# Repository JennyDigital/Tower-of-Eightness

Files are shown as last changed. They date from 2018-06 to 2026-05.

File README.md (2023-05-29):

# Tower-of-Eightness

Welcome to my play project of a homebrew computer based on the 6502 CPU used in many many home computers of the 80's.  This isn't meant to be a guide to how you should build a 6502 based computer but it is meant to be fun and it does work.  I had never done one before so there's lots to improve upon I'm sure and I would love to hear of any exploits or builds similar to or the same as mine.

P.S.  I am planning to bring BBC BASIC to this system as it's sooooo good.

P.P.S.  I will be continuing to develop this machine for some time especially over weekends.

Have Fun!

*JenniferDigital.*

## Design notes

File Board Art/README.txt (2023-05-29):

This board art is only for the bottom side.  I'm eager to get my projects out fast and make my boards single sided (usually), adding links to the topside where neccesary for which the EAGLE files will let you see where they go.  Some of my newer boards can't easily be made single sided and as such may have to be fabricated with great care or many bodgewires.  Those boards don't have pre-made board mask art here, but the EAGLE files are included.

Have Fun,

Jennifer Gunn. x

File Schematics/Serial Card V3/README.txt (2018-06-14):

Serial Card V3
==============

Please note, this card is very much a work-in-progress!

I have not implemented any driver code for it whatsoever and may not have pushed all the updates to it's schematic.

IT MAY NOT WORK AT ALL!!

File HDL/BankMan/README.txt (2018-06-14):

Memory Board V2 Bank management logic.

Burn this to a GAL22V10 for the Memory board V2.

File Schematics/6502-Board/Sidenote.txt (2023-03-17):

For many people, this board will be essential.  If you go for the Motherboard V3.1 with it's integral CPU, you won't also want this card.  It makes no sense to have two processors fighting for the same bus.  There is no bus arbitration.

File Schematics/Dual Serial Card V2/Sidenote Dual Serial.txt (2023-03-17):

This is now the standard serial card as Tower OS has some builtin features for it and slots are at a premium.  TowerOS will still operate with a single ACIA and so will this card if you so desire, but two is definitely better than one in this case.

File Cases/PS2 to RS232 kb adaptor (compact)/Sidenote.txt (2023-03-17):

If your keyboard sips power at 300mA or less, or you use a switching 7805 replacement regulator, use this case, otherwise bet on the bigger one.  The bigger one was drawn with a newer version of FreeCAD too which might help if you plan on modifying it.

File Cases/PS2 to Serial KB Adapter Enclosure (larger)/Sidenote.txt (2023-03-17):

This is the bigger version.  Done this way to facilitate a larger heatsink for if your keyboard is somehow a power hog and you plump for the traditional linear regulator.  This one is also drawn with FreeCAD 20.2 which at the time of writing is quite new.

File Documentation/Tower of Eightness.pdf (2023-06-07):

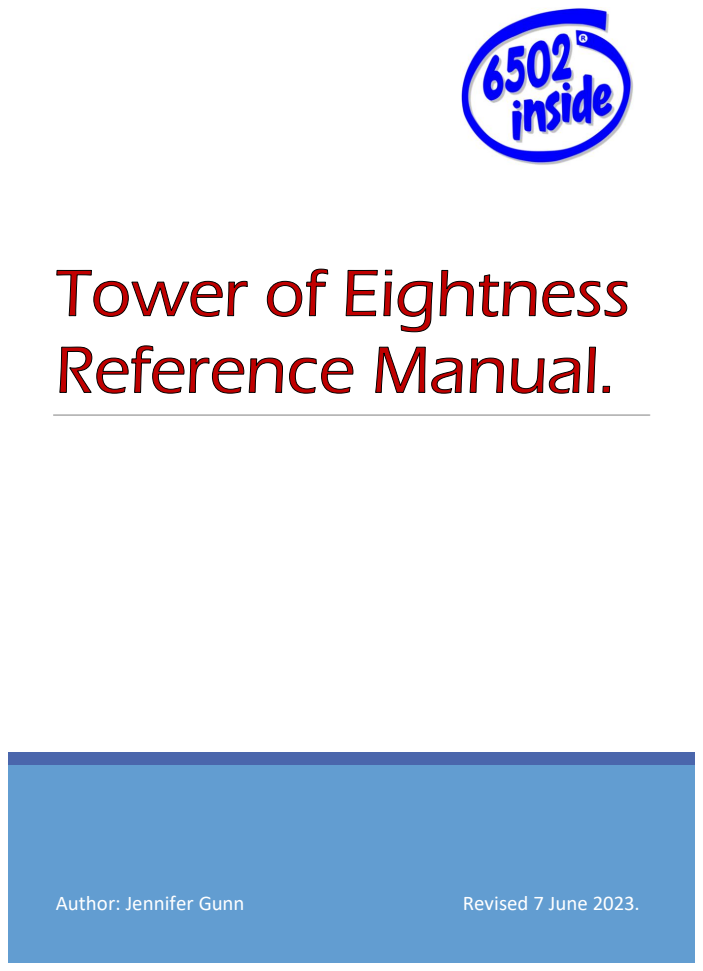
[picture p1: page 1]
Author: Jennifer Gunn; Revised 7 June 2023.

TOWER OF EIGHTNESS REFERENCE MANUAL.

### Table of Contents

TowerBASIC Commands for I2C communications | 82
List of I²C-Bus Subsystem Variables | 83
I2C_Status ($5D0) Bitfield | 83
I2C-Subsystem Calls | 83
Chapter 16. The SPI Sub-system | 84
SPI Subsystem Description | 85
TowerBASIC SPI Support | 86
Using the SPI engine | 87
SPI_Struct ($400-$408) | 87
List of SPI Function Calls | 87
Table of SPI Modes | 87
Appendices | 88
Appendix A. PC-DOS Character Set | 89
Appendix B. Display Layout | 90
80 Column Mode (Text) | 90
40 Column Mode (Text) | 90
Graphics (Bloxel Graphics) | 90
Appendix C. Video Control Codes | 91
Appendix D. Character Control Bits | 92
Character Control Attribute $18 (24) and bitfield of following byte | 92
Appendix E. ANSI Card Register Table | 93
Appendix F. Tower of Eightness Memory Overview | 94
Bank Structure and IOMAP oveview | 94
Bank Select Register Bitfield ($C0FF) | 94
Appendix G. AY Hardware Details | 95
AY-3-8912A Register Map | 95
Table of Bus States | 95
Envelope Shape/Cycle Operation | 96
Appendix H. Pinouts | 97
TowerBUS Pinout | 97
Centronics Port Pinout | 97
GPIO Card Port Pinouts | 97
ACIA Port Pinout | 98
Joystick Port Pinout | 98
AY Soundcard Output Jack Pinout | 98
Appendix I. W65C02 Instruction List | 99
Appendix J. Alphabetic List of TowerBASIC Commands | 101
BITCLR <addr>,<b> | 101
BITSET <addr>,<b> | 101
CALL <addr> | 101
CAT | 101
CLEAR | 101
CLS [<b>] | 101
CONT | 101
DATA [{r|$}[,{r|$}]…] | 102

DEC <var>,[<var>] | 102
DEF FN <name>(<var>)=<statement> | 102
DIM <var[$](i1[,i2[,in]…]) | 102
DO | 102
DOKE <addr,w> | 102
ELSE | 102
END | 103
ENVELOPE <period>,<mode> | 103
FN <name>(<expression>) | 103
FOR <var>=<expression> TO <expression> [STEP <expression>] | 103
GET <var[$]> | 103
GOSUB <n> | 103
GOTO <n> | 103
I2C_INIT | 105
I2C_START | 105
I2C_STOP | 105
IF <expression> {GOTO <n> [THEN <n|statement}>} [ELSE<{n|statement}>] | 105
INC <var>[,var] | 105
INPUT [“$”;]<var>[,<var>] | 105
LET <var>=<expression> | 106
LIST [n1][-n2] | 106
LOAD <expression$> [<expression>] | 106
LOCATE <expr1>,<expr2> | 106
LOOP [{UNTIL|WHILE} <expression>] | 106
NEW | 106
NEXT [var[,var]…] | 107
NOT <expression> | 107
NULL <n> | 107
ON <expression> {GOTO|GOSUB} <n>[,n] | 107
PLOT <expr1>,<expr2>,<expr3> | 107
POKE <addr,b> | 107
PRINT [<expression>][;|,}[expression]…[{;|,}] | 108
READ <var>[,<var>] | 108
REM | 108
RESTORE [n] | 108
RETURN | 108
RUN [n] | 108
SAVE <expression$> [<addr>,<size>] | 109
SOUND <channel>, <period>, <volume> | 109
SPC(<expression>) | 109
SPI_INIT <mode>,<MOSI_P>,<MISO_P>,<SCK_P>,<SS_P>,<SS_act> | 109
STEP | 109
SWAP <var[$]>,<var[$]> | 109
TAB(<expression>) | 110
THEN | 110
TO | 110
UNTIL | 110
VERIFY <filename$> [<addr>] | 110
WAIT <addr>,b1>[,b2] | 110
WHILE | 110
WIDTH {b1|,b2|b1,b2} | 111
Appendix K. List of Functions | 112
ABS(<expression>) | 112
ASC(<expression$>) | 112
ATN(<expression>) | 112
BIN$(<expression>[,b]) | 112

BITTST(<addr>,<b>) | 112
CHR$(b) | 112
COS(<expression>) | 112
DEEK(<addr>) | 112
EXP(<expression>) | 113
FRE(<expression>) | 113
HEX$(<expression>[,b]) | 113
I2C_IN(<b>) | 113
I2C_OUT(<b>) | 113
INT(<expression>) | 113
LCASE$(<expression$>) | 113
LEFT$(<expression$,b>) | 113
LEN(<expression$>) | 113
LOG(<expression>) | 114
MAX((<expression>[,<expression]…) | 114
MID$(<expression$,b1>[,b2]) | 114
MIN(<expression>[,<expression>]…) | 114
PEEK(<addr>) | 114
PI | 114
POS(<expression>) | 114
RIGHT$(<expression$,b>) | 114
RND(<expression>) | 115
SADD(<{var$|var$()}>) | 115
SGN(<expression>) | 115
SIN(<expression>) | 115
SPI_XFER(<b>) | 115
SQR(<expression>) | 115
STR$(<expression>) | 115
TAN(<expression>) | 115
TWOPI | 116
UCASE$(<expression$>) | 116
USR(<expression>) | 116
VAL(<expression$>) | 116
VARPTR(<var[$]>) | 116
Appendix L. List of Error Messages | 117
Array bounds Error | 117
Break | 117
Can’t continue Error | 117
Divide by zero Error | 117
Double dimension Error | 117
Extra ignored (INPUT warning) | 117
Filename too Long | 117
Function call Error | 118
Header Error. Retrying | 118
Illegal direct Error | 118
LOOP without DO Error | 118
NEXT without FOR Error | 118
Out of DATA Error | 118
Out of memory Error | 118
Overflow Error | 119
Redo from start | 119
RETURN without GOSUB Error | 119
String too complex Error | 119
String too long Error | 119
Syntax Error | 119
Tape loading Error | 119

# Chapter 0. Introduction to

the Tower of Eightness.

### Welcome

You are now the proud owner of one of the most trailing edge pieces of technology. This sophisticated, versatile, and very capable engineering tool/toy is built for those with a need to play around, make and learn unimpeded by modern technologies closed-off and locked down architectures.

The Tower of Eightness has despite its trailing edge tech, enough capability to run an office, teach the basics of robotics, play games etc. The power is within you to make it do great things. Everything is documented where possible in order to make it the tinkerers heaven. There is just one thing I ask of you. When you make something beautiful, share it!

### A Guided tour

First, let’s learn the pieces. The main unit consists of a 3D printed modular case which houses the backplane, of which there are versions with and without the W65C02S6-TPG14 Central Processing Unit and system clock generator. The W65C02S6-TPG14 is the beating heart of the system, and it can be considered to be its brain.

Then there is the memory card. On this card is 96 Kibibytes of RAM in three banks of 16 Kibibytes by 2 pages wide. At the top of memory space are two pages of ROM each also of 16 Kibibytes. This is where TowerOS, TowerBASIC and TowerTAPE FS live. This card is an essential without which the computer will not operate. It is recommended that this sits in the top slot if one intends to make frequent changes to the ROM.

Next up is the GPIO card. You need at least one of these to use TowerTAPE FS, SPI or I

2C facilities. The first one should always be at $C020 base address.

Either an ACIA card or a dual ACIA card (recommended) is needed to provide one or more serial ports. All keyboard input is initially routed through the first serial port and on systems’ that don’t have some form of VDU output, this is how one sees the computers output.

In most cases you’ll want a video output with some form of graphics, for this there is the ANSI video output card. With this, you’ll be able to enjoy 80 columns output, a full PCDOS character set and some limited graphics capability. This card outputs either PAL or NTSC timed monochrome composite synch video.

Do you want to make some noise!!? Good, there’s a soundcard based on the AY-3-8912A sound chip for that. It has a single stereo 3.5mm jack with line level output on it.

How about printing? For that there is the Centronics and Tower Peripheral Bus card. The printer port is especially useful. The Tower Peripheral Bus hardware is all there, but the firmware is a work in progress.

There is an up-and-coming much faster solid state storage card, this will operate with far greater reliability and speed than tape.

### Getting Up and Running

Firstly, we need power. On the back is a 2.1mm power jack that accepts anything from 8 to 12VDC positive tip with at least 1A. Whilst the computer itself doesn’t use all that, peripherals and future upgrades might. Plug that in but don’t switch the computer on just yet.

Now, connect the ACIA port 1 to either a terminal/terminal emulator or the PS2 keyboard interface with the appropriate lead. For connecting to the keyboard interface, use the supplied SC1-K1 serial cable. It only fits one way round. For use with the terminal/terminal emulator you will need to make up a custom cable using the data in one of the ACIA adapter chapters. If using the PS2 to Keyboard adapter, you will need to supply power to that also. See the PS2 to Keyboard Adapter User Guide for further guidance there. We now have a way to type commands into the computer and if using it with a terminal, also see the output.

It is strongly recommended that you use the ANSI card with a composite capable display device. This wat you can enjoy its extra benefits. The output on that card is a single yellow RCA jack. This outputs either 50 or 60Hz monochrome video compatible with many modern television sets that support PAL or NTSC.

Should you wish to use TowerTAPE FS then you should now use a short and I do mean short 20-way ribbon cable to connect port B of the first GPIO card to the tape and joystick interface. This also supplies power to the tape and joystick interface, so you won’t need yet another power supply.

These are considered the base options for the Tower of Eightness. Some might say sound is a base option, but that very much depends on your point of view. Now we can flip the power switch!

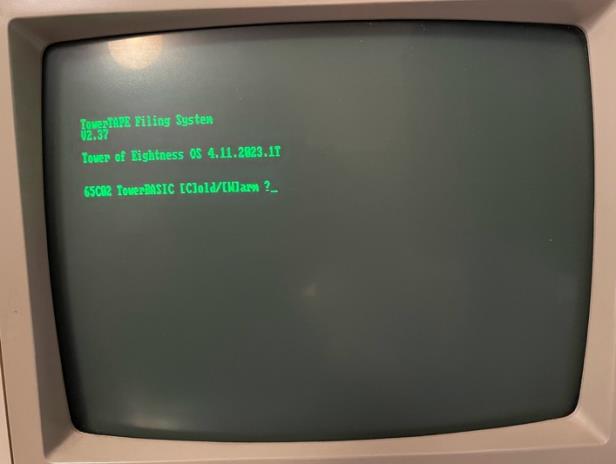
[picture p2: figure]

When starting from power-up you must always choose [C]old by pressing C. You will then be prompted to enter an amount of memory. For now just press [ENTER] and let the computer decide. This will drop you into TowerBASIC.

Let the adventure begin!

Figure 1 ToE Boot-screen

Let’s get stuck in shall we? Good, TowerBASIC is a close fork of EhBASIC, it is therefore derived from EhBASIC, and due respect should be paid to its original and late author Lee Davidson. It is free to use but not copyright free. He would hate to see people abusing the spirit and intention of his work, so please don’t. Now with that out of the way, BASICs of this type have a few things in common.

First, there are keywords such as PRINT, IF and LET which will appear throughout this manual as they do here. Take the following example for instance: -

### 10 PRINT “Hello world!”¶ 20 GOTO 10¶

Typing this and then RUN¶ tells the computer to print Hello world! repeatedly down the screen. To stop it doing so press escape or [Control]C, from now on shown ^C.

The numbers at the start of each line tell the computer where to put them in relation to each other, and each line is followed in numerical order. If you type a new line in with the same number, it replaces any existing one of the same line number with the new line. Try changing the message in the quotes on line 10 and see what happens!

Where you see PRINT that command prints whatever is between the quotes.

Line 20 does something different. It is an instruction to start running commands from the number following the GOTO command. In this simple form it must be followed by a line number that must exist or the computer will stop running your program with an Undefined statement Error.

Congratulations, you’ve just run your first program!

It would be a shame to have to type in an entire program consisting of many many lines of carefully crafted code, so connect your Tower of Eightness up to a tape recorder and whenever you have created something you’d rather not loose, just find a good spot on a tape, press record and type SAVE “<filename>”¶

When the computer has done saving you’ll be greeted by the Ready prompt and be able to continue on with your day. Getting your program back is as simple as finding the right spot and typing LOAD ”<optional filename>”¶, and playing the tape back. It may take a while to find the sweet spot on your tape recorders volume dial to get reliable loading of saved programs. Please refer to the chapter on the Tape and Joystick Interface for a fuller understanding.

### Variables and Math

So, computers are often insulted as being overgrown calculators, and whilst this is not true, they definitely owe their roots to the efforts of mathematicians and engineers.

The Tower of Eightness is quite capable of performing calculations with great speed and ease. Just to give you a taste, let’s explore this a little.

Let us consider the following program: -

### 10 LET a=4 20 LET b=3 30 PRINT a*b

Upon being RUN this program produces the result 12. Nothing remarkable you might say, but the devil is in the detail for computers don’t work in human numbers (decimal), they work in binary (noughts and ones, also known as base 2).

Line 10 assigns the variable ‘a’ with the value 4, whenever the computer then needs to use that number, you can use ‘a’ instead. In fact, you can change the contents of a whenever you like and even assign it the results of a previous calculation. The computer is taking an equation, in this case a times b and PRINTing the result.

Line 20 is doing the same for the variable b, but not b=3.

Line 30 both performs the calculation and prints the result for the user to see.

For the Tower of Eightness, this was a trivial calculation that took such a short time I bet you didn’t even perceive it. The computer has a good selection of operators.

It can add (+), subtract (-), multiply (*), divide (/), raise to a power (^) and much, much more. The TowerBASIC Reference Manual gives a full list of operators and functions to assist the programmer in making use of the computers calculating capability.

There are also string variables, and arrays of variables can exist as well.

Any variable name that ends in s ‘$’ symbol is a string variable. Strings are any number of characters one after another and can have some limited operations after them. We shall just briefly touch upon them here. To know more, refer to the TowerBASIC Reference Manual.

N$=”<Yourname>”
PRINT “Hello “;N$;”. It’s jolly nice to meet you!”

### Using the PRINT Command

You’ve seen PRINT in use already, but did you know, it can do more? In fact, when properly used, it can do most of what you might want to do with the Tower of Eightness display. Its purpose is more fully realised when you know the PC-DOS character set and special control codes that give it the ability to draw pixels, double height, double width, bold or otherwise characters sets and even change the number of columns on the screen.

PRINT can exist on its own to move down the screen by one line:-

### 10 PRINT “MENU” 20 PRINT 30 PRINT “Spam and eggs” 40 PRINT “Spam and chips” 50 PRINT “Spam, spam, spam, wonderful Spam!!”

PRINT can print multiple things together!

### 10 LET a=9 20 PRINT “The square root of”;a;” is”;SQR(a)

which yields the result of ‘The square root of 9 is 3‘ when run. We’ve also just encountered a function SQR() which returns the square root of whatever is in the parentheses. There are many such functions.

One such function especially useful with PRINT is CHR$(). It takes a number from 0 to 255 and passes the result as a single character. If you look at the PC-DOS character set, listed at the back of this manual, you will see that each and every character has a unique number associated with it, and better yet, there’s also a whole bunch of fancy symbols to play with as well! A word of caution though, it is quite possible to get the screen in a terrible mess whilst exploring this, so don’t forget that if you press the reset button and choose [W]arm start, you’ll have a nice readable display to call home again.

PRINT can also produce columnated figures. Try the following: -

PRINT 1,2,3,4

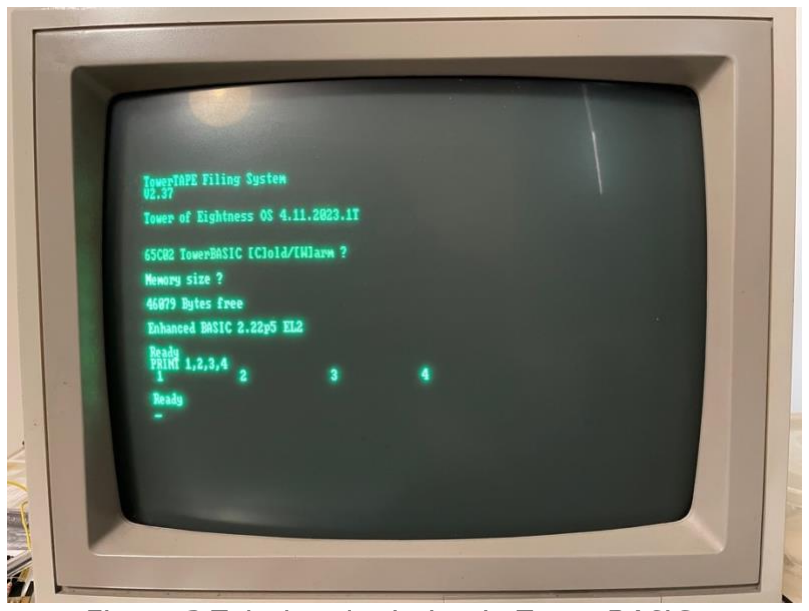
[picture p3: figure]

Figure 2 Tabulated printing in TowerBASIC.

As you can see from the above image, there are fixed tabs where the numbers appear. This is useful for making your information sit more readably and presentably.

There are a couple of useful functions for moving whatever you print along too. Following the print statement or after a ‘,’ or ‘;’ within the PRINT statement, you can include either a SPC(x) or TAB(x) function where x is a positive numeric value.

SPC(x) works by moving the print position x characters along, but TAB(x) attempts to get to column x so long as that column hasn’t already been passed.

Finally, if you end your print statement with a semicolon, a carriage return is not issued. That is to say that the next thing starts immediately after the last print.

Chapter 1. The Zero Page.

### Tower of Eightness Zero Page Usage

LAB_WARM | $00 | BASIC warm start entry point
Wrmjpl | $01 | BASIC warm start vector jump low byte
Wrmjph | $02 | BASIC warm start vector jump high byte
Usrjmp | $0A | USR function JMP address
Usrjpl | $0B | USR function JMP vector low byte
Usrjph | $0C | USR function JMP vector high byte
Nullct | $0D | nulls output after each line
TPos | $0E | BASIC terminal position byte
TWidth | $0F | BASIC terminal width byte
Iclim | $10 | Input column limit
Itempl | $11 | Temporary integer low byte
Itemph | $12 | Temporary integer high byte
nums_1 | $11 | Number to bin/hex string convert MSB
nums_2 | $12 | Number to bin/hex string convert
nums_3 | $13 | Number to bin/hex string convert LSB
Srchc | $5B | Search character
Temp3 | $5B | Temp byte used in number routines
Scnquo | $5C | Scan-between-quotes flag
Asrch | $5C | Alt search character
XOAw_l | $5B | eXclusive OR, OR and word low byte
XOAw_h | $5C | eXclusive OR, OR and AND word high byte
Ibptr | $5D | Input buffer pointer
Dimcnt | $5D | # of dimensions
Tindx | $5D | Token index
Defdim | $5E | Default DIM flag
Dtypef | $5F | Data type flag, $FF=string, $00=numeric
Oquote | $60 | Open quote flag (b7) (Flag: DATA scan; LIST quote;
| | memory)
Gclctd | $60 | Garbage collected flag
Sufnxf | $61 | Subscript/FNX flag, 1xxx xxx = FN(0xxx xxx)
Imode | $62 | Input mode flag, $00=INPUT, $80=READ
Cflag | $63 | Comparison evaluation flag
TabSiz | $64 | TAB step size (was input flag)
next_s | $65 | Next descriptor stack address

These two bytes form a word pointer to the item currently on top of the descriptor stack.

last_s | $66 | Last descriptor stack address low byte
last_sh | $67 | Last descriptor stack address high byte (always $00)
des_sk | $68 | Descriptor stack start address (temp strings)

| $70 | End of descriptor stack
ut1_pl | $71 | Utility pointer 1 low byte
ut1_ph | $72 | Utility pointer 1 high byte
ut2_pl | $73 | Utility pointer 2 low byte
ut2_ph | $74 | Utility pointer 2 high byte
Temp_2 | $71 | Temp byte for block move
FACt_1 | $75 | FAC temp mantissa1
FACt_2 | $76 | FAC temp mantissa2
FACt_3 | $77 | FAC temp mantissa3
dims_l | $76 | Array dimension size low byte
dims_h | $77 | Array dimension size high byte
TempB | $78 | Temp page 0 byte
Smeml | $79 | Start of mem low byte (Start-of-Basic)
Smemh | $80 | Start of mem high byte (Start-of-Basic)
Svarl | $7B | Start of vars low byte (Start-of-Variables)
Svarh | $7C | Start of vars high byte (Start-of-Variables)
Sarryl | $7D | Var mem end low byte (Start-of-Arrays)
Sarryh | $7E | Var mem end high byte (Start-of-Arrays)
Earryl | $7F | Array mem end low byte (End-of-Arrays)
Earryh | $80 | Array mem end high byte (End-of-Arrays)
Sstorl | $81 | String storage low byte (String storage (moving down))
Sstorh | $82 | String storage high byte (String storage (moving down))
Sutill | $83 | String utility ptr low byte
Sutilh | $84 | String utility ptr high byte
Ememl | $85 | End of mem low byte (Limit-of-memory)
Ememh | $86 | End of mem high byte (Limit-of-memory)
Clinel | $87 | Current line low byte (Basic line number)
Clineh | $88 | Current line high byte (Basic line number)
Blinel | $89 | Break line low byte (Previous Basic line number)
Blineh | $8A | Break line high byte (Previous Basic line number)
Cpntrl | $8B | Continue pointer low byte
Cpntrh | $8C | Continue pointer high byte
Dlinel | $8D | Current DATA line low byte
Dlineh | $8E | Current DATA line high byte
Dptrl | $8F | DATA pointer low byte
Dptrh | $90 | DATA pointer high byte
Rdptrl | $91 | Read pointer low byte
Rdptrh | $92 | Read pointer high byte
Varnm1 | $93 | Current var name 1st byte

Varnm2 | $94 | Current var name 2nd byte
Cvaral | $95 | Current var address low byte
Cvarah | $96 | Current var address high byte
Frnxtl | $97 | Var pointer for FOR/NEXT low byte
Frnxth | $98 | Var pointer for FOR/NEXT high byte
Tidx1 | $97 | Temp line index
Lvarpl | $97 | Let var pointer low byte
Lvarph | $98 | Let var pointer high byte
Prstk | $99 | Precedence stacked flag
comp_f | $9B | compare function flag, bits 0,1 and 2 used
| | Bit 2 set if >
| | Bit 1 set if =
| | Bit 0 set if <
func_l | $9C | Function pointer low byte
func_h | $9D | Function pointer high byte
garb_l | $9C | Garbage collection working pointer low byte
garb_h | $9D | Garbage collection working pointer high byte
des_2l | $9E | String descriptor_2 pointer low byte
des_2h | $9F | String descriptor_2 pointer high byte
g_step | $A0 | Garbage collect step size
Fnxjmp | $A1 | Jump vector for functions
Fnxjpl | $A2 | Functions jump vector low byte
Fnxjph | $A3 | Functions jump vector high byte
g_indx | $A2 | Garbage collect temp index
FAC2_r | $A3 | FAC2 rounding byte
Adatal | $A4 | Array data pointer low byte
Adatah | $A5 | Array data pointer high byte
Nbendl | $A4 | New block end pointer low byte
Nbendh | $A5 | New block end pointer high byte
Obendl | $A6 | Old block end pointer low byte
Obendh | $A7 | Old block end pointer high byte
Numexp | $A8 | String to float number exponent count
Expcnt | $A9 | String to float exponent count

Numbit | $A8 | Bit count for array element calculations
Numdpf | $AA | String to float decimal point flag
Expneg | $AB | String to float eval exponent -ve flag
Astrtl | $AA | Array start pointer low byte
Astrth | $AB | Array start pointer high byte
Histrl | $AA | Highest string low byte
Histrh | $AB | Highest string high byte
Baslnl | $AA | BASIC search line pointer low byte
Baslnh | $AB | BASIC search line pointer high byte
Fvar_l | $AA | Find/found variable pointer low byte
Fvar_h | $AB | Find/found variable pointer high byte
Ostrtl | $AA | Old block start pointer low byte
Ostrth | $AB | Old block start pointer high byte
Vrschl | $AA | Variable search pointer low byte
Vrschh | $AB | Variable search pointer high byte
FAC1_e | $AC | FAC1 exponent
FAC1_1 | $AD | FAC1 mantissa1
FAC1_2 | $AE | FAC1 mantissa2
FAC1_3 | $AF | FAC1 mantissa3
FAC1_s | $B0 | FAC1 sign (b7)
str_ln | $AC | String length
str_pl | $AD | String pointer low byte
str_ph | $AE | String pointer high byte
des_pl | $AE | String descriptor pointer low byte
des_ph | $AF | String descriptor pointer high byte
mids_l | $AF | MID$ string temp length byte
negnum | $B1 | String to float eval -ve flag
numcon | $B1 | Series evaluation constant count
FAC1_o | $B2 | FAC1 overflow byte
FAC2_e | $B3 | FAC2 exponent
FAC2_1 | $B4 | FAC2 mantissa1
FAC2_2 | $B5 | FAC2 mantissa2
FAC2_3 | $B6 | FAC2 mantissa3
FAC2_s | $B7 | FAC2 sign (b7)
FAC_sc | $B8 | FAC sign comparison, Acc#1 vs #2
FAC1_r | $B9 | FAC1 rounding byte

ssptr_l | $B8 | String start pointer low byte
ssptr_h | $B9 | String start pointer high byte
sdescr | $B8 | String descriptor pointer
csidx | $BA | Line crunch save index
Asptl | $BA | Array size/pointer low byte
Aspth | $BB | Array size/pointer high byte
Btmpl | $BA | BASIC pointer temp low byte
Btmph | $BB | BASIC pointer temp low byte
Cptrl | $BA | BASIC pointer temp low byte
Cptrh | $BB | BASIC pointer temp low byte
Sendl | $BA | BASIC pointer temp low byte
Sendh | $BB | BASIC pointer temp low byte
LAB_IGBY | $BC | Get next BASIC byte subroutine
LAB_GBYT | $C2 | Get current BASIC byte subroutine
Bpntrl | $C3 | BASIC execute (get byte) pointer low byte
Bpntrh | $C4 | BASIC execute (get byte) pointer high byte
| $D7 | end of get BASIC char subroutine
Rbyte4 | $D8 | Extra PRNG byte
Rbyte1 | $D9 | Most significant PRNG byte
Rbyte2 | $DA | Middle PRNG byte
Rbyte3 | $DB | Least significant PRNG byte
| $DC | unused
| $DD | unused
| $DE | unused
| $DF | unused
| $E0 | unused
| $E1 | unused
| $E2 | TPB card temporary location
| $E3 | TPB card temporary location
| $E4 | TAPE temporary location
| $E5 | TAPE_BlockLo
| $E6 | TAPE_BlockHi
| $E7 | TOE_MemptrLo low byte general purpose pointer
| $E8 | TOE_MemptrHi high byte general purpose pointer
| $E9 | unused
| $EA | unused
| $EB | unused
| $EC | unused
| $ED | unused
| $EE | unused

Decss | $EF | Number to decimal string start
Decssp1 | $F0 | Number to decimal string start
| $FF | Decimal string end

Chapter 2. OS Memory Map.

### TowerBASIC Non-Zero Page Memory

Operating systems memory is necessary, or the OS would not work. Some benefit to the user is afforded by the clear documentation of this memory below.

$200 | ccflag | Control-C flag. 0=Enabled, 1=Disabled.
$201 | ccbyte | Control-C character. One may define whatever
| | one chooses, but with great power comes great
| | RESETs!
$202 | ccnull | Timeout time for the Control-C character.
$203-$204 | VEC_CC | Control-C check vector.
$205-$206 | VEC_IN | TowerBASIC Input vector.
$207-$208 | VEC_OUT | TowerBASIC output vector.
$209-$20A | VEC_LD | TowerBASIC LOAD vector.
$20B-$20C | VEC_SV | TowerBASIC SAVE vector.
$20D-£20E | VEC_VERIFY | TowerBASIC VERIFY vector.

THE Next two vectors (Greyed out) are no longer in use.

$F9F3-$F9F4 | IRQ_vec | Interrupt ReQuest vector. (Currently patched out,
| | see Chapter 12, The IRQ Sub-System.)
$20F-$210 | NMI_vec | Non Maskable Interrupt vector.

### ToE Monitor Top Level Component Memory

$5E0 | os_outsel | Output stream selection bitfield. See table at end of
| | chapter.
$5E1 | os_infilt | Input stream filter selection bitfield. See table at end
| | of chapter.
$5E2 | os_insel | This variable contains an input stream selection bit.
| | The bitfield allows you to select which source you
| | want to use, with invalid selections causing a
| | return to ACIA1.

### ToE ACIA Configuration Variables

$5E3 | ACIA1_cfg_cmd | The load values for configuring ACIA1’s command
| | register upon initialisation.
$5E4 | ACIA1_cfg_ctrl | The load values for configuring the ACIA1’s control
| | register upon initialisation.
$5E5 | ACIA2_cfg_cmd | The load values for configuring ACIA2’s command
| | register upon initialisation.
$5E6 | ACIA2_cfg_ctrl | The load values for configuring ACIA2’s command
| | register upon initialisation.

### ToE I2C Engine Variables

$5D0 | I2C Status | Stores the status of the I2C engine including the
ACK/NAK bit.
$5D1 | I2C_Byte | This is the data register for the I2C engine.

### Tower Peripheral Bus Memory Locations

$5F2 | TPB_curr_dev | TPB Currently selected device ID.
$5F3 | TPB_dev_type | TPB device type.
$5F4 | TPB_last_read | Last read byte from the TPB bus.
$5F5 | TPB_BUS_status | Status word for the TPB bus. Subject to change.
$5F6 | TPB_BUS_tries | Bus device counter, this ensures fewer hangs.
$5F7 | TPB_BUS_lim | Bus countdown timer limit. (Reload value).
$5F8 | TPB_BUS_lenlo | Low byte of the length of the block in or out.
$5F9 | TPB_BUS_lenhi | High byte of the length of the block in or out.
$5FA | TPB_BUS_stlo | Low byte of the start of the block in or out.
$5FB | TPB_BUS_sthi | High byte of the start of the block in or out.
$5FC | TPB_BUS_blk_type | Type of block transfer. See Table below.
$600 | TPB_Dev_table | Device descriptor table.
$610-$6FF | TPB_BUS_IO_buff | Buffer for IO operations on the TPB bus.
$700-$7FF | TPB_BUFFER | Buffer for TPB block operations.

TowerTAPE Filing System Memory.

$900-$901 | V_TAPE_BlockSize | Size of block to transfer to or from tape.
$902 | TAPE_Temp2 | Temporary memory location for TFS
internals.
$903 | TAPE_Temp3 | Temporary memory location for TFS
internals.
$904 | TAPE_Temp4 | Temporary memory location for TFS
internals.
$905 | TAPE_LineUptime | Number of passes the tape system
superloop has made since the tape line rose.
$906 | TAPE_Demod_Status | Demodulated bit status.
$907 | TAPE_Demod_Last | Previous demodulated bit status.
$908 | TAPE_StartDet | Start bit detection status.
$909 | TAPE_RX_Status | Receive engine status bitfield.
$90A | TAPE_BitsToDecode | Down counter of remaining bits to
decode.
$90B | TAPE_ByteReceived | Last byte received by the TFS.
$90C | TAPE_Sample_Position | Countdown timer for bit engine sample
synchronization.

$90D | TAPE_BlockIn_Status | Status register for the F_TAPE_BlockIn
function.
$90E-929 | TAPE_Header_Buffer | This is where the tape header information
is stored for use when SAVEing and LOADing.
$92A | TAPE_CS_AccLo | Tape checksum accumulator low byte.
$92B | TAPE_CS_AccHi | Tape checksum accumulator high byte.
$92C | V_TAPE_Phasetime | Tape phase time variable.

The following variables are allocated for future upgrades to the tape system and ignored for now.

$92D | V_TAPE_Sample_Offset | Sample offset variable. This determines
how far into a bit the sample is taken.
$92E | V_TAPE_Bitlength | How many bits in a word stored on
tape.
$92F | V_TAPE_bitcycles | Number of cycles of the super-loop to a
bit.
$930 | V_TAPE_Verify_Status | Stores the verify status bits used by the
TAPE_VERIFY_vec ($FF7E)
$931-$942 | V_TAPE_Fname_Buffer | Working file name buffer. Stores the
null terminated file name specified in LOAD, SAVE and VERIFY commands.
$943 | V_TAPE_LOADSAVE_Type | Temporary store of what file type is
being worked on by the TAPE file system.
$944-$945 | V_TAPE_Address_Buff | Temporary store of the starting address
being worked on by the TAPE file system.
$946-$947 | V_TAPE_Size_Buff | Temporary store of how big the file
being worked on is.
$948 | V_TAPE_Config | TowerTAPE Filing system configuration
word.
$949-$94B | TAPE_KBD_vec | This stores a JMP, and the address of the
routine needed to check for break to BASIC. This is set whenever a block read operation occurs. The user must change this whenever the input stream is changed and a call is made to F_TAPE_GetByte. This is done by calling F_TAPE_SetKbd_vec ($FFBA)

### AY Soundcard V2 Memory Locations

$A00 | AY_Reg | Register to write to
$A01-$A02 | AY_Data | Contents to be transferred between the
system and the AY-3-8912A when
calling | AY_Userwrite_vec | ($FFD5),

AY_Userwrite_16_vec | ($FFCF),
AY_Userread_vec | ($FFD8) | or
AY_Userread_16_vec ($FFD2).
$A03 | AY_Mask | Contains the shadow copy of the
enable bits for the AY-3-8912A sound channels.
$A04 | AY_Channel | Contains a shadow copy of the channel
specified in the BASIC command SOUND.
$A05-$A06 | AY_Period | Contains a shadow copy of the period
specified in the BASIC command SOUND.
$A07 | AY_Volume | Contains a shadow copy of the volume
specified in the BASIC command SOUND.
$A08-$A09 | AY_Envelope_Period | Contains a shadow copy of the
envelope period specified in the BASIC command ENVELOPE.
$A0C | AY_Envelope_Mode | Contains a shadow copy of the
envelope | mode | specified | in | the
TowerBASIC command ENVELOPE.

### IRQ Handler Subsystem Locations

$A20-$A2F | IRQH_CallList | Table of 8 addresses for the IRQ
Handlers
$A30-$A31 | IRQH_CallReg | Address being worked on by set or clear
calls.
$A32 | IRQH_ClaimsList | bitfield showing which IRQ’s claimed an
interrupt. LSb is IRQ0, MSb is IRQ7
$A33 | IRQH_MaskByte | Selection switch for interrupts. 1 means
on and the order is LSb for IRQ0 through MSb for IRQ7.
$A34 | IRQH_WorkingMask | Used internally when enumerating
IRQs.
$A35 | IRQH_CurrentEntry | Convenience variable informing IRQs
etc which IRQ is currently being handled.
$A36-$A46 | IRQH_Command_Table | 16-byte table consisting of a parameter
followed by the command code. Ordered by ascending IRQ number.

### Countdown Timer IRQ Locations

$A4A-$A4B | CTR_V | Counter. This is the countdown timer’s
present value, decremented each GPIO card Timer 1 IRQ.
$A4C-$A4D | CTR_RELOAD_VAL_V | Counter reload value. Reloads only if
CTR_Reload_En bit (b0) of CTR_Options ($A52) is set.

$A4E-$A4F | CTR_PERIOD_V | Counter period. This is determined to
| | be counted down by one every PHI2
| | clock and after reaching 0 triggers an
| | interrupt that decrements the CTR_V
| | ($A4A-$A4B). Caution, Do not set this
| | extremely low or your computer may
| | become unresponsive.
$A50-$A51 | CTR_External_vec | Contains the address of any call you
| | wish to service upon CTR_V reaching 0.
| | Load this before enabling it which is
| | done by setting CTR_vec_En bit (b1) of
| | CTR_Options ($A52)
$A52 | CTR_Options | Bitfield containing flag bits controlling
| | behaviour of the Countdown timer.

### System Vector Locations

$FF60 | TOE_PrintStr_vec | Prints a null terminated string to the
| | currently selected outputs.
$FF63 | TAPE_Leader_vec | Generates a tape leader signal.
$FF66 | TAPE_BlockOut_vec | Transmits a block of bytes.
$FF69 | TAPE_ByteOut_vec | Transmits a byte.
$FF6C | TAPE_BlockIn_vec | Reads a block of bytes from tape.
$FF6F | TAPE_ByteIn_vec | Reads a byte from tape.
$FF72 | TAPE_init_vec | Initialises the tape system.
$FF75 | TAPE_CAT_vec | Continually scans the tape, outputting
| | the filename and type of any found files.
$FF78 | TAPE_SAVE_BASIC_vec | SAVEs a program to tape.
$FF7B | TAPE_LOAD_BASIC_vec | LOADs a program from tape.
$FF7E | TAPE_F_TAPE_VERIFY_BASIC | VERIFYs a program in memory against
| | what is stored on tape. Can be accessed
| | from TowerBASIC using the VERIFY
| | command.
$FF90 | ANSI_init_vec | Initialises the ANSI card.
$FF93 | ANSI_write_vec | Writes whatever is in the accumulator to
| | the ANSI card.
$FF96 | TPB_init_vec | Initialises the Tower Peripheral Bus card.
$FF99 | TPB_LPT_write_vec | Writes the contents of A to the
| | Centronics port.
$FF9C | TPB_tx_byte_vec | Writes a byte to the tower peripheral
| | bus.
$FF9F | TPB_block_vec | Writes a block of bytes to the tower
| | peripheral bus.
$FFA2 | TPB_ATN_handler_vec | Processes ATN signals generated by TPB
| | peripherals.
$FFA5 | TPB_rx_byte_vec | Reads a byte from the TPB bus.
$FFA8 | TPB_rx_block_vec | Reads a block from the TPB bus.

$FFAB | TPB_Dev_Presence_vec | Checks for the presence of a given
device on the bus.
$FFAE | TPB_Req_Dev_Type_vec | Requests the device report its device
type.
$FFB1 | TPB_dev_select_vec | Selects a device on the TPB. A device
must not respond unless selected.
$FFB4 | TPB_Ctrl_Block_Wr_vec | Writes to a devices control block.
$FFB7 | TPB_Ctrl_Block_Rd_vec | Reads a devices control block.
$FFCF | AY_Userwrite_16_vec | Writes to the specified AY register and
its consecutive register.
$FFD2 | AY_Userread_16_vec | Reads from the specified AY register and
its consecutive register.
$FFD5 | AY_Userwrite_vec | Writes to the specified AY register.
$FFD8 | AY_Userread_vec | Reads from the specified AY register.
$FFDB | IRQH_Handler_Init_vec | Initialises the IRQ Handler sub-system.
$FFDE | IRQH_SetIRQ_vec | Atomically sets an IRQ address in the
handler table.
$FFE1 | IRQH_ClrIRQ_vec | Atomically clears an IRQ to the null IRQ
handler in the specified handler table.
$FFE4 | IRQH_SystemReport_vec | Returns the IRQ Handler subsystem
version and base address of the handler data structure.
$FFE7 | INIT_COUNTDOWN_IRQ | Initialises the countdown timer IRQ.

### CPU Vectors (CPU hard-wired)

$FFFA | NMI_vec | Non-Maskable-Interrupt vector.
$FFFC | RES_vec | Reset vector. This is the reset vector. The
CPU takes the address here as it’s start point.
$FFFE | IRQ_vec | Interrupt request vector. | IRQ’s jump
| | from here.

### System Soft-Switches

System soft switches are bits stored within system variables that control characteristics of the system such as output streams and input filtering. This section is likely to grow with revision changes.

### os_outsel ($5E0)

Bit | 7 | 6 | 5 | 4 | 3 | 2 | 1 | 0
Function | Reserved for future uses. | | | | ACIA2 | TPB LPT | ANSI | ACIA1

### os_infilt ($5E1)

Bit | 7 | 6 | 5 | 4 | 3 | 2 | 1 | 0
Function | Reserved for future uses. | | | | | | ACIA2 LF Filter | ACIA1 LF Filter.

### os_insel ($5E2)

Bit | 7 | 6 | 5 | 4 | 3 | 2 | 1 | 0
Function | Reserved for future uses. | | | | ACIA2 | Reserved | | ACIA1

Chapter 3. The ANSI Card.

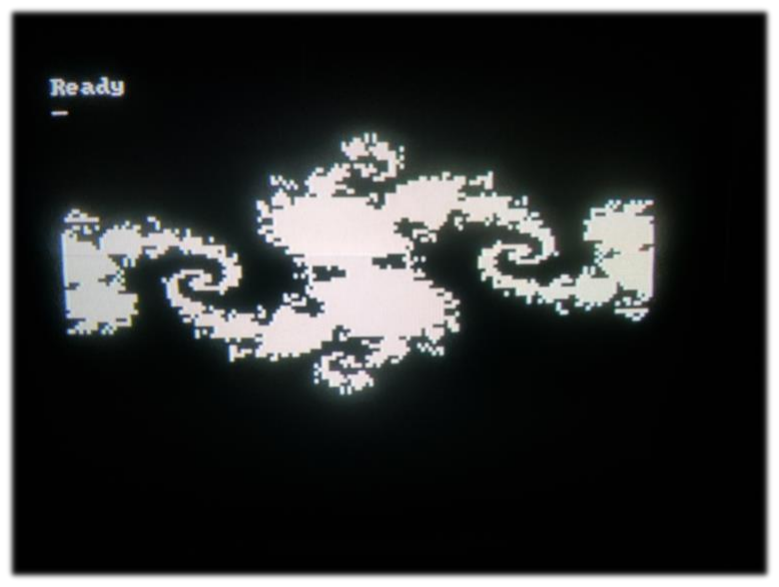
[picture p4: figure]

### ANSI Card Description

ANSI stands for American National Standards Institute, and in this case, we’re dealing with ANSI terminal output.

Each character is put into the card’s internal memory by means of addressing the W65C22S-TPG14 versatile interface adapter on the ANSI card. This card must be set to base address C000-C00F by setting the selector wheel to 0 if one wants to access it via the TowerOS, a second ANSI card could be installed but you must drive it yourself as no OS support is given. To read or set the cards address, just use the number on the wheel as the most significant digit of a two-digit hexadecimal number and add the nIOSEL base address to it.

Refer to the Western Design Center datasheet for operation of the VIA, something which cannot be understated in its importance on the ToE as it is extensively utilised on several add-on cards.

The Avail line is connected to PA6 and indicates the cards availability for use. PA7 is the acknowledge line and flips upon receipt of any byte placed upon port B.

Therefore, the relevant addresses are as per the below table.

Address | ANSI Function
0 | Output byte (Output Register B)
1 | PA7 = Ack, PA6 = Avail, PA5-0 not used. (Output Register A)
2 | Data Direction Register B. Should be set to $FF
3 | Data Direction Register A. Should be set to $40

To write directly to the ANSI processor, one checks the Ack bit and current Avail bit are matching, only changing the content of the data byte when they do. Then, one flips the Avail line. When the ANSI processor has accepted it, both the Ack and Avail lines will match. One can go about one’s merry way but may not change the contents without first checking for agreement.

The nIRQ line of the VIA is not connected to the system bus. If one wishes to use the VIA internal hardware to generate an interrupt, one must use a Schottky diode to wire-or to the appropriate interrupt line. There is nothing stopping one from using the internal timers however, you would just need to poll the registers in software.

Access to the ANSI card through the TowerOS is the recommended method and the following functions below are how this is achieved.

ANSI_init_vec | Call Address: $FF90

Calling this address initialises the ANSI card registers. Normally you won’t need this as TowerOS does this on start-up.

ANSI_write_vec Call Address: $FF93

The contents of the Accumulator is written to the ANSI card. Note that if the ANSI card is still busy, this will function will block until it has completed. There is no timeout, error condition, or filters.

### System Soft switch Control

The system soft switch for this card is in os_outsel ($5E0) and is bit 1. Setting this bit causes the system to send output to the ANSI card and is on by default unless you use the ACIA build of the ToE ROM.

### Controlling the Display

To control the display, one sends control codes which cause the video processor to update the display contents. There is a full set of ASCII characters including extended PC DOS characters and some limited graphics.

Other effects include doubling the width, height of the characters, and whether it is bold.

To control the character width, height and whether it is bold, one sends a character control attribute $18 (24) followed by a byte containing the following bitfield:

### Character Control Attribute $18 (24) and bitfield of following byte

Bit 7 | Bit 6 | Bit 5 | Bit 4 | Bit 3 | Bit 2 | Bit 1 | Bit 0
Graphics | Spare | Spare | Spare | Spare | Double Height | Bold | 80 Columns

### Positioning the Cursor

Issuing control code $0E (14) (set column) or $0F (15) (set row) followed by the desired position achieves this goal. TowerBASIC Also has the LOCATE command which sets both x and y position.

### Redefining the Cursor

Control code $02 (2) followed by the ASCII character desired defines the cursor. If the cursor is set to 0 then it is turned off. Leaving the cursor over a graphical area causes the undesirable effect of making graphical area to flash.

### Accessing the PC DOS Characters ( 0 (0) -- $1F (31) )

To use these extra characters, send $1A (26) first, this causes the next character to be displayed as the specified PC DOS character.

### Simple Graphics

The pixel resolution is 160 across by 100, the origin of which is top left at 0,0 up to 159,99 in the bottom right.

One may issue a SetPixel command $5 (5) or ClearPixel $6 (6) command followed by x then y. TowerBASIC also has the PLOT command to set or clear a pixel.

Please note that there is currently no way to read back what you have on the screen so you will need to keep track of the salient details.

### Writing a Pixel Pattern Directly

Internally, each character cell can be loaded with a 2 by 4 pattern by first sending $80 (128), then the bit pattern is defined by the bit position of the character cell.

### TowerBASIC commands for graphics

There are three commands currently implemented that assist in the use of the ANSI card.

CLS

This clears the screen to a useable state.

LOCATE x,y

Sets the print cursor to position x, y.

PLOT m,x,y

If m is 1 then this sets a pixel at x,y pixel position, but if m is 0 then it clears that pixel.

### Video Control Codes

$01 (01) | Cursor home | (Standard ASCII)
$02 (02) | Define cursor character (2nd byte is the cursor character,
| or 0 to turn off)
$03 (03) | Cursor blinking
$04 (04) | Cursor solid
$05 (05) | Set graphics pixel (next two bytes = x,y)
$06 (06) | Reset graphics pixel (next two bytes = x,y)
$08 (08) | Backspace | (Standard ASCII)
$09 (09) | Tab | (Standard ASCII)
$0A (10) | Linefeed | (Standard ASCII)
$0C (12) | Clear screen | (Standard ASCII)
$0D (13) | Carriage return | (Standard ASCII)
$0E (14) | Set column 0 to 79 (2nd byte is the column number)
| or 0 to 39 for a 40 char line
$0F (15) | Set row 0 to 24 (2nd byte is the row number)
$10 (16) | Delete start of line
$11 (17) | Delete to end of line
$12 (18) | Delete to start of screen
$13 (19) | Delete to end of screen
$14 (20) | Scroll up
$15 (21) | Scroll down
$16 (22) | Scroll left
$17 (23) | Scroll right
$18 (24) | Set font attribute for the current line
$1A (26) | Treat next byte as a character (to allow PC DOS char
codes 1 to 31 to be displayed on screen)
$1B (27) | ESC - reserved for ANSI sequences
$1C (28) | Cursor right
$1D (29) | Cursor Left
$1E (30) | Cursor up
$1F (31) | Cursor down
$20 (32) to…
$7E (126) | Standard ASCII codes
$7F (127) | Delete
$80 (128) to…
$FF (255) | PC (DOS) extended characters

# Chapter 4. The Single ACIA

Card.

### Single ACIA Card Description

Serial communications are provided to permit headless usage, for serial terminals, modems, and many other devices to be connected to the Tower of Eightness. Most notably is keyboard input, the PS2 to Serial interface being the easiest way to control the ToE. Without some way to communicate with the ToE it would be useless and so this is one of the essential interfaces. The default port setting is 9600 baud, 1 start bit, 1 stop bit, no parity and RTS/CTS hardware handshaking.

The 65C51-4P or equivalent Asynchronous Communications Interface Adapter which ACIA stands for, bridges the gap between the system bus and RS232 serial. This card provides a 9 pin RS232 port at the correct signalling levels.

Mark is -Ve and Space is +Ve. Serial data always starts with a start bit, 5 to 8 data bits depending on the setting and at least one stop bits at a regular rate known as the bitrate. The bit rate is not the baud rate as can be realised by considering that the start bit and stop bits take up time also, therefore the baud rate is less than the bitrate by necessity.

Provided below is the pinout of the serial IO DB9 connector which is wired as Data Terminal Equipment. The only handshaking lines provided however are Request-To-Send and Clear-To-Send.

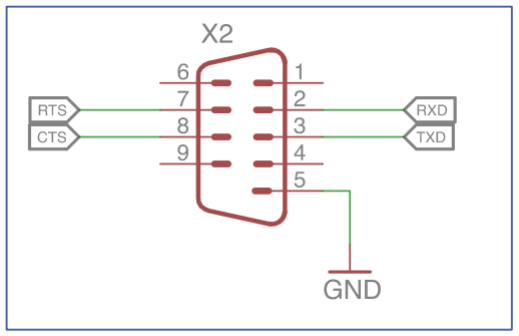
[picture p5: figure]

### Setting the IO Address

To set the IO address one moves jumpers on JP3 to either closed or open positions. Open is a 1 and closed is a 0. There are six of them and they form the top six bits of the IO address offset from nIOSEL which is at $C000. This card occupies four locations in IO address space. The default base address and the one the Tower OS will use is at $C010 meaning that all the jumpers should be set to CCOCCC from back edge to front.

The least significant bit is nearest the bus connector and the most significant furthest away. Whatever binary value is jumpered, just multiply it by four and add the nIOSEL base address.

It is possible to add several ACIA cards, and even mix with dual ACIA cards. but they must not share IO addresses with anything else and at least one must be at $C010 as it receives the keyboard input.

Figure 1

### System Soft switch Control

The system soft switch for output to this card is in os_outsel ($5E0) and is bit 0. Setting this bit causes the system to send output to the ACIA card and is off by default unless you use the ACIA build of the ToE ROM.

There is also a system soft switch for input filtering, which is os_infilt ($5E1). Bit 0 when set to 1 (default is set) strips out linefeed characters ($A).

### ToE ACIA Configuration Variables

$5E3 | ACIA1_cfg_cmd | The load values for configuring ACIA1’s command
| | register upon initialisation.
$5E4 | ACIA1_cfg_ctrl | The load values for configuring the ACIA1’s control
| | register upon initialisation.

The following variables are only applicable if a second ACIA is present at $C014.

$5E5 | ACIA2_cfg_cmd | The load values for configuring ACIA2’s command
| | register upon initialisation.
$5E6 | ACIA2_cfg_ctrl | The load values for configuring ACIA2’s command
| | register upon initialisation.

### ACIA Vectors

TowerOS provides the following vectors for direct access to the ACIAs but the ACIA2 vectors are only relevant if you have a second ACIA at $C014.

ACIA_INI_SYS_vec ($FF42) | Initialises the ACIA system to default values.
| | 8N9600 for both ports.
ACIA1_init_vec ($FF45) | Initialises ACIA1 to the values in ACIA1_cfg_ctrl
| | ($5E4) and ACIA1_cfg_cmd ($5E3) system
variables. | Changing these variables and re-
| | initialising the ACIA can changes the settings.
ACIA2_init_vec ($FF48) | Initialises ACIA2 to the values in ACIA2_cfg_ctrl
| | ($5E6) and ACIA2_cfg_cmd ($5E5) system
variables. | Changing these variables and re-
| | initialising the ACIA can changes the settings.
ACIA1out_vec ($FF4B) | Waits until ACIA1’s transmit buffer is empty then
| | puts the contents of the accumulator into the
| | transmit buffer.
ACIA2out_vec ($FF4E) | Waits until ACIA2’s transmit buffer is empty then
| | puts the contents of the accumulator into the
| | transmit buffer.

# Chapter 5. The Dual ACIA

Card.

### Dual ACIA Card Description

Serial communications are provided to permit headless usage, for serial terminals, modems, and many other devices to be connected to the Tower of Eightness. Most notably is keyboard input, the PS2 to Serial interface being the easiest way to control the ToE. Without some way to communicate with the ToE it would be useless and so this is one of the essential interfaces. The default port setting is 9600 baud, 1 start bit, 1 stop bit, no parity and RTS/CTS hardware handshaking.

The 65C51-4P or equivalent Asynchronous Communications Interface Adapter which ACIA stands for, bridges the gap between the system bus and RS232 serial. This card provides a 9 pin RS232 port at the correct signalling levels.

Mark is -Ve and Space is +Ve. Serial data always starts with a start bit, 5 to 8 data bits depending on the setting and at least one stop bits at a regular rate known as the bitrate. The bit rate is not the baud rate as can be realised by considering that the start bit and stop bits take up time also, therefore the baud rate is less than the bitrate by necessity.

Provided below is the pinout of the serial IO DB9 connectors which are wired as Data Terminal Equipment. The only handshaking lines provided however are Request-To-Send and Clear-To-Send.

### Setting the IO Address

To set the IO address one sets the DIP switches to the appropriate binary address. There are six of them and they form the top six bits of the IO address offset from nIOSEL which is at $C000. This card occupies two sets of four locations in IO address space. The default base address and the one the Tower OS will use for primary input is at $C010 meaning that the appropriate DIP switch setting is 00100. The second ACIA port should be set to $C014 with the DIP switches set to 00101.

The least significant bit is nearest the bus connector and the most significant furthest away. Whatever binary value is jumpered, just multiply it by four and add the nIOSEL base address.

Figure 1

It is possible to add several ACIA cards, but they must not share IO addresses with anything else and at least one must be at $C010 as it receives keystrokes upon start up.

### System Soft switch Control

The system soft switches for output to this card are in os_outsel ($5E0). Bit 0 controls the primary ACIA and bit 3 controls the secondary ACIA. Setting these bits causes the system to send output to the selected ACIA and ACIA 1 is on off default unless you use the ACIA build of the ToE ROM.

There are also system soft switches for input filtering, which are in os_infilt ($5E1). Bit 0 when set to 1 (default is set) strips out linefeed characters ($A) on ACIA 1 and bit 1 (on by default) filters ACIA 2 in the same manner.

### ToE ACIA Configuration Variables

$5E3 | ACIA1_cfg_cmd | The load values for configuring ACIA1’s command
| | register upon initialisation.
$5E4 | ACIA1_cfg_ctrl | The load values for configuring the ACIA1’s control
| | register upon initialisation.
$5E5 | ACIA2_cfg_cmd | The load values for configuring ACIA2’s command
| | register upon initialisation.
$5E6 | ACIA2_cfg_ctrl | The load values for configuring ACIA2’s command
| | register upon initialisation.

### ACIA Vectors

TowerOS provides the following vectors for direct access to the ACIAs.

ACIA_INI_SYS_vec ($FF42) | Initialises the ACIA system to default values.
| | 8N9600 for both ports.
ACIA1_init_vec ($FF45) | Initialises ACIA1 to the values in ACIA1_cfg_ctrl
| | ($5E4) and ACIA1_cfg_cmd ($5E3) system
variables. | Changing these variables and re-
| | initialising the ACIA can changes the settings.
ACIA2_init_vec ($FF48) | Initialises ACIA2 to the values in ACIA2_cfg_ctrl
| | ($5E6) and ACIA2_cfg_cmd ($5E5) system
variables. | Changing these variables and re-
| | initialising the ACIA can changes the settings.
ACIA1out_vec ($FF4B) | Waits until ACIA1’s transmit buffer is empty then
| | puts the contents of the accumulator into the
| | transmit buffer.
ACIA2out_vec ($FF4E) | Waits until ACIA2’s transmit buffer is empty then
| | puts the contents of the accumulator into the
| | transmit buffer.
ACIA1in_vec ($FF51) | Checks ACIA1’s input buffer for received data
| | and if present loads it into the accumulator. If

no data is present, then the accumulator is set to
0. The carry flag is set if successful, otherwise it is cleared.
ACIA2in_vec ($FF54) | Checks ACIA2’s input buffer for received data
| and if present loads it into the accumulator. If
| no data is present, then the accumulator is set to
0. The carry flag is set if successful, otherwise it
| is cleared.

Chapter 6. The GPIO Card.

### GPIO Card Description

This card is basically both ports, complete with CA1, CA2, BA1 and BA2 broken out into two identical sockets. The IRQ line is also connected to assist the programmer with its use.

For those wishing to attach an external peripheral, be it home-made or otherwise, the GPIO card implements not one, but two BBC Micro equivalent user ports. Port B is notably however, used for the cassette and joystick interface and if used for other things may clash with other things. This is true only of this card if it is mapped into a base address of $C040.

### General Configuration

To set its address, one set the jumpers in accordance with the upper nybble of the lower byte of its address and then adds on the nIOSEL offset which is $C000.

Placing the card on a flat surface with the bus connector to the left, moving a jumper to the left represents a binary 0 and to the right is binary 1. CID1 is the least significant bit and CID4 is the most significant bit so the default from CID1 to 4 is left, left, right, left.

### Usage

There are only calls to use port B with the cassette interface and port A with I²C and SPI. To use these, please read the chapter entitled Cassette and Joystick Interface for the cassette, or the chapters on I²C and SPI. The pins for I²C and SPI are not configured until their respective engines are initialised. To take full advantage of this card one needs to write directly to the registers of its VIA chip and so one is directed to the WDC65C22S6-TPG14 datasheet. This is especially important with regards to the VIAs electrical specification as exceeding those may lead to damage to the card and even in some cases the ToE itself.

The some of the pins of the VIA have special features specific to that pin and internal to the VIAs are timers, counters, handshake lines, pulse generators etc.

### Pinout

Be aware that neither of these ports is hot pluggable or protected by any kind of static, or out of specification protection except for the VIAs internal diodes. Also, there is no fuse or other kind of current limiting on the 5V lines. It is up to the user to ensure that the bus is not abused.

19 0V | 17 0V | 15 0V | 13 0V | 11 0V | 9 0V | 7 0V | 5 0V | 3 +5V | 1 +5V
20 PA7 | 18 PA6 | 16 PA5 | 14 PA4 | 12 PA3 | 10 PA2 | 8 PA1 | 6 PA0 | 4 CA2 | 2 CA1
19 0V | 17 0V | 15 0V | 13 0V | 11 0V | 9 0V | 7 0V | 5 0V | 3 +5V | 1 +5V
20 PB7 | 18 PB6 | 16 PB5 | 14 PB4 | 12 PB3 | 10 PB2 | 8 PB1 | 6 PB0 | 4 CB2 | 2 CB1

Port A. Base address offset 1, Data Direction Register Offset 3.

Port B. Base address offset 0, Data Direction Register Offset 2.

# Chapter 7. The AY-3-8912A

Sound Card V2.

“Music speaks what cannot be expressed, sooths the mind and gives it rest,
heals the heart and makes it whole,

# and flows from heaven to the soul.”

### AY Soundcard Description

From the above prose, you might gather that this is a sound card and so it is that you may, with minimal skill produce at least some beeps and squarks. With great skill the chip this sound card is based on has produced some very joyous tunes rejoiced by many a kid of the 80’s.

The Tower of Eightness has a maximum clock speed primarily limited by its peripheral set. As the processor has a design limit of 14MHz and the backplane is good for perhaps 10MHz, only cards that can handle the system clock frequency and do not unduly load the bus may operate correctly as part of the system. One such device to limit the system speed is the AY-3-8912A sound chip which here is clocked locally at 1.842MHz. To that end, this card isolates the sound chip from the main system bus to permit maximum system operating speed. This isolation is achieved by the use of an on card W65C22S VIA chip.

This VIA is mapped into $C0E0 to $C0EF by convention, thereby allowing programs to directly drive it for maximum performance. This is necessary as sound is popular for games amongst other things.

The nIRQ line is connected so that one may use interrupts.

Port B (Offset 0) is connected to the data lines of the AY-3-8912A, and Port A (Offset
1) is used for control lines. PA0 is connected to BC1 whilst PA1 is connected to BDIR. BC2 is tied high therefore creating a simplified bus for the AY chip.

PA0 and PA1 should be set as outputs and their logic should be driven as listed below.

It is important to note that there is currently no logic protection to prevent bus contention between the AY and the VIA chip and the onus is on the programmer to maintain harmony and protect the logic from stressful conditions. More advanced logic will be brought forward at a later date but for now this is all that is required. This has been done with the Oric-1 and Oric Atmos computers and many of those have survived more than 30 years so this is a proven adequate solution.

When BDIR is low, the AY bus is readied for output of its internal registers, and when high it is ready to receive from the bus.

BC1 should remain low until Port A is configured as an input with BDIR low or an output with appropriate data on it and BDIR high. BC1 should be strobed to make the transfer.

The following table should clarify this: -

### Table of Bus States

BC1 | BDIR | State
0 | 0 | Inactive.
1 | 0 | Read from AY. The AY selected register is on the data lines.
0 | 1 | Write to AY. The data lines are transferred to the AY
1 | 1 | Latch Address. Write register address to AY from data lines.

For the full AY-3-8912A hardware specification, refer to the Microchip datasheet.

### Configuration

The only configuration that can be done to this card is to set its base address offset by means of the provided jumpers. The four jumpers are arranged such that the least significant bit is nearest the VIA and the most significant nearest the edge of the card. These jumpers form a binary address that is the most significant four bits of the offset from nIOSEL. Leave the base address at $C0E0 unless this is an additional sound card since software is being targeted at the above agreed address and firmware is being written to use it too.

### Usage from TowerBASIC

There are two commands to make sounds and music on the AY, SOUND and ENVELOPE.

SOUND takes the form below.

SOUND channel, period, volume

where channel is 0 to 6. 0 through 2 are the sound channels A, B and C whilst 3 through 5 is using the same output channels but for noise.

For tones, period is any value from 0 to 4095 with the period being calculated as being 1.842MHz/16/period.

Volume is fixed between 0-15 or if 16 used, it is defined by the ENVELOPE period and mode.

ENVELOPE defines the period and modulation mode of any waveform set to volume
16. The envelope period is in the range of 0-65535 and is calculated as 1.842MHz/256/period. It is unfortunate that the AY contains only one envelope generator and that this affects all sound channels so set equally. If you need to control a sound channels envelope with a differing mode or something more exotic, wouldn’t go far wrong with an interrupt in assembly language, though this negates the use of TowerBASIC whilst the interrupt is in use and consumes further resources.

ENVELOPE period, mode

Here is an example which plays a bell sound at about C5 (523.25Hz).

### 10 SOUND 1, 220,16

### 20 ENVELOPE 24000,0

The Mode Parameter.

The mode parameter is a bitfield containing four bits that control the envelope generator of the AY.

### Mode parameter

Bit 7 | Bit 6 | Bit 5 | Bit 4 | Bit 3 | Bit 2 | Bit 1 | Bit 0
| | | | Continue | Attack | Alternate | Hold

Hold (bit 0) when set, limits the envelope generator to one cycle when set, the value at the end of the cycle being held at the end of the cycle.

Alternate (bit 1) when set, causes the envelope generator to reverse the direction of its cycle when it reaches its end. It thus produces an up-down effect.

Attack (bit 2) when set, causes the envelope generator to count up, and when clear causes it to count down, producing a decay.

Continue (bit 3) when set, causes the cycle pattern to be defined by the hold bit, but when clear causes the counter to reset to 0 after one cycle.

Envelope Table.

The envelope period is limited to 16 different logarithmic values and as such the envelope has significant jumps at the higher volume levels. Luckily, human hearing is also logarithmic.

### Envelope Shape/Cycle Operation

Mode bits (AY reg 13)

B3 | B2 | B1 | B0 Continue | Attack | Alternate | hold

Graphic Representation of Envelope Generator Output.

0 | 0 | X | X
0 | 1 | X | X
1 | 0 | 0 | 0
1 | 0 | 0 | 1
1 | 0 | 1 | 0
1 | 0 | 1 | 1
1 | 1 | 0 | 0
1 | 1 | 0 | 1
1 | 1 | 1 | 0
1 | 1 | 1 | 1

EP

EP is the envelope period (duration of one cycle).

### Register Writes to the AY

To write directly to an AY register one simply pokes the appropriate register address to AY_Reg ($A00) and data to AY_Data ($A01-$A02) and calls the appropriate function call. It is of course possible to drive the AY by directly controlling the W65C22 on the AY card this in fact necessary if you change its address or add a second card. It should be noted that it is far quicker to make these calls than it is to POKE the registers directly, and quicker (and easier) still for many use cases to use the provided TowerBASIC commands. Below is a list of currently implemented function call vectors.

### List of AY function call vectors

AY_Userwrite_16_vec ($FFCF) | Takes a 16-bit word and puts it in the registers
| specified by AY_Reg ($A00) and the consecutive
| register.
AY_Userread_16_vec ($FFD2) | Fetches a 16-bit word from the registers
| specified by AY_Reg ($A00) and the consecutive
| register and places it in AY_Data ($A01-$A02).
AY_Userwrite_vec ($FFD5) | Takes a byte at AY_Data ($A01) and puts it in the
| register specified by AY_Reg ($A00).
AY_Userread_vec ($FFD8) | Fetches a byte from the register specified by
| AY_Reg ($A00) and places it in AY_Data ($A01,
| low byte). The high byte is not overwritten.
AY_Init_vec ($FFCC) | Calling this initialises the AY-3-8912A and its
| associated VIA.

### AY System Memory Locations

AY_Reg ($A00) | Pointer to the AY register to be either written to
| or read from.
AY_Data ($A01-$A02) | Used for transferring data to the above pointed
| register(s). $A01 contains the low byte and
| $A02 the high one. Used by the AY user read
| and write functions provided to make the users’
| usage easier.
AY_Mask ($A03) | Holds a shadow copy of which channels are
| selected.
AY_Channel ($A04) | The retrieved copy of the channel specified by
| the TowerBASIC command SOUND.
AY_Period ($A05-$A06) | The retrieved copy of the period parameter of
| either of TowerBASICs SOUND or ENVELOPE
| commands.
AY_Volume ($A07) | The retrieved copy of the volume specified by
| the TowerBASIC command SOUND.
AY_Envelope_Period ($A08-$A09) | The retrieved copy of the period specified by the
| TowerBASIC command ENVELOPE.

AY_Envelope_Mode ($A0A) | The retrieved copy of the envelope mode
specified | by | the | TowerBASIC | command
ENVELOPE.

# Chapter 8. The Tape &

Joystick Interface.

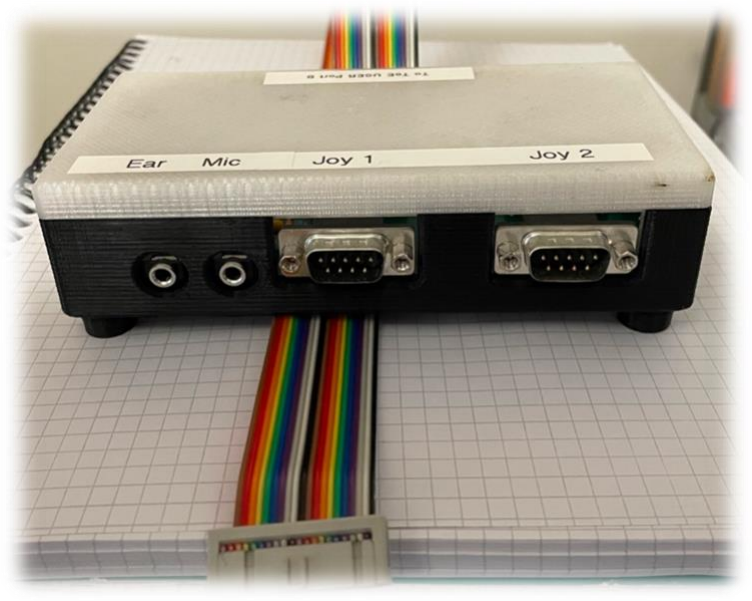
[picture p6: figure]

Figure 3. Tape and Joystick Interface Version 2.

### Tape and Joystick Interface Description

Tape loading, saving and dual Atari style joystick interface are supplied using this interface. It is designed to be connected to a GPIO port and the TowerOS provides support for it through Port B of the GPIO card mapped to the base address of $C040.

One should keep bits 0 and 7 of DDRB $C042 set when using it as these are used to drive the tape output and select which joystick will be read.

The interface is driven by modulating bit 7 to generate a tape signal for SAVE operations. Conversely, bit 6 is used to monitor the state of the audio coming in for LOAD operations.

The tape signal coming in is cleaned up by a biased Schmitt trigger buffer amplifier and fed back to the VIA on pin 6.

The TowerOS provides several system vectors that can be called and has extensive memory locations associated with this interface which will need to be used to make the most of it and are documented later.

To use the joystick interface, one either clears bit 0, selecting joystick port 1 (left) or set it, selecting joystick port 2 (right). The state of the joystick can then be read on Port B bits 1 through 5.

An example fire button read would go something like this: -

### 10 F = NOT(BITTST($C040,5))

The observant amongst you will already have noticed the NOT in that little snippet of TowerBASIC. That is because the joystick ports supply negative logic. A 0 means that switch is pressed.

One should never make the joystick bits outputs as that would prevent access to both joysticks on the affected bits. It won’t however, break anything.

Below is a table of bits associated with the joystick port: -

### Tape and Joystick Bit Usage

Bit 7 | Bit 6 | Bit 5 | Bit 4 | Bit 3 | Bit 2 | Bit 1 | Bit 0
Tape Out | Tape In | Fire | Right | Left | Down | Up | JS Select

### Tape Support in TowerOS

TowerOS supports loading and saving of TowerBASIC from simple LOAD and SAVE commands, but for the advanced user there are system calls and memory locations associated. It should be noted that when you see XXXX XXXX that means that the file is at address XXXX hexadecimal and is XXXX hexadecimal long in that order. Leading zeros are left in to keep the output of ‘CAT‘ neat and regular.

To load an TowerBASIC program simply type ‘LOAD “<optional filename>”¶‘ and play the cassette. Specifying the file name ensures that only that file will be loaded, and the quotes may not be omitted. If the first character of the filename is ‘!’ then it will automatically run upon successful load. This feature can be disabled by clearing the TAPE_AutoRUN_En bit (b1) of V_TAPE_Config ($948). Breaking out of a LOAD can be achieved by pressing ^C.

Under normal circumstances, the display will tell you ‘Searching…’ whilst it is looking for a header, ‘Found BASIC: XXXX XXXX “<Filename>”’ when it finds the specified file and ‘Loading…’ whilst it is loading and ‘Ready’ when it has completed loading. Not giving a file name causes it to load the first file it finds. Should the load encounter an error, you will get the message ‘Tape Loading Error.’.

To save an TowerBASIC program one types ’SAVE “<filename>”¶‘ whilst the cassette is recording. You must include a filename of between 1 and 16 characters in length when saving a file. No checks are made for what those characters are except that a null is used to terminate the string in TowerTAPE FS, so avoid this and other unfortunate characters where possible. Remember, the name you use when saving is the name that will be used to load your program. If it is too awkward, you may be making a rod for your own back, though clever tricks are also possible this way.

The system will tell you it is ‘Saving XXXX XXXX “<Filename>”’ and when done will drop you to the Ready prompt. Adding a ‘!’ to the start of your chosen filename prompts the system to run it when loaded back. This applies to both TowerBASIC programs and binaries. To make a binary execute, ensure your code can run at the location you are loading it to and that it will execute from the first byte. This means that if you load to address xx, it will execute from address xx.

Given the nature of cassette storage, errors are a concern and to ensure the integrity of the saved file, the ‘VERIFY “<optional filename>”¶’ command is included. This will operate very much like the LOAD “” command, but instead reports on the consistency of the SAVEd content with that in RAM, breaking with the VERIFY Error the moment it encounters a byte that either can’t be read or does not match with the one in memory. This step whilst optional, should not be ignored. Many people have been reduced to tears over lost files.

When one gives a specific file name to LOAD or VERIFY, the system ignores any files that do not match the name given or of another file type.

If you should receive an error message, then remedial action will be required. The following error messages and their meanings are listed below.

- Header error. Retrying.
- This means loading error has occurred with the header. TowerTAPE filing system lets you know so you can rewind to the start and try again or escape back to TowerBASIC if you give up.
- Tape loading error.
- This means loading error has occurred with the file block. TowerTAPE filing system drops you back into the TowerBASIC Ready prompt letting you know of the failure.
- Verify Error.
- Receiving this indicates that there is something wrong with the program stored on the cassette and that it will need to be re-done. Consider the quality of the equipment and media in use if this becomes too much of a nuisance.
- Filename Too Long
- Filenames must be no longer than 16 characters and must be present when saving a file.

Listing the Contents of Cassette.

‘CAT¶‘

Starts the catalogue system, printing each file and its type as it is found. This command needs to be escaped by pressing ^C to return control to the system but does not cause a warm start or print upon return. This is so that it may be used from within a program without interrupting flow and it is therefore advised that you provide for this otherwise you may need to perform a restart of the system.

CAT displays ‘Searching…’ followed by the line ‘Found BASIC: XXXX XXXX “<Filename>”’ for each filename found.

Binary File Handling.

To save binary data one does as per the following example: -

‘SAVE “<filename>” $A000, $100¶‘

This would save $100 bytes of data starting at address $A000. If your filename begins with an ! then execution will commence at the load address unless the TAPE_AutoEXEC_En bit (b2) of V_TAPE_Config ($948) is cleared or ^C is used to break and return to immediate mode. To load in binary data, one must specify a load address as in the below example: -

Loading is accomplished as follows: -

‘LOAD “<optional filename>” $A000¶‘

And to verify the integrity of the data saved: -

‘VERIFY “<optional filename>” $A000¶‘

Note that there is no comma separating the address from the filename, it is not needed. One does have to specify the load address at present, as there is currently no other way to indicate that the binary file should be loaded at other than its original address. This feature may be subject to change.

Pressing ^C whilst verifying will break into immediate mode.

### List of TowerTAPE Filing System Calls

$FF63 | TAPE_Leader_vec
$FF66 | TAPE_BlockOut_vec
$FF69 | TAPE_ByteOut_vec
$FF6C | TAPE_BlockIn_vec
$FF6F | TAPE_ByteIn_vec
$FF72 | TAPE_init_vec
$FF75 | TAPE_CAT_vec
$FF78 | TAPE_SAVE_BASIC_vec (to be used from TowerBASIC)
$FF7B | TAPE_LOAD_BASIC_vec (to be used from TowerBASIC)
$FFBA | F_TAPE_Setkbd_vec

$FF63 TAPE_Leader_vec

Calling this vector causes the generation of a leader tone.

$FF66 TAPE_BlockOut_vec

This is the vector call address for F_TAPE_BlockOut. V_TAPE_BlockSize ($900) contains the number of bytes to write and TAPE_BlockLo ($E5) and TAPE_BlockHi($E6) contain the block pointer.

This function returns having modified TAPE_BlockLo ($E5) and TAPE_BlockHi ($E6).

$FF69 TAPE_ByteOut_vec

Whatever byte is in the accumulator when this function is called is output.

$FF6C TAPE_BlockIn_vec

Calls to this function require parameters to be loaded into specific memory locations. point to the start of the block to be read. V_TAPE_BlockSize ($900-$901) specifies how many bytes will be read and TAPE_BlockLo ($E5) and TAPE_BlockHi ($E6) contain the write pointer used by this function. No additional information is read.

This function drops through before completion if any character is received from the ACIA card or an overrun error occurs and the state of the engine upon exit is reported in TAPE_BlockIn_Status ($90D)

This function returns having modified TAPE_BlockLo ($E5) and TAPE_BlockHi ($E6) which it uses these incrementally point to the byte it is writing to memory at any given moment.

$FF6F | TAPE_ByteIn_vec

Attempts to read a byte from the tape and return it in TAPE_ByteReceived ($90B). If a byte is received from the ACIA whilst it is in progress or if an overrun error occurs this function will exit reporting its status in TAPE_RX_Status ($909).

$FF72 | TAPE_init_vec

Initialises the TowerTAPE filing system. This is called by TowerOS on bootup and only needs to be called if the TowerTAPE filing system needs to be re-initialised.

$FF75 | TAPE_CAT_vec

Starts the tape system cataloguing routine. Can be called from Assembly language or by using the TowerBASIC keyword CAT.

$FF78 | TAPE_SAVE_BASIC_vec

Causes the TowerBASIC program or specified memory range (as a binary file) to be saved. This should not be called from anywhere except TowerBASIC as it is carefully designed to work as part of TowerBASIC.

$FF7B | TAPE_LOAD_BASIC_vec

Causes the attempted loading of an TowerBASIC program or binary file from tape. This should not be called from anywhere except TowerBASIC as it is carefully designed to work as part of TowerBASIC.

$FF7E | TAPE_VERIFY_BASIC_vec

Causes the attempted verification of an TowerBASIC program or binary stored on tape. This should not be called from anywhere except TowerBASIC as it is carefully designed to work as part of TowerBASIC.

$FFBA F_TAPE_Setkbd_vec

Sets up the vector for checking the keyboard input during any block read operation. This means it is called upon LOAD, VERIFY and CAT operations.

### TowerTAPE Filing System, System Variables

Below is a list of system variables with their associated address and size. These were grabbed direct from a spreadsheet which is also available.

System Variable | Address | Number of Bytes
TAPE_BlockLo | $E5 | 1
TAPE_BlockHi | $E6 | 1
V_TAPE_BlockSize | $900 | 2
TAPE_temp2 | $902 | 1
TAPE_temp3 | $903 | 1
TAPE_temp4 | $904 | 1
TAPE_LineUptime | $905 | 1
TAPE_Demod_Status | $906 | 1
TAPE_Demod_Last | $907 | 1
TAPE_StartDet | $908 | 1
TAPE_RX_Status | $909 | 1
TAPE_BitsToDecode | $90A | 1
TAPE_ByteReceived | $90B | 1
TAPE_Sample_Position | $90C | 1
TAPE_BlockIn_Status | $90D | 1

### TAPE_Header_Buffer $90E 28

TAPE_HeaderID | $90E | 4
TAPE_FileType | $912 | 1
TAPE_FileSizeLo | $913 | 1
TAPE_FileSizeHi | $914 | 1
TAPE_LoadAddrLo | $915 | 1
TAPE_LoadAddrHi | $916 | 1
TAPE_FileName | $917-927 | 17
TAPE_ChecksumLo | $928 | 1
TAPE_ChecksumHi | $929 | 1

### Remainder of TowerTAPE System Variables

TAPE_CS_AccLo | $92A | 1
TAPE_CS_AccHi | $92B | 1
V_TAPE_Phasetime | $92C | 1
V_TAPE_Sample_Offset | $92D | 1
V_TAPE_Bitlength | $92E | 1
V_TAPE_bitcycles | $92F | 1
V_TAPE_Verify_Status | $930 | 1
V_TAPE_Fname_Buffer | $931-$942 | 17
V_TAPE_LOADSAVE_Type | $943 | 1
V_TAPE_Address_Buff | $944-$945 | 2
V_TAPE_Size_Buff | $946-$947 | 2
V_TAPE_Config | $948 | 1
TAPE_KBD_vec | $949-$94B | 3

V_TAPE_Config has at present two bits for controlling the file system, with only
TAPE_AutoRUN_En | for | controlling | execution | of | BASIC | programs | and
TAPE_AutoEXEC_En for binaries. ParityOn is planned for implementation at time of modulation scheme amendment.

### V_TAPE_Config Bit Usage ($948)

| Bit 7 | Bit 6 | Bit 5 | Bit 4 | Bit 3 | Bit 2 | Bit 1 | Bit 0
Function | | | | | | TAPE_AutoEXEC_En | TAPE_AutoRUN_En | ParityOn
Default | 0 | 0 | 0 | 0 | 0 | 0 | 1 | 0

### TowerTAPE File Modulation Scheme

Each byte is encoded a series of bursts of carrier. A presence of carrier signifies a 1 and an absence a 0. Each burst of carrier is 16 cycles at 4KHz.

Each byte is structured as follows: -

Figure 4 Bit Order for Tape Byte

# Chapter 9. The V2 Memory

Board.

### Memory Bank Structure on the ToE

The ToE organises its memory into four groups of two banks of memory of 16 kibibytes each. Each bank group has a selection bit associated with it in a write only register located at address $C0FF. Writes to this register should be handled with great care as to not inadvertently page out something you are using at that time. Since many things you might need are located in the bottom and top banks, these are most likely to be of use to the machine code programmer and unlikely to be of use to anyone programming in TowerBASIC. The banks with the best outcome to the user of TowerBASIC are the middle ones as they can be excluded from use by TowerBASIC at boot time or by careful reconfiguration later.

This register is initialised to 0 at reset placing the lower half of each memory IC into view. For now, the upper four bits should be set to 0 whenever writing to this register as this is reserved for later expansion.

Banks 0 through 2 are RAM and bank 3 is the ToEs ROM containing TowerOS and TowerBASIC.

Although bank 3 consists of 32 kibibytes of space, the address range $C000 to $C0FF is put aside for memory mapped hardware and is inaccessible. This constitutes a loss of just half a kibibyte. In a system with 96 kibibytes of RAM and 32 kibibytes of ROM. A small price to pay for such a generous and fully decoded IO space!

### Jumper Selection

There are two jumpers on this card, the one nearest the bus connector (JP4), is to allow the use of 27 series 16K EPROMs and should be set 1-2 (back) for 27 series, or 2-3 (front) for 28C256 EEPROMs.

The other jumper (JP5) is a write protect. One cannot state enough that this should be left write protected under normal circumstances to avoid crashes and corruption of the ROM. Position 1-2 (back) is write-protected and 2-3 (front) allows writes to occur.

### Firmware Update Guidance

To write to the EEPROM, one must use a bootloader as write times are somewhat in excess of normal access times and the data lines contain write status information whilst a write is being attempted. The CPU would attempt to execute this status information as instructions if code was being executed from the ROM at this time!!

Inadvertent writes will not cause a crash when write protect is on.

# Chapter 10. The CPU Card

(V2).

### CPU Card V2 Description

Central to the Tower of Eightness is its processor. The WDC65C02-TPG14 processor is a CMOS microprocessor with an eight-bit wide data bus and a sixteen-bit wide address bus. It executes single byte opcodes at typically two to three processor cycles per instruction and does this at up to 14MHz. The Tower bus being a backplane for various unknown addons has required the CPU to be limited to 4MHz and so the on-board oscillator produces 4, 2 or 1MHz as selected by a set of jumpers.

As can be seen from Figure 3, the board has four positions on a header labelled 1 through 4 alongside some text informing one of the available speeds. Connecting across jumper position 1 will give 1MHz operation, 2 will give 2MHz, and 3 will give 4MHz from the divider circuit. Position four is for connecting an external clock to the system bus and must not be shorted or the clock line will be tied to ground!

The recommended position is as fast as your hardware will allow. Most of the time this is 4MHz. There is also a header which provides LED output for the status of the IRQ and NMI lines to assist the programmer with interrupts. For the assembly language programmer or the hardware developer, the WDC65C02 datasheet is a must read and is included. For the TowerBASIC user, it is usually enough to know how fast this processor is running.

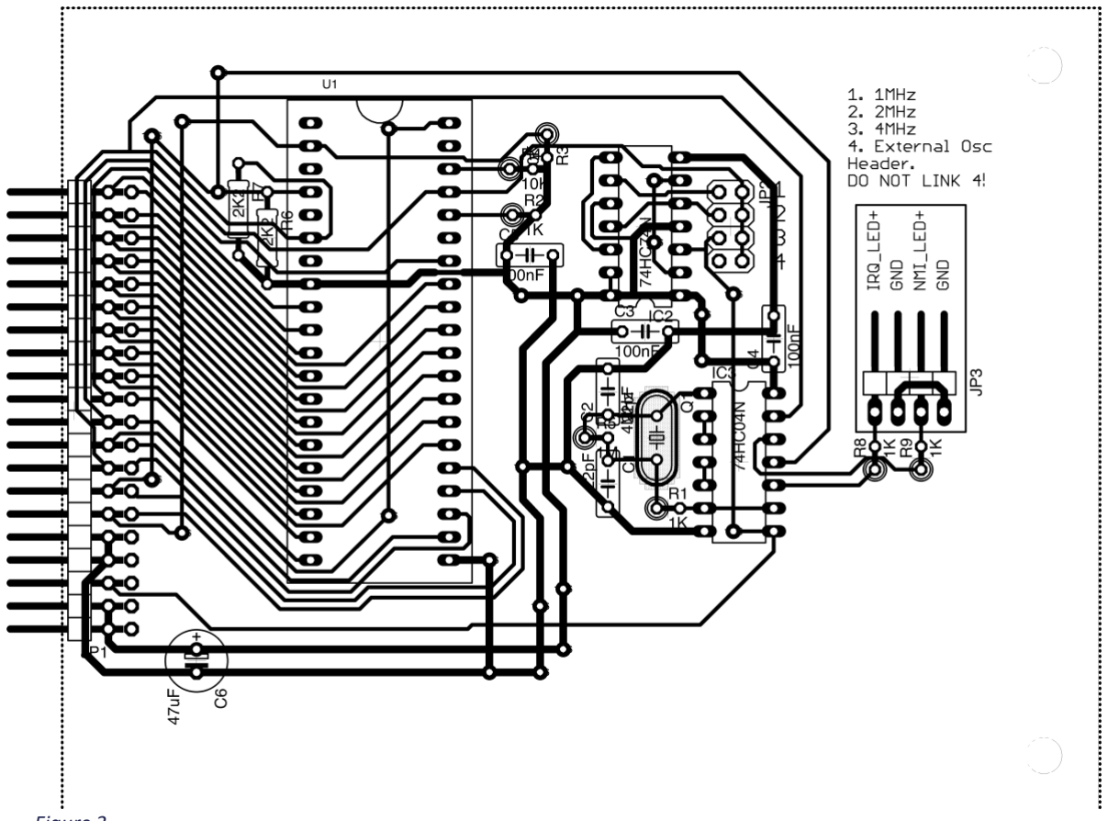
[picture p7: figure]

Figure 3

# Chapter 11. Tower 8 Card &

CPU Backplane.

### CPU Backplane Description

As the system grew, the original backplanes became a little constraining and so was born the 8-slot integrated CPU backplane. On the backplane there are 8 TowerBUS slots, one W65C02S6-TPG14 CPU, one clock generator (which can be disabled), IRQ and NMI lights header, reset header, power input terminals and the logic to decode bank selection and IO page selection. This does not handle sideways bank selection, that is done by the memory card.

It should be noted that the 8 slot and CPU backplane needs either the extension piece with two extra joining bars or the larger modular case sections. Both the new motherboard and the older 7 slot one can use the same endcaps, joining bars and power supply module.

### TowerBUS Pinout and Specification

There are 40 pins in two rows of 20. Each pin is assigned a signal except for the 5V and ground pins which are assigned in pairs.

Each signal pin is compatible with 74HC series logic and there is no buffering so be mindful of fanout, taking note of the W65C22S6-TPG14 datasheet for the CPU bus pins and the Lattice GAL22V10D-7LP datasheet for the bank selection pins. The power supply is rated at 1.4A but the supplied fuse is an F1A M205. Do not exceed 1.4A even with a bigger fuse fitted.

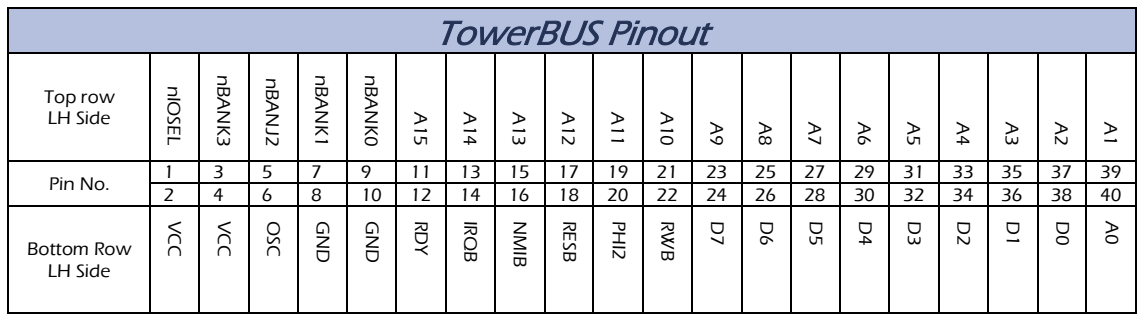
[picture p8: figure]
TowerBUS Pinout; Top row LH Side; nIOSEL; nBANK3; nBANJ2; nBANK1; nBANK0; Pin No.; Bottom Row LH Side; VCC; OSC; GND; RDY; IRQB; NMIB; RESB; PHI2; RWB

### Table of Pins/Signals

1 | nIOSEL | Signals to hardware that the IO address range is being
| | selected.
2 | VCC | +5V power output. Tied to pin 4.
3 | nBANK3 | Signals to the hardware that memory bank 3 is being
| | selected.
4 | VCC | +5V power output. Tied to pin 3.
5 | nBANK2 | Signals to the hardware that memory bank 2 is being
| | selected.
6 | OSC | This is the 4MHz oscillator output for the system.
7 | nBANK1 | Signals to the hardware that memory bank 1 is being
| | selected.
8 | GND | Return path to ground. Tied to pin 10.
9 | nBANK0 | Signals to the hardware that memory bank 0 is being
| | selected.
10 | GND | Return path to ground. Tied to pin 8.
11 | A15 | Address line 15 from the CPU.
12 | RDY | Ready pin for use arbitrating the bus usage of the CPU.
13 | A14 | Address line 14 from the CPU.
14 | IRQB | Interrupt request signal used by hardware to interrupt the
| | CPU.
15 | A13 | Address line 13 from the CPU.
16 | NMIB | Non-Maskable interrupt request signal used by the
| | hardware to interrupt the CPU.
17 | A12 | Address line 12 from the CPU.
18 | RESB | Reset line. Briefly pulled low by the reset circuit on the PSU
| | board and optionally by external hardware.
19 | A11 | Address line 11 from the CPU.
20 | PHI2 | Processor clock generator, used extensively around the
| | system to provide synchronisation of various hardware
| | connected to the TowerBUS. This is the rate at which the
| | CPU operates and is set by jumpers.
21 | A10 | Address line 10 from the CPU.
22 | RWB | Signals that the CPU is reading the bus when high, writing
| | when low. Must be used in conjunction with a means of
| | ensuring processor timing requirements are met.
23 | A9 | Address line 9 from the CPU.
24 | D7 | Data bit 7 of the TowerBUS.
25 | A8 | Address line 8 from the CPU.
26 | D6 | Data bit 7 of the TowerBUS.
27 | A7 | Address line 7 from the CPU.
28 | D5 | Data bit 5 of the TowerBUS.
29 | A6 | Address line 6 from the CPU.
30 | D4 | Data bit 4 of the TowerBUS.
31 | A5 | Address line 5 from the CPU.
32 | D3 | Data bit 3 of the TowerBUS.
33 | A4 | Address line 4 from the CPU.
34 | D2 | Data bit 2 of the TowerBUS.

35 | A3 | Address line 3 from the CPU.
36 | D1 | Data bit 1 of the TowerBUS.
37 | A2 | Address line 2 from the CPU.
38 | D0 | Data bit 0 of the TowerBUS.
39 | A1 | Address line 1 from the CPU.
40 | A0 | Address line 0 from the CPU.

# Chapter 12. Tower Peripheral Bus & Centronics

Interface.

### Tower Peripheral Bus and Centronics Card Description

This card provides both multi-drop serial communications (Tower Peripheral Bus) and Centronics printer support. The TPB bus in particular, has very complex behaviour and many function calls. This bus is a work-in-progress at present, but the hardware is functional. This card has a base address of $C020 and uses up-to $C02F.

### The Centronics Port

This is modelled after the BBC micro implementation and may serve to output any characters as the user wishes via the OUTP_V, or more directly via either the vectored system call TPB_LPT_write_vec ($FF99) or by direct hardware access, though this is discouraged. To use TPB_LPT_write_vec, place the character to be written into the accumulator and call TPB_LPT_write_vec. This presently a blocking call and if the printer hangs the Centronics bus in a way you can’t clear printer-side, you will have to perform a warm start.

To direct your output stream to also go to the LPT port, one usually sets os_outsel ($5E0) bit 2 to 1, everything then also going to the Centronics port. Clearing bit 2 stops this.

NC | NC | NC | ACK Centronics Port Pinout Top | PD7 | PD6 | PD5 | PD4
25 | 23 | 21 | 19 | 17 | 15 | 13 | 11 | 9 | 7 | 5 | 3 | 1

PD3

PD2

PD1

PD0

STROBE

Bottom

26 | 24 | 22 | 20 | 18 | 16 | 14 | 12 | 10 | 8 | 6 | 4 | 2 NC | GND | GND | GND | GND | GND | GND | GND | GND | GND | GND | GND

GND

# Chapter 13. The IRQ

Handler Sub-system.

### IRQ Handler Sub-System Description

Interrupts make it easier to handle outside events such as incoming serial data, timing, and software exceptions. The ToE’s processor furnishes only rudimentary interrupt handling, and this sub-system is provided to flexibly manage multiple interrupts. The way this is achieved is by use of a table of eight vectors processed one by one, using a bitfield to select which one’s are active. Initially, the table is populated with a null handler such that if one of its entries is inadvertently enabled, it is handled gracefully, rather than crashing the system.

The means by which one sets or clears an interrupt vector are by the provision of atomic calls which retain the interrupt handling state as much as possible so that other interrupts are delayed as little as possible.

### IRQ System Call Vectors

$FFDB | IRQH_Handler_Init_vec
$FFDE | IRQH_SetIRQ_vec
$FFE1 | IRQH_ClrIRQ_vec
$FFE4 | IRQH_SystemReport_vec
$FFDB | IRQH_Handler_Init_vec

Calling this vector clears the interrupt vector table and resets the IRQ Handler subsystem. It may be that individual interrupt vectors get a reset vector table too, but this is not a given yet.

$FFDE | IRQH_SetIRQ_vec

Atomically transfers an interrupt’s vector from IRQ_CallReg to the table location specified in A. Locations available are 0 through 7 with 0 being handled first, subsequent locations being handled in sequential order. Note that this does not affect whether the interrupt vector is selected or not. It is the users’ responsibility to manage this themselves.

$FFE1 | IRQH_ClrIRQ_vec

Atomically transfers the null vector to the table location specified in the accumulator. Locations available are 0 through 7 with 0 being handled first, subsequent locations being handled in sequential order. Note that this does not affect whether the interrupt vector is selected or not. It is the users’ responsibility to manage this themselves.

$FFE4 | IRQH_SystemReport_vec

Calling this returns the base address of the IRQ handler table, including all variables. This is done so that the table location does not need to be known in advance. Given that this data structure is very likely to change, this will prevent breakage of code written for the ToE.

Upon return, X will contain IRQH_Table_Base low byte, Y will contain its high byte, and A will contain the IRQ handler version.

### IRQH_Table_Base Structure

Offset | Name | Purpose
$0-$15 | IRQH_CallList | Eight consecutive little-endian call addresses
for the users’ IRQ device handlers.
$16-$17 | IRQH_CallReg | Intermediate | register | for | atomically
transferring addresses to the call list above.
$18 | IRQH_ClaimsList | Bitfield showing which interrupts claimed
and thus serviced an interrupt.
$19 | IRQH_MaskByte | Bitfield for selecting which interrupts are to
be serviced in the event of the IRQ vector
| | being invoked.
$20 | IRQH_WorkingMask | Internal variable, this walks from the LSb to
the MSb and is used for various parts of the process. Do not write to this variable.
$21-$31 | IRQH_CMD_Table | Table of IRQ Commands and parameter
| | values.

### Command Codes

Each IRQ has an associated parameter and command code byte entry in the IRQH_CMD_Table. These are sorted as follows. First is the parameter, followed by the command code.

Each IRQ must check on entry and before claiming IRQ for the following commands:

0. IRQH_Service_CMD | Instructs the IRQ that service is required.
1. IRQH_Shutdown_CMD | The IRQ must perform an orderly shutdown.
2. IRQH_Reset_CMD | The IRQ must reset to an initial state.

Further commands may be implemented by the user but values below 8 are presently reserved for future upgrades.

### Starting an IRQ Service

Starting and IRQ consists of writing it’s address to the IRQH_CallReg ($A30-$A31), Loading the accumulator with our chosen IRQH_CallList location (0-7), calling IRQH_SetIRQ_vec to load it atomically and then calling our IRQ’s initialisation routine.

The IRQ initialisation routine should handle starting of the IRQ as necessary. To return the IRQ vector to the system, there is a separate call IRQH_ClrIRQ_vec ($FFE1).

### Servicing an IRQ

IRQ’s running through the IRQ Handler must check upon entry, their associated command entry, pointed to by IRQH_CMD_Table + the X index register. The IRQ must process at least the minimum system command codes listed above. Parameters for the minimum set are not required.

Each time the IRQ is called, it must check that the hardware associated with it has generated an interrupt, set the appropriate claim bit in IRQH_ClaimsList ($A32) by ORing IRQH_WorkingMask ($A34) into it and clear the hardware IRQ signal so as not to cause nuisance IRQ calls and system hangs. IRQ’s not generated by the associated hardware must not cause undue resource wastage or set the claim bit.

Exit from the IRQ routine is by RTS not RTI. This is so that other IRQ routine’s may check their associated hardware and commands before the handler hands control back to the system.

### Stopping an IRQ

Sending the IRQH_Shutdown_CMD (1) to the IRQ will cause the IRQ to stop. This does not remove it from the IRQH_CallList but does allow the IRQ the chance to stop in an appropriate manner. Alternatively, an atomic call may be created to do the same.

A stopped IRQ may be re-started at any time by either calling its initialisation routine or if appropriate, setting its associated bit in IRQH_MaskByte ($A33).

### Removing an IRQ Service from the IRQH_CallList ($A20-$A30)

One must have first stopped the IRQ, then the accumulator must be loaded with the correct table entry. This is followed by calling IRQH_ClrIRQ_vec, which handles this atomically. After clearing, the table contains a safe dummy entry that points to a function that does nothing but ensure the IRQH_ClaimsList is correct before returning control to the IRQ handler.
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

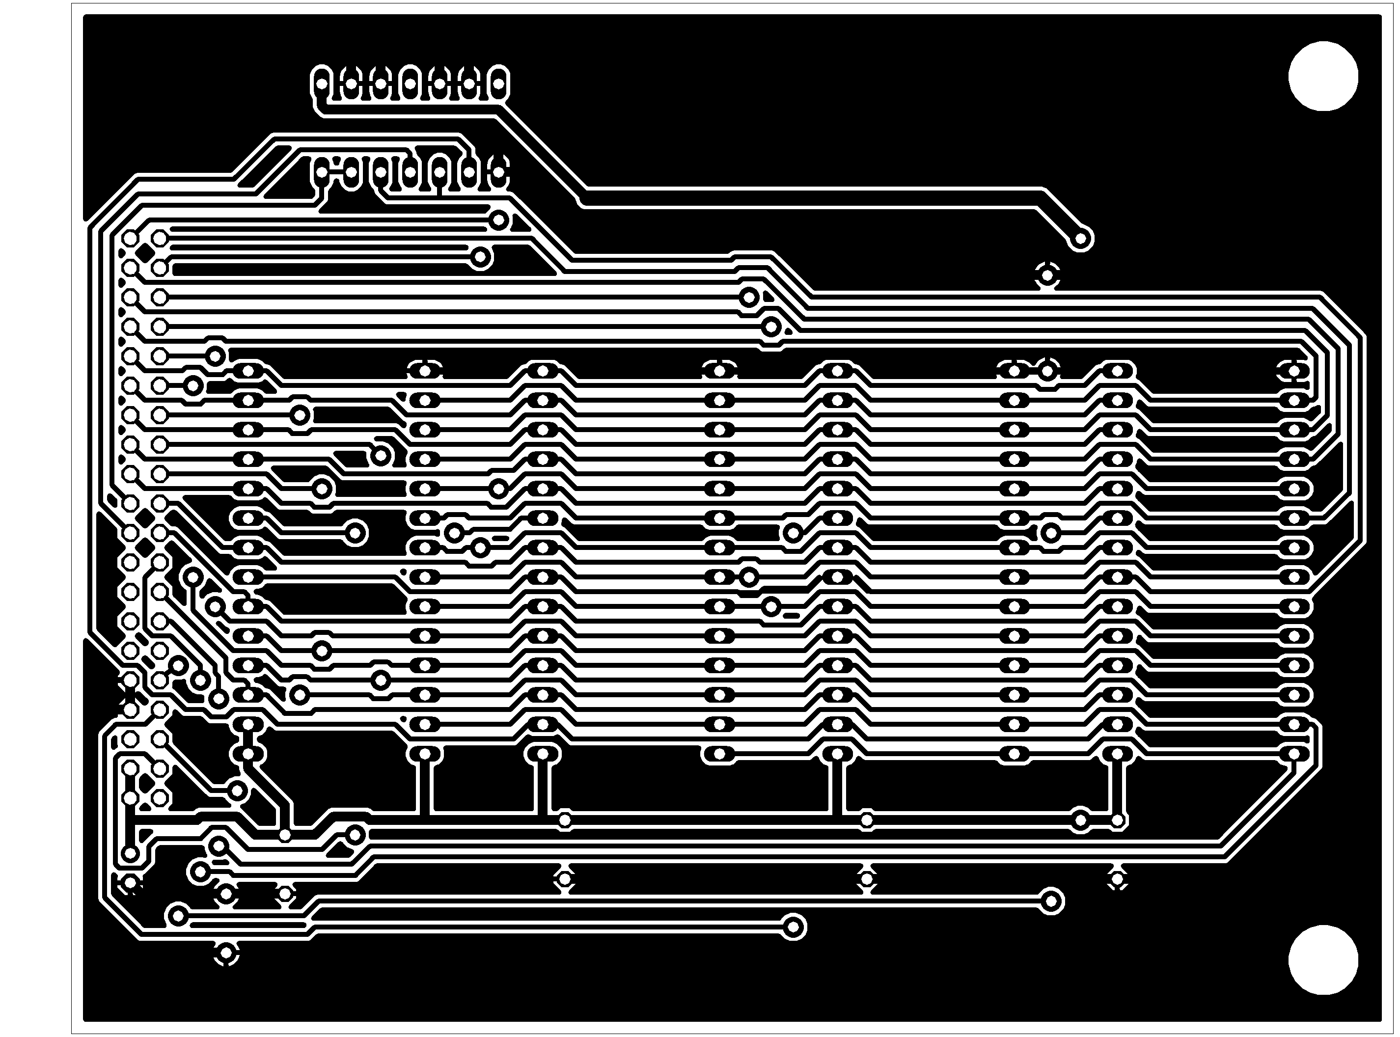
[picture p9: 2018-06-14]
Board Art/Memory Board.png

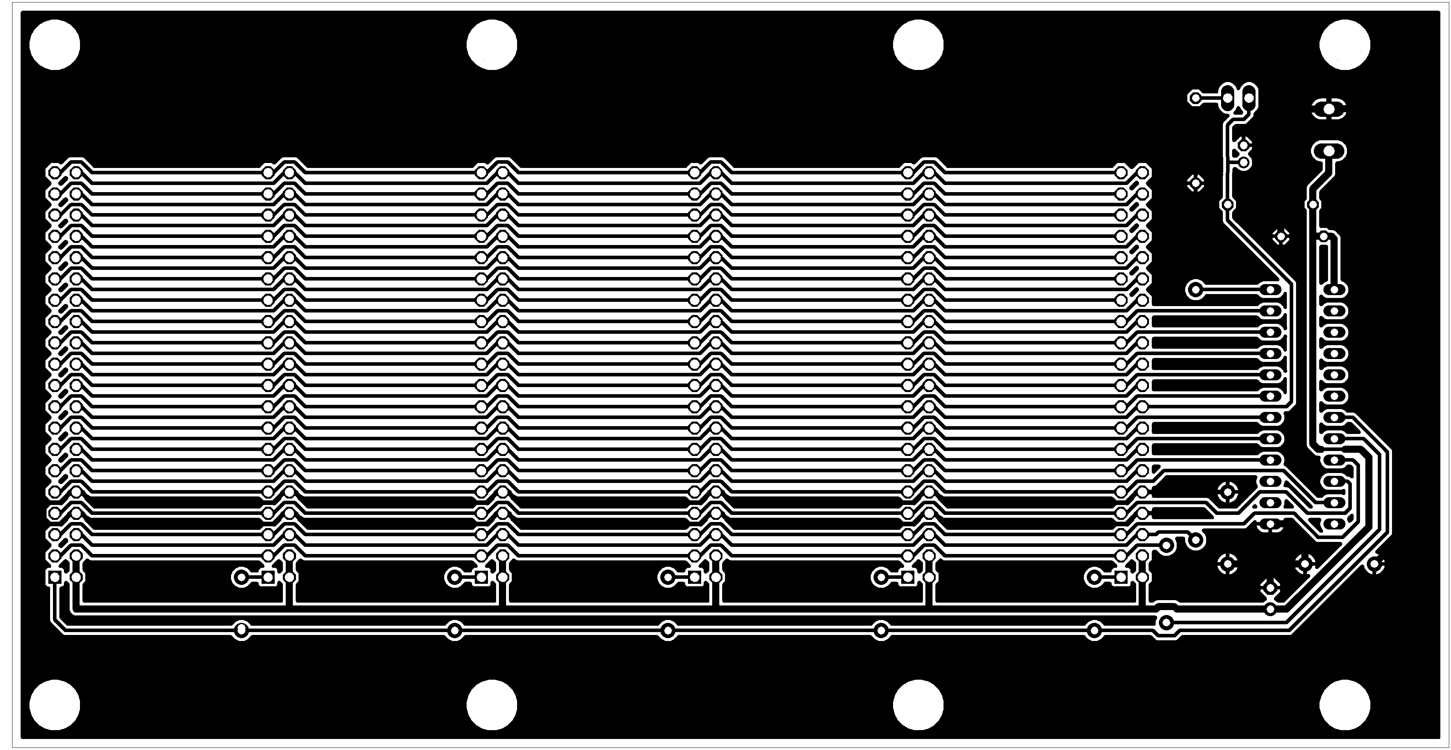
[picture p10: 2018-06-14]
Board Art/motherboard.png

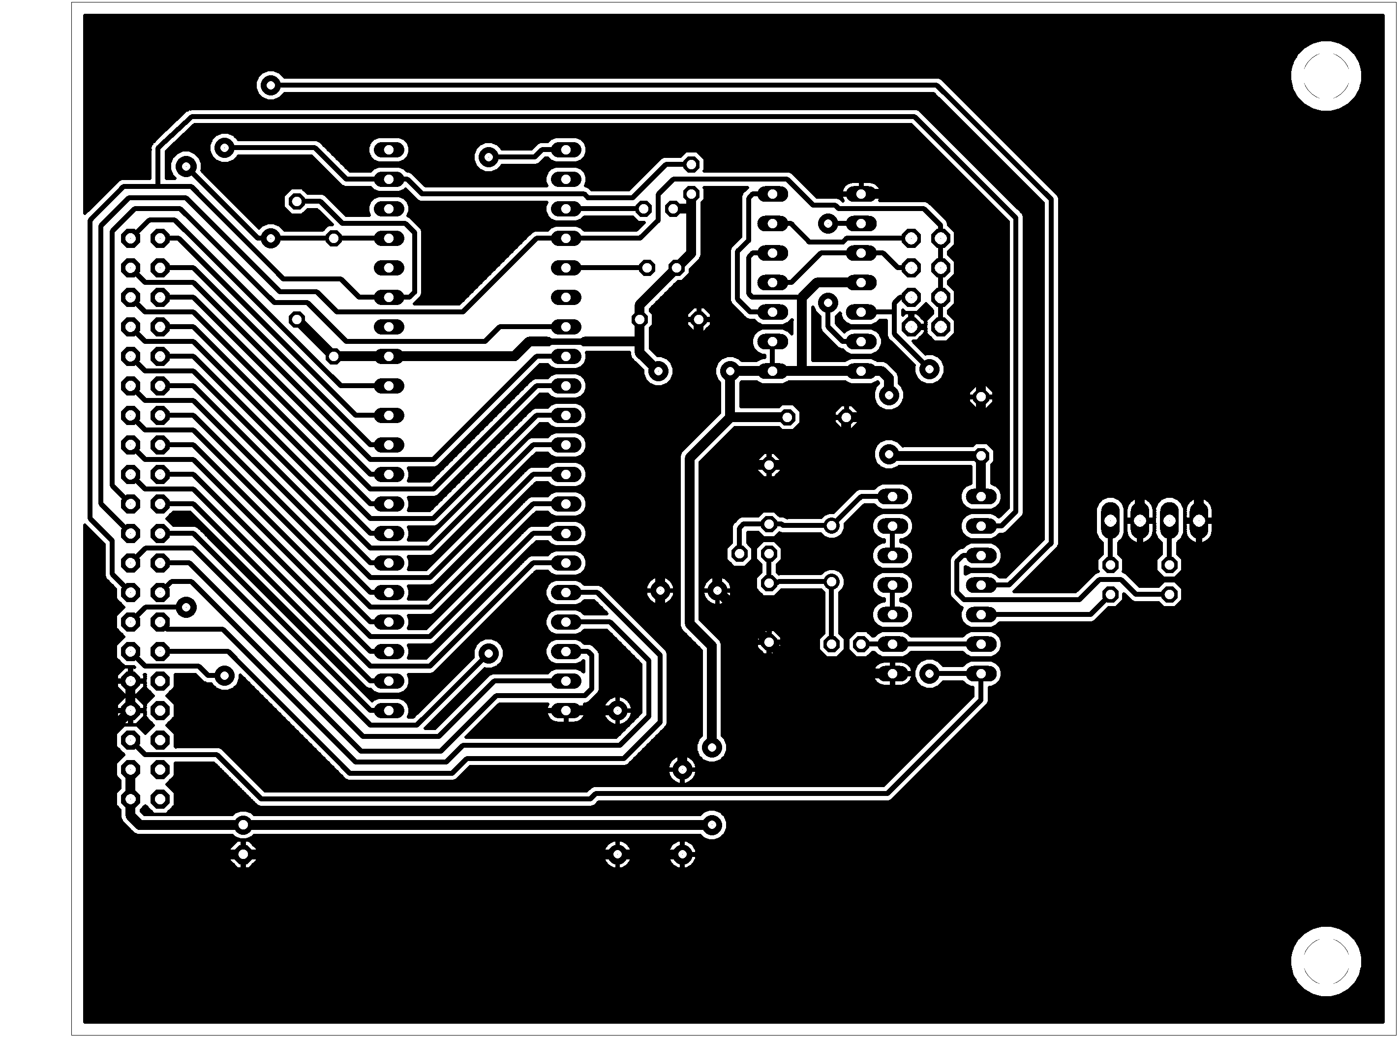
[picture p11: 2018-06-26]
Board Art/Processor Board v2.png

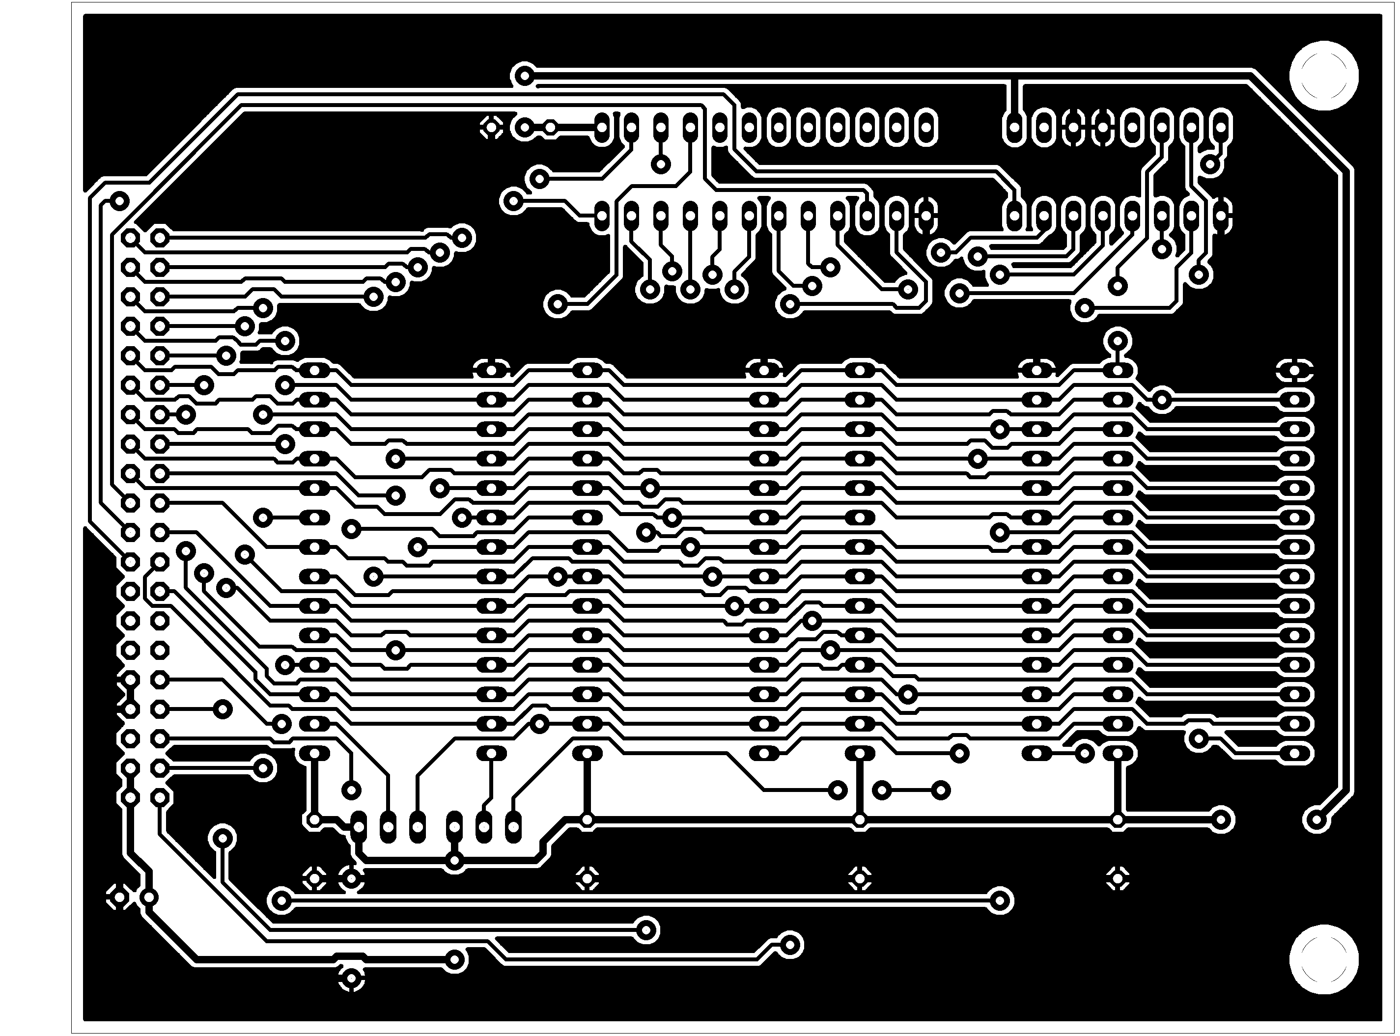
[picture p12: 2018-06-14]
Board Art/Memory-Board-V2.png

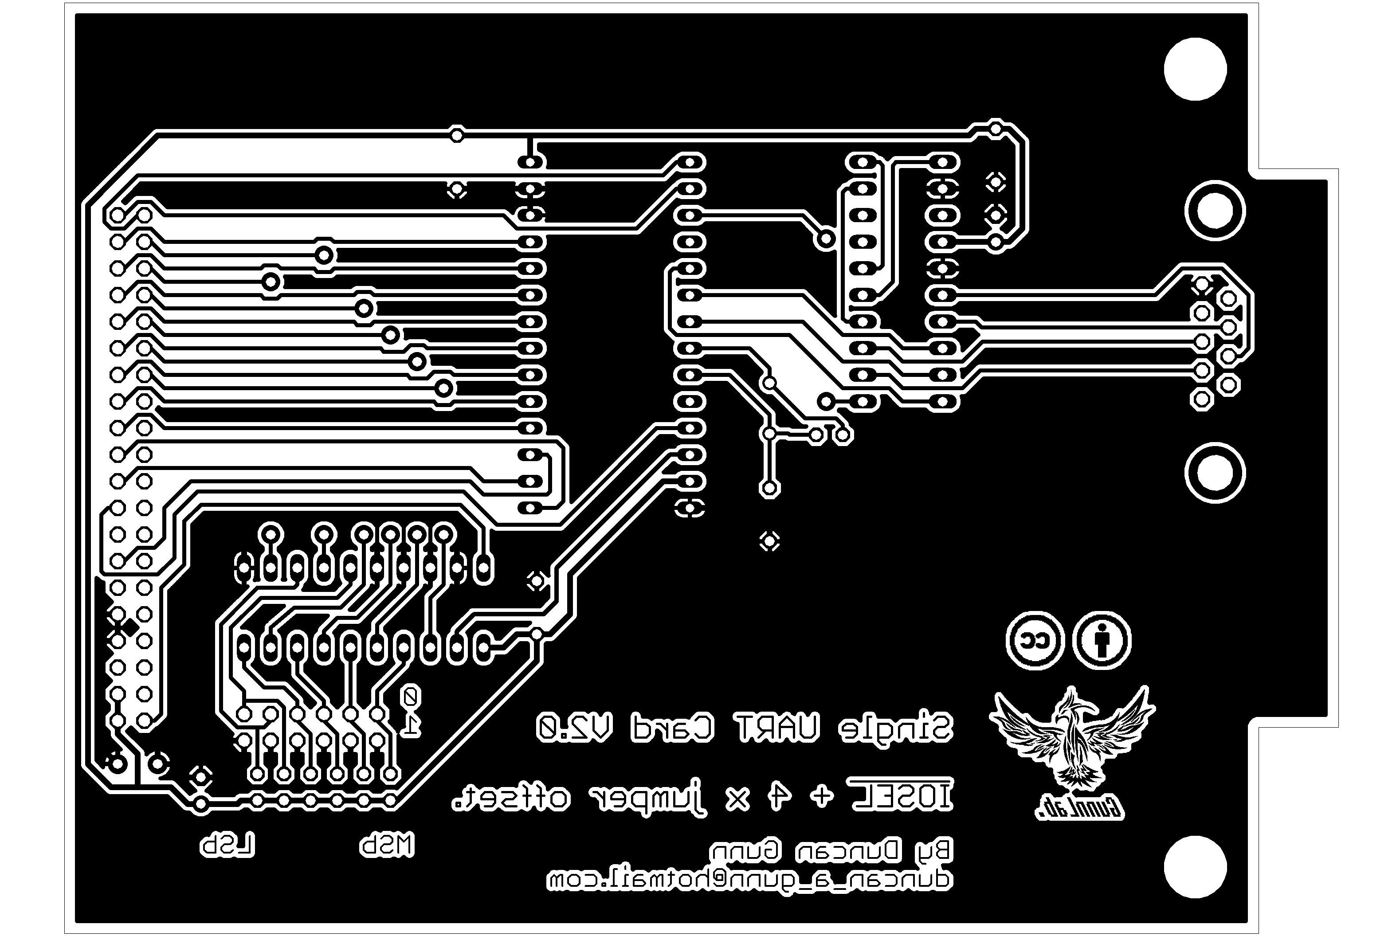
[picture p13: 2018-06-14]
Board Art/Serial Card V2.png

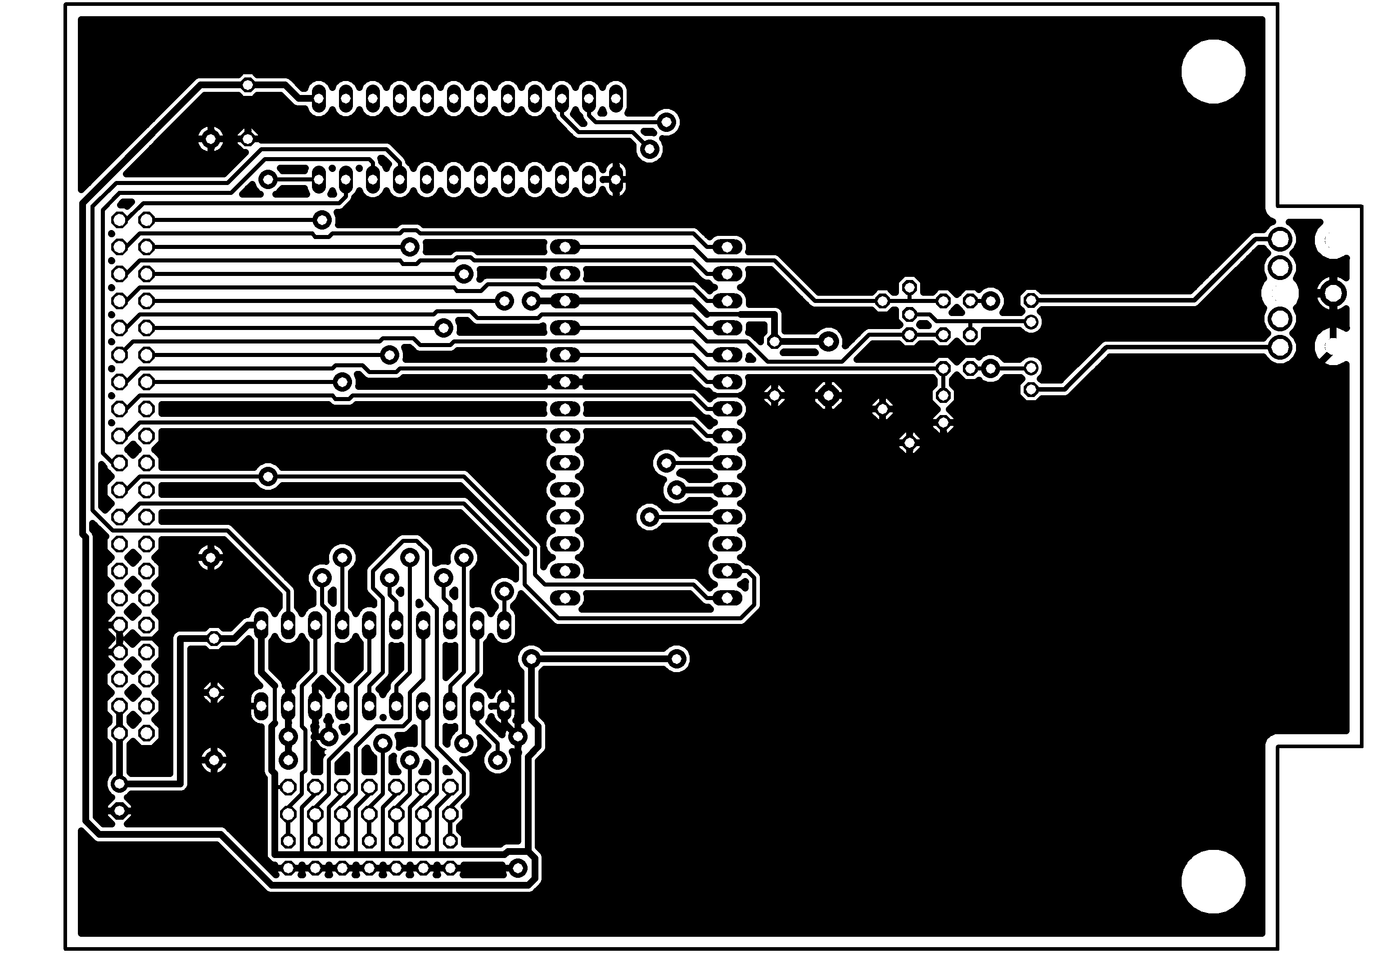
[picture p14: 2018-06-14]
Board Art/AY Soundcard.png

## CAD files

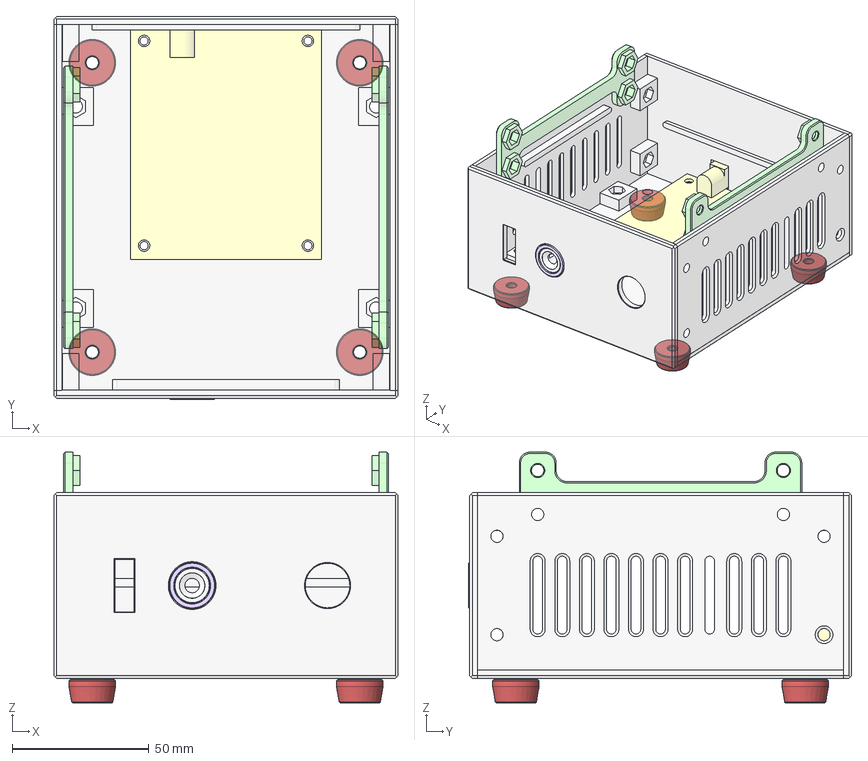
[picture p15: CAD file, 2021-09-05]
Cases/Bottom cap assembly/Bottom Cap Assembly.FCStd
126.0 x 140.3 x 91.9 mm
Hoop
Rear Endplate
Sideplate array
Joining bar array
Foot array
Front Endplate
PCB
Base plate

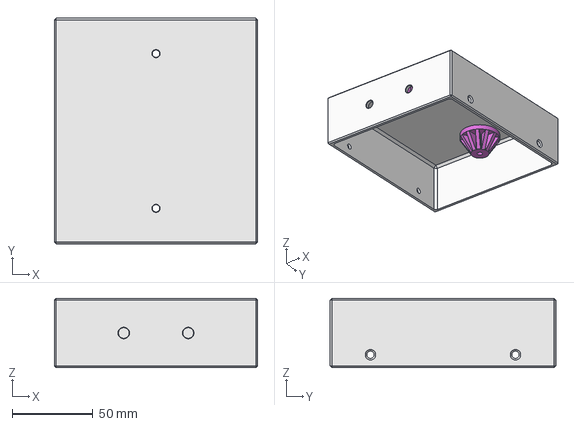
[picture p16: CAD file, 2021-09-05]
Cases/Top Cap Assembly/Top Cap Assembly.FCStd
126.0 x 140.0 x 43.0 mm
Cap
Optional load spreader array

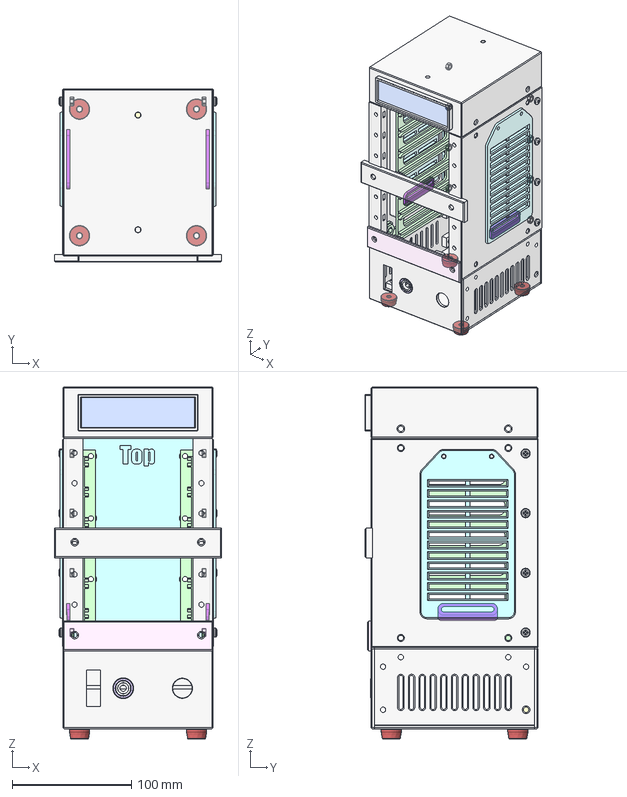
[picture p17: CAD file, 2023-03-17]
Cases/Assembly model (WIP)/Assembly Model.FCStd
140.0 x 145.2 x 294.8 mm
Cap x 2
Badge x 2
Badge Frame x 2
Hoop x 2
Rear Endplate x 2
Sideplate array x 2
Joining bar array x 2
Foot array x 2
Front Endplate x 2
PCB x 2
Base plate x 2
Nuts for sideplate
Nuts for sideplate (Mirror #5) x 2
Tab x 4
Vented_cover x 4
Tab001 x 4
Vented_cover001 x 4
Sideplate
Sideplate (Mirror #5) x 2
M4 X 10 Pan Hd Pozi
Side panel retaining nuts x 2
Guide
Guide (Mirror #2)
V3 Basetray
Faceplate blank
Card Extender Faceplate

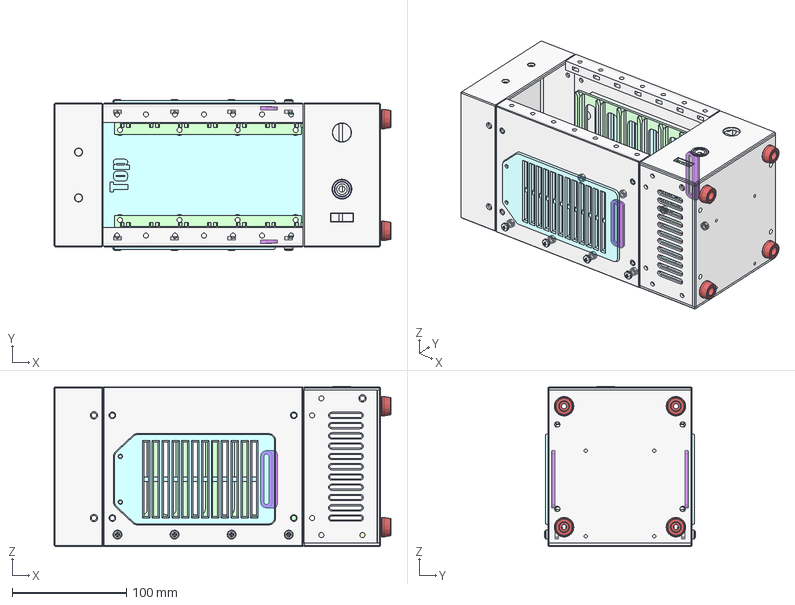
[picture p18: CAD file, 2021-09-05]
Cases/Assembly Model.FCStd
295.3 x 132.5 x 140.4 mm
Cap x 2
Hoop x 2
Rear Endplate x 2
Sideplate array x 2
Joining bar array x 2
Foot array x 2
Front Endplate x 2
PCB x 2
Base plate x 2
Nuts for sideplate
Nuts for sideplate (Mirror #5) x 2
Tab x 4
Vented_cover x 4
Tab001 x 4
Vented_cover001 x 4
Sideplate
Sideplate (Mirror #5) x 2
M4 X 10 Pan Hd Pozi
Side panel retaining nuts x 2
Guide
Guide (Mirror #2)
V3 Basetray

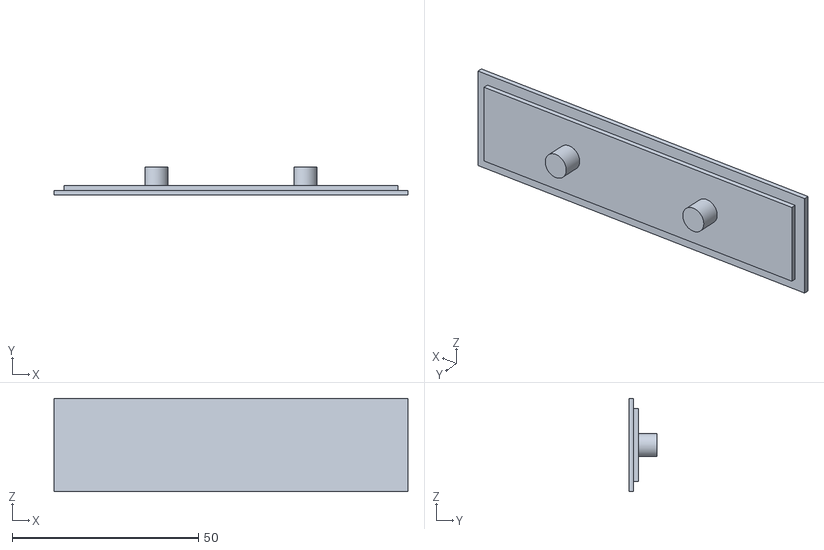
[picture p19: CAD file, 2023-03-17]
Cases/Assembly model (WIP)/Badge.stl
95.0 x 7.50 x 25.0

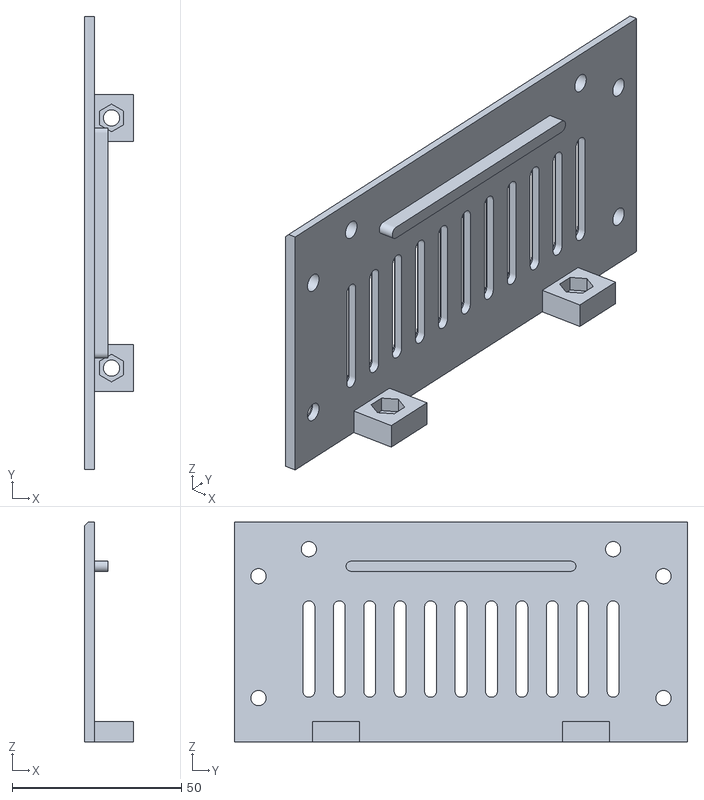
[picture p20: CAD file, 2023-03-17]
Cases/Bottom cap assembly/STLs/Sideplate.stl
14.5 x 134.0 x 65.0

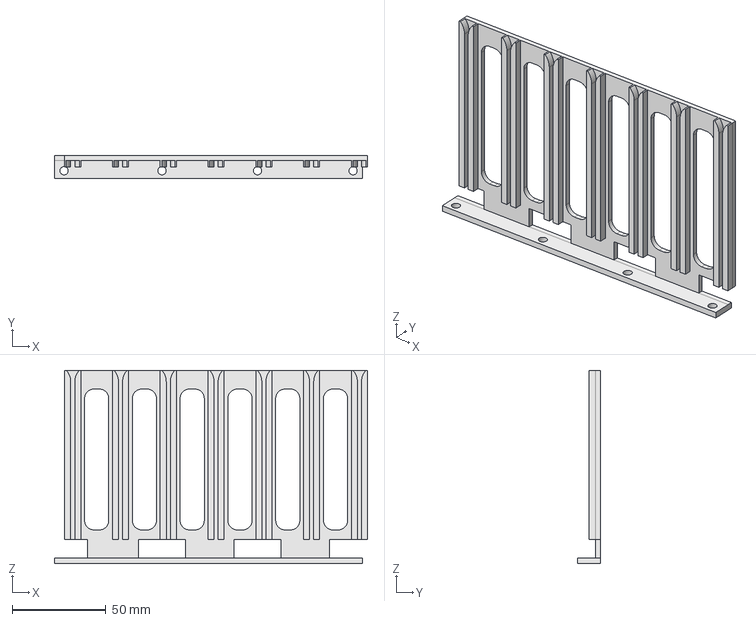
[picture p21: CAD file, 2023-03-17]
Cases/Card Guide V3.fcstd
166.6 x 12.0 x 103.0 mm

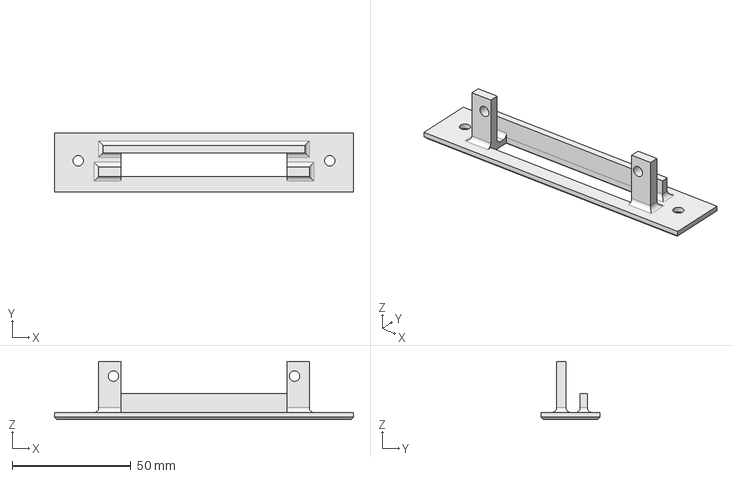
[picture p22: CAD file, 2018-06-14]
Cases/Faceplates/Card Faceplate 6522 V2.FCStd
126.0 x 25.0 x 24.5 mm

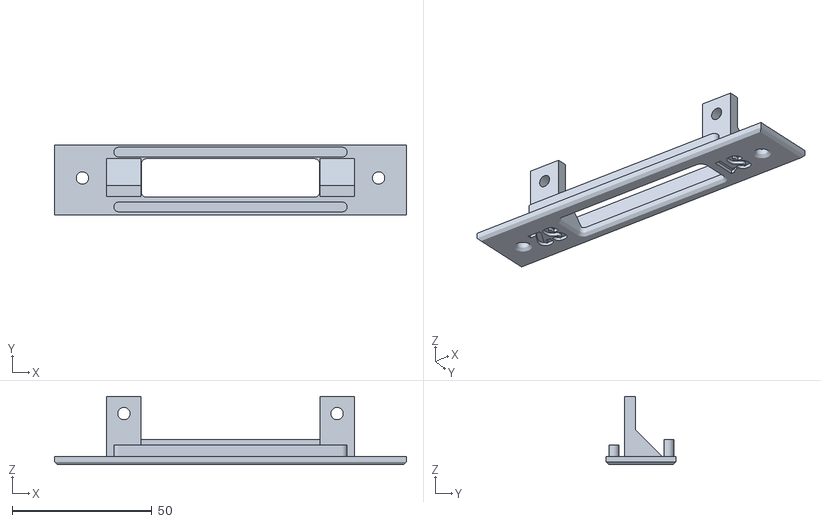
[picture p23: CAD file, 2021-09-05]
Cases/Faceplates/Dual ACIA Faceplate/Dual ACIA Faceplate V3.stl
126.0 x 25.0 x 24.5

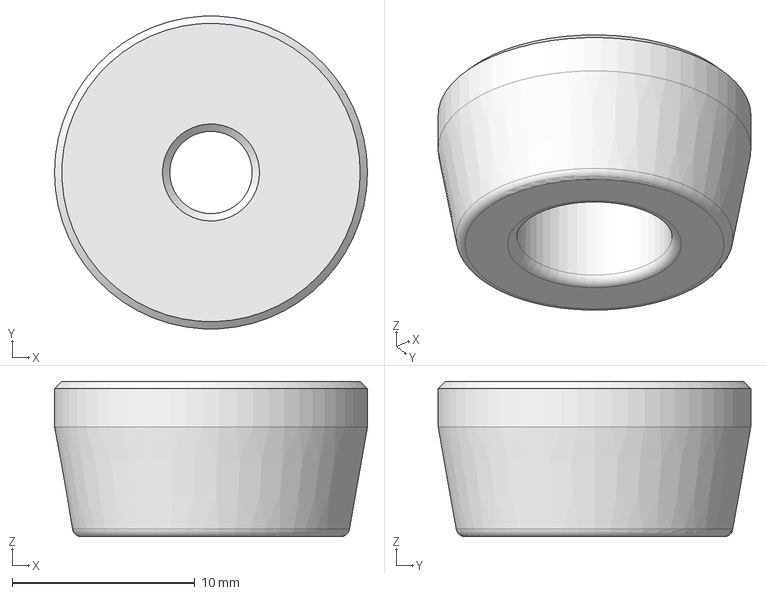
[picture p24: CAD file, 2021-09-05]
Cases/Foot/Foot.FCStd
17.1 x 17.1 x 8.50 mm

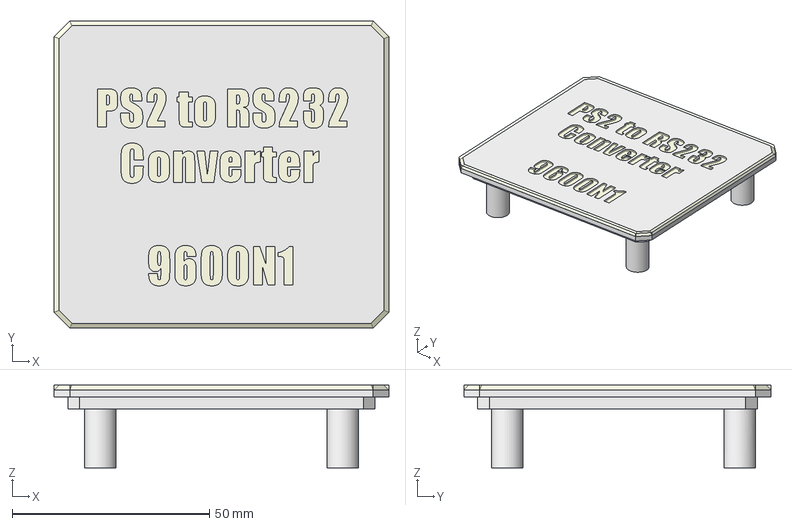
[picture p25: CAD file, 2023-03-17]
Cases/PS2 to RS232 kb adaptor (compact)/PS2 to RS232 lid.FCStd
85.0 x 78.0 x 21.0 mm

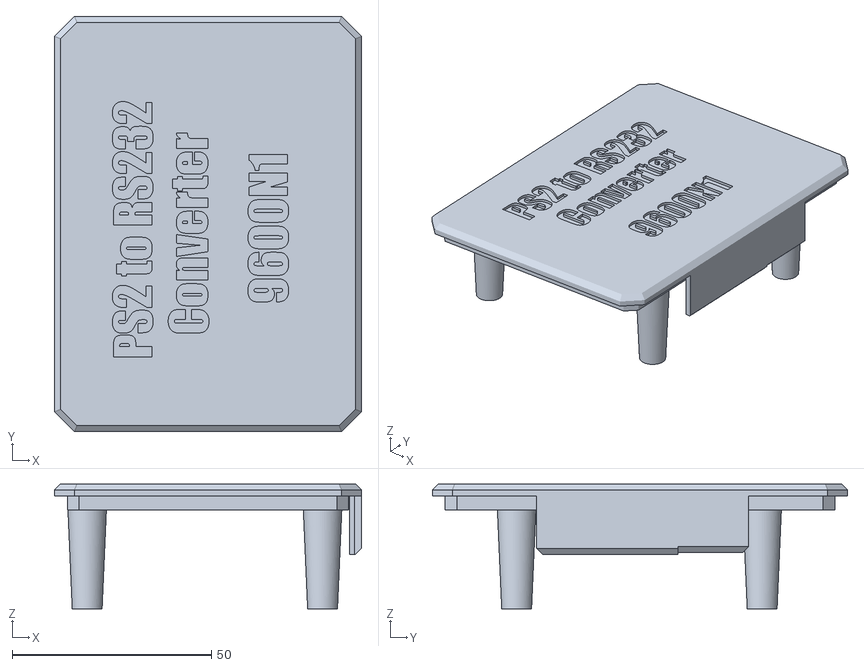
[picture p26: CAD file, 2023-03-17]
Cases/PS2 to Serial KB Adapter Enclosure (larger)/Lid.stl
77.0 x 104.2 x 31.4

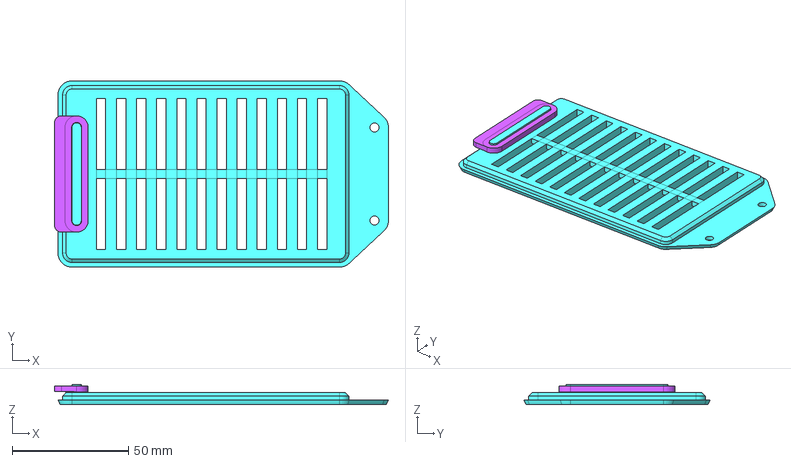
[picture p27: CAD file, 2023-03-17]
Cases/Sideplate/Vented-cover.step
143.5 x 80.0 x 8.70 mm

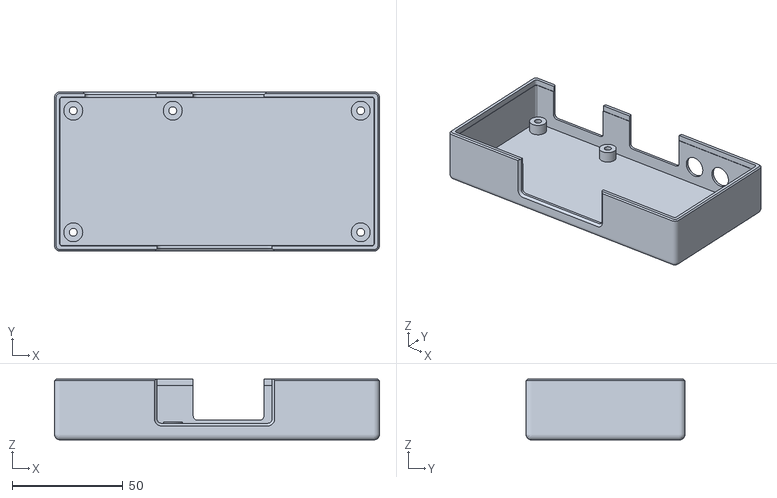
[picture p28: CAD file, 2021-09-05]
Cases/Tape and Joystick Interface V1/Base.stl
147.0 x 72.0 x 27.5

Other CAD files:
Cases/Top Cap Assembly/STLs/Top Cap.stl
Cases/V3 Basetray/V3 Basetray.FCStd
Cases/Bottom cap assembly/Decorative Hoop.FCStd
Cases/Bottom cap assembly/STLs/Frontplate.stl
Cases/Assembly model (WIP)/Badge frame.stl
Cases/Assembly model (WIP)/Card Guide.stl
Cases/Bottom cap assembly/STLs/Backplate.stl
Cases/Bottom cap assembly/STLs/Baseplate.stl
Cases/Bottom cap assembly/STLs/Frontplate with larger rocker cutout.stl
Cases/Bottom cap assembly/STLs/Hoop.stl
Cases/Bottom cap assembly/STLs/Joining-bar.stl
Cases/Decorative Hoop.FCStd
Cases/Endcap blank.FCStd
Cases/Faceplates/AY Card V1.stl
Cases/Faceplates/Bus Card Faceplate.fcstd
Cases/Faceplates/Bus Card Faceplate.stl
Cases/Faceplates/CPU Faceplate V2.stl
Cases/Faceplates/CPU Faceplate.stl
Cases/Faceplates/Card Faceplate 6522.FCStd
Cases/Faceplates/Card Faceplate Blank V2.FCStd
Cases/Faceplates/Card Faceplate Blank.FCStd
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

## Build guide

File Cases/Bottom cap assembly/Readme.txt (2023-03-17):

This one is the one that fits the current PSU board.  Make this one.

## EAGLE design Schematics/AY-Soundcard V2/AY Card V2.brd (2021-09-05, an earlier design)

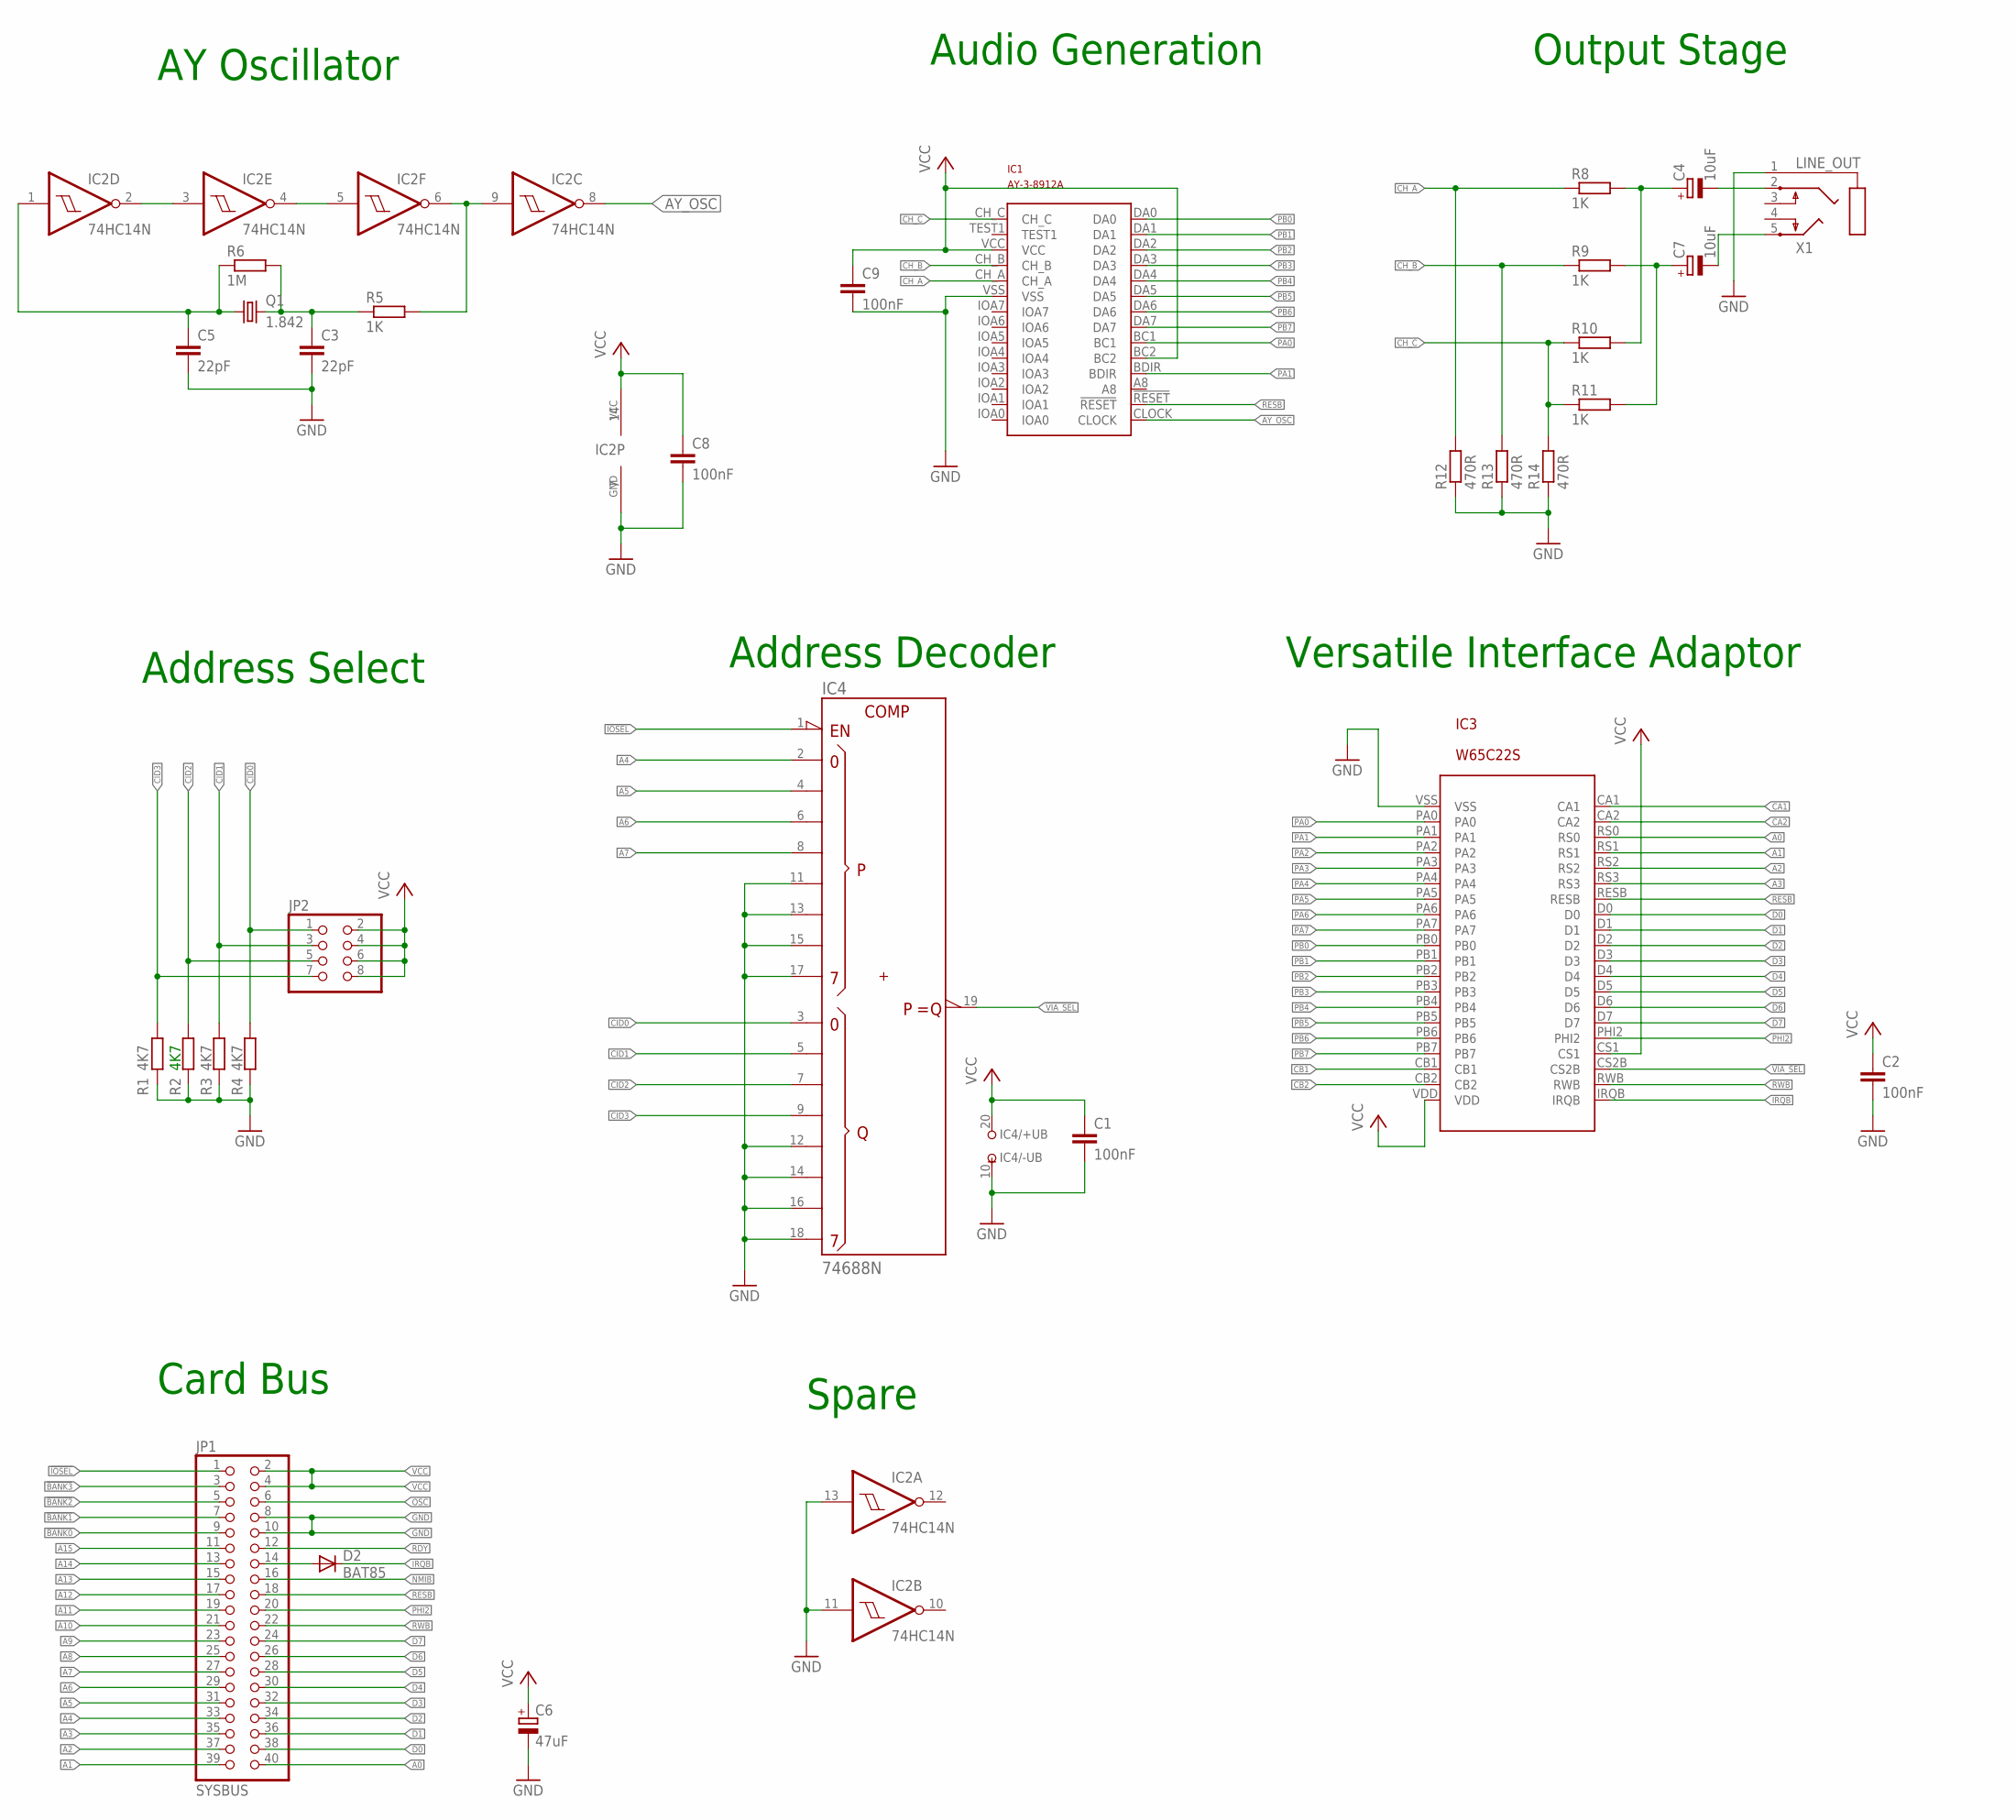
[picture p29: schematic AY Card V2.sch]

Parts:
C1, C2, C8, C9: 100nF; C050-025X075
C3, C5: 22pF; C050-025X075
C4, C7: 10uF; E2-5
C6: 47uF; E2,5-7
D2: BAT85; DO34-7
IC1: AY-3-8912A; DIP
IC2: 74HC14N; DIL14
IC3: W65C22S; W65C22-DIP
IC4: 74688N; DIL20
JP1: SYSBUS; 2X20/90
JP2: PINHD-2X4; 2X04
Q1: 1.842; HC49/S
R1, R2, R3, R4: 4K7; 0207/10
R5, R8, R9, R10, R11: 1K; 0207/2V
R6: 1M; 0207/2V
R12: 470R; 0207/2V
R13, R14: 470R; 0207/10
X1: LINE_OUT; STX3100

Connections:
!BANK0: JP1.9
!BANK1: JP1.7
!BANK2: JP1.5
!BANK3: JP1.3
!IOSEL: IC4.1 (!G), JP1.1
!VIA_SEL: IC3.CS2B, IC4.19 (!P=Q)
A0: IC3.RS0, JP1.40
A1: IC3.RS1, JP1.39
A2: IC3.RS2, JP1.37
A3: IC3.RS3, JP1.35
A4: IC4.2 (P0), JP1.33
A5: IC4.4 (P1), JP1.31
A6: IC4.6 (P2), JP1.29
A7: IC4.8 (P3), JP1.27
A8: JP1.25
A9: JP1.23
A10: JP1.21
A11: JP1.19
A12: JP1.17
A13: JP1.15
A14: JP1.13
A15: JP1.11
AY_OSC: IC1.CLOCK, IC2.8 (O)
CA1: IC3.CA1
CA2: IC3.CA2
CB1: IC3.CB1
CB2: IC3.CB2
CH_A: IC1.CH_A, R8.1, R12.2
CH_B: IC1.CH_B, R9.1, R13.2
CH_C: IC1.CH_C, R10.1, R11.1, R14.2
CID0: IC4.3 (Q0), JP2.1, R4.2
CID1: IC4.5 (Q1), JP2.3, R3.2
CID2: IC4.7 (Q2), JP2.5, R2.2
CID3: IC4.9 (Q3), JP2.7, R1.2
D0: IC3.D0, JP1.38
D1: IC3.D1, JP1.36
D2: IC3.D2, JP1.34
D3: IC3.D3, JP1.32
D4: IC3.D4, JP1.30
D5: IC3.D5, JP1.28
D6: IC3.D6, JP1.26
D7: IC3.D7, JP1.24
GND: C1.2, C2.2, C3.2, C5.2, C6.-, C8.2, C9.2, IC1.VSS, IC2.7 (GND), IC2.11 (I), IC2.13 (I), IC3.VSS, IC4.10 (-UB), IC4.11 (P4), IC4.12 (Q4), IC4.13 (P5), IC4.14 (Q5), IC4.15 (P6), IC4.16 (Q6), IC4.17 (P7), IC4.18 (Q7), JP1.8, JP1.10, R1.1, R2.1, R3.1, R4.1, R12.1, R13.1, R14.1, X1.1
IRQB: D2.C, IC3.IRQB
unnamed: D2.A, JP1.14
unnamed: C4.+, R8.2, R10.2
unnamed: C7.+, R9.2, R11.2
unnamed: C7.-, X1.5
unnamed: C4.-, X1.2
unnamed: IC2.4 (O), IC2.5 (I)
unnamed: IC2.6 (O), IC2.9 (I), R5.2
unnamed: C3.1, Q1.2, R5.1, R6.2
unnamed: C5.1, IC2.1 (I), Q1.1, R6.1
unnamed: IC2.2 (O), IC2.3 (I)
NMIB: JP1.16
OSC: JP1.6
PA0: IC1.BC1, IC3.PA0
PA1: IC1.BDIR, IC3.PA1
PA2: IC3.PA2
PA3: IC3.PA3
PA4: IC3.PA4
PA5: IC3.PA5
PA6: IC3.PA6
PA7: IC3.PA7
PB0: IC1.DA0, IC3.PB0
PB1: IC1.DA1, IC3.PB1
PB2: IC1.DA2, IC3.PB2
PB3: IC1.DA3, IC3.PB3
PB4: IC1.DA4, IC3.PB4
PB5: IC1.DA5, IC3.PB5
PB6: IC1.DA6, IC3.PB6
PB7: IC1.DA7, IC3.PB7
PHI2: IC3.PHI2, JP1.20
RDY: JP1.12
RESB: IC1.!RESET, IC3.RESB, JP1.18
RWB: IC3.RWB, JP1.22
VCC: C1.1, C2.1, C6.+, C8.1, C9.1, IC1.BC2, IC1.VCC, IC2.14 (VCC), IC3.CS1, IC3.VDD, IC4.20 (+UB), JP1.2, JP1.4, JP2.2, JP2.4, JP2.6, JP2.8

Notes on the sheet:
Card Bus
Address Select
Address Decoder
Versatile Interface Adaptor
Audio Generation
Output Stage
AY Oscillator
Spare

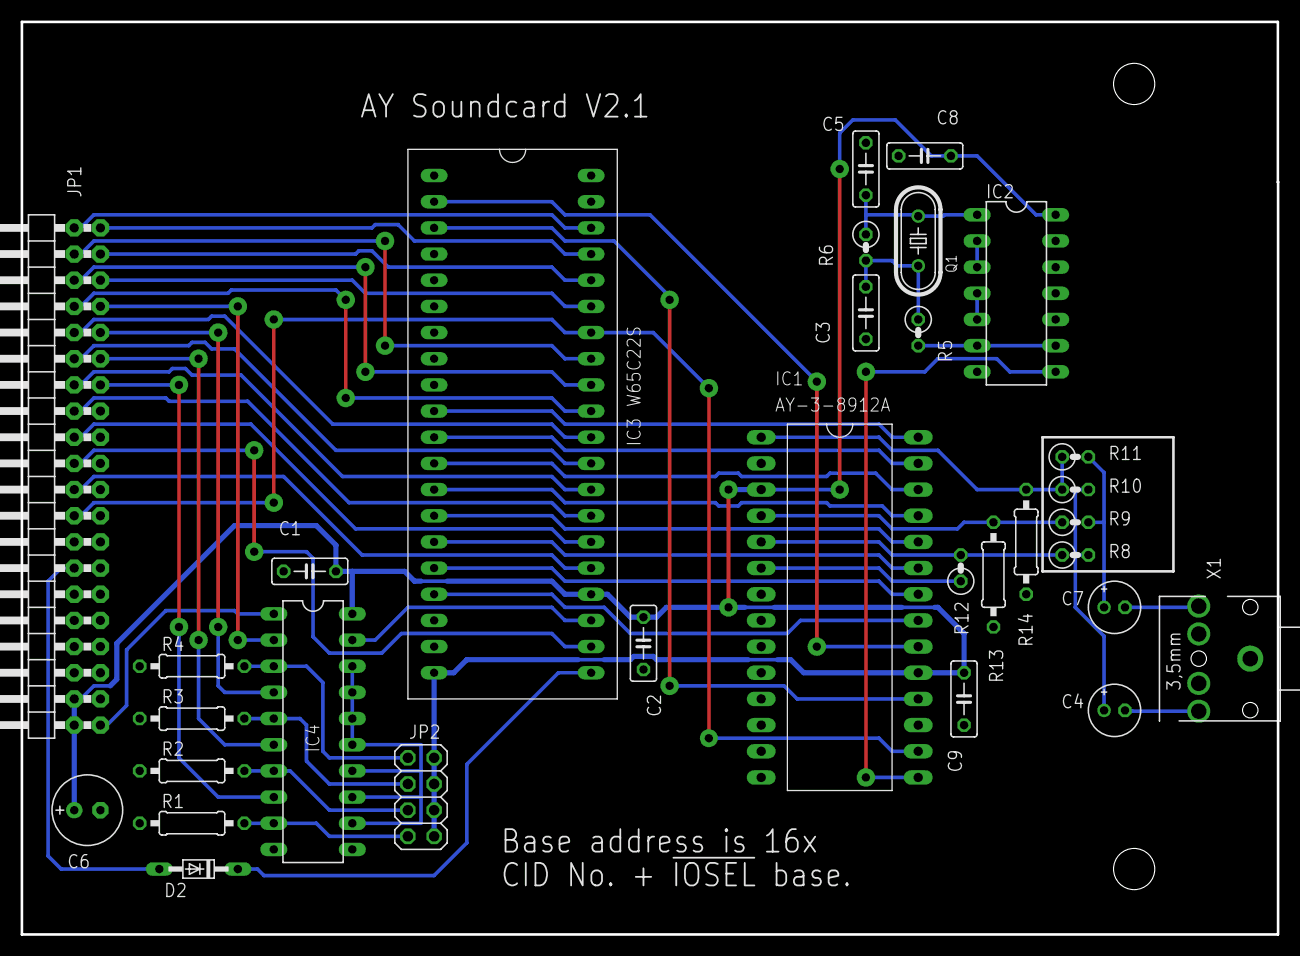
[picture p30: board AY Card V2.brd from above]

Board: 2 copper layers, 121.9 x 88.6 mm, 31 parts (0 on the bottom side), 52 nets.

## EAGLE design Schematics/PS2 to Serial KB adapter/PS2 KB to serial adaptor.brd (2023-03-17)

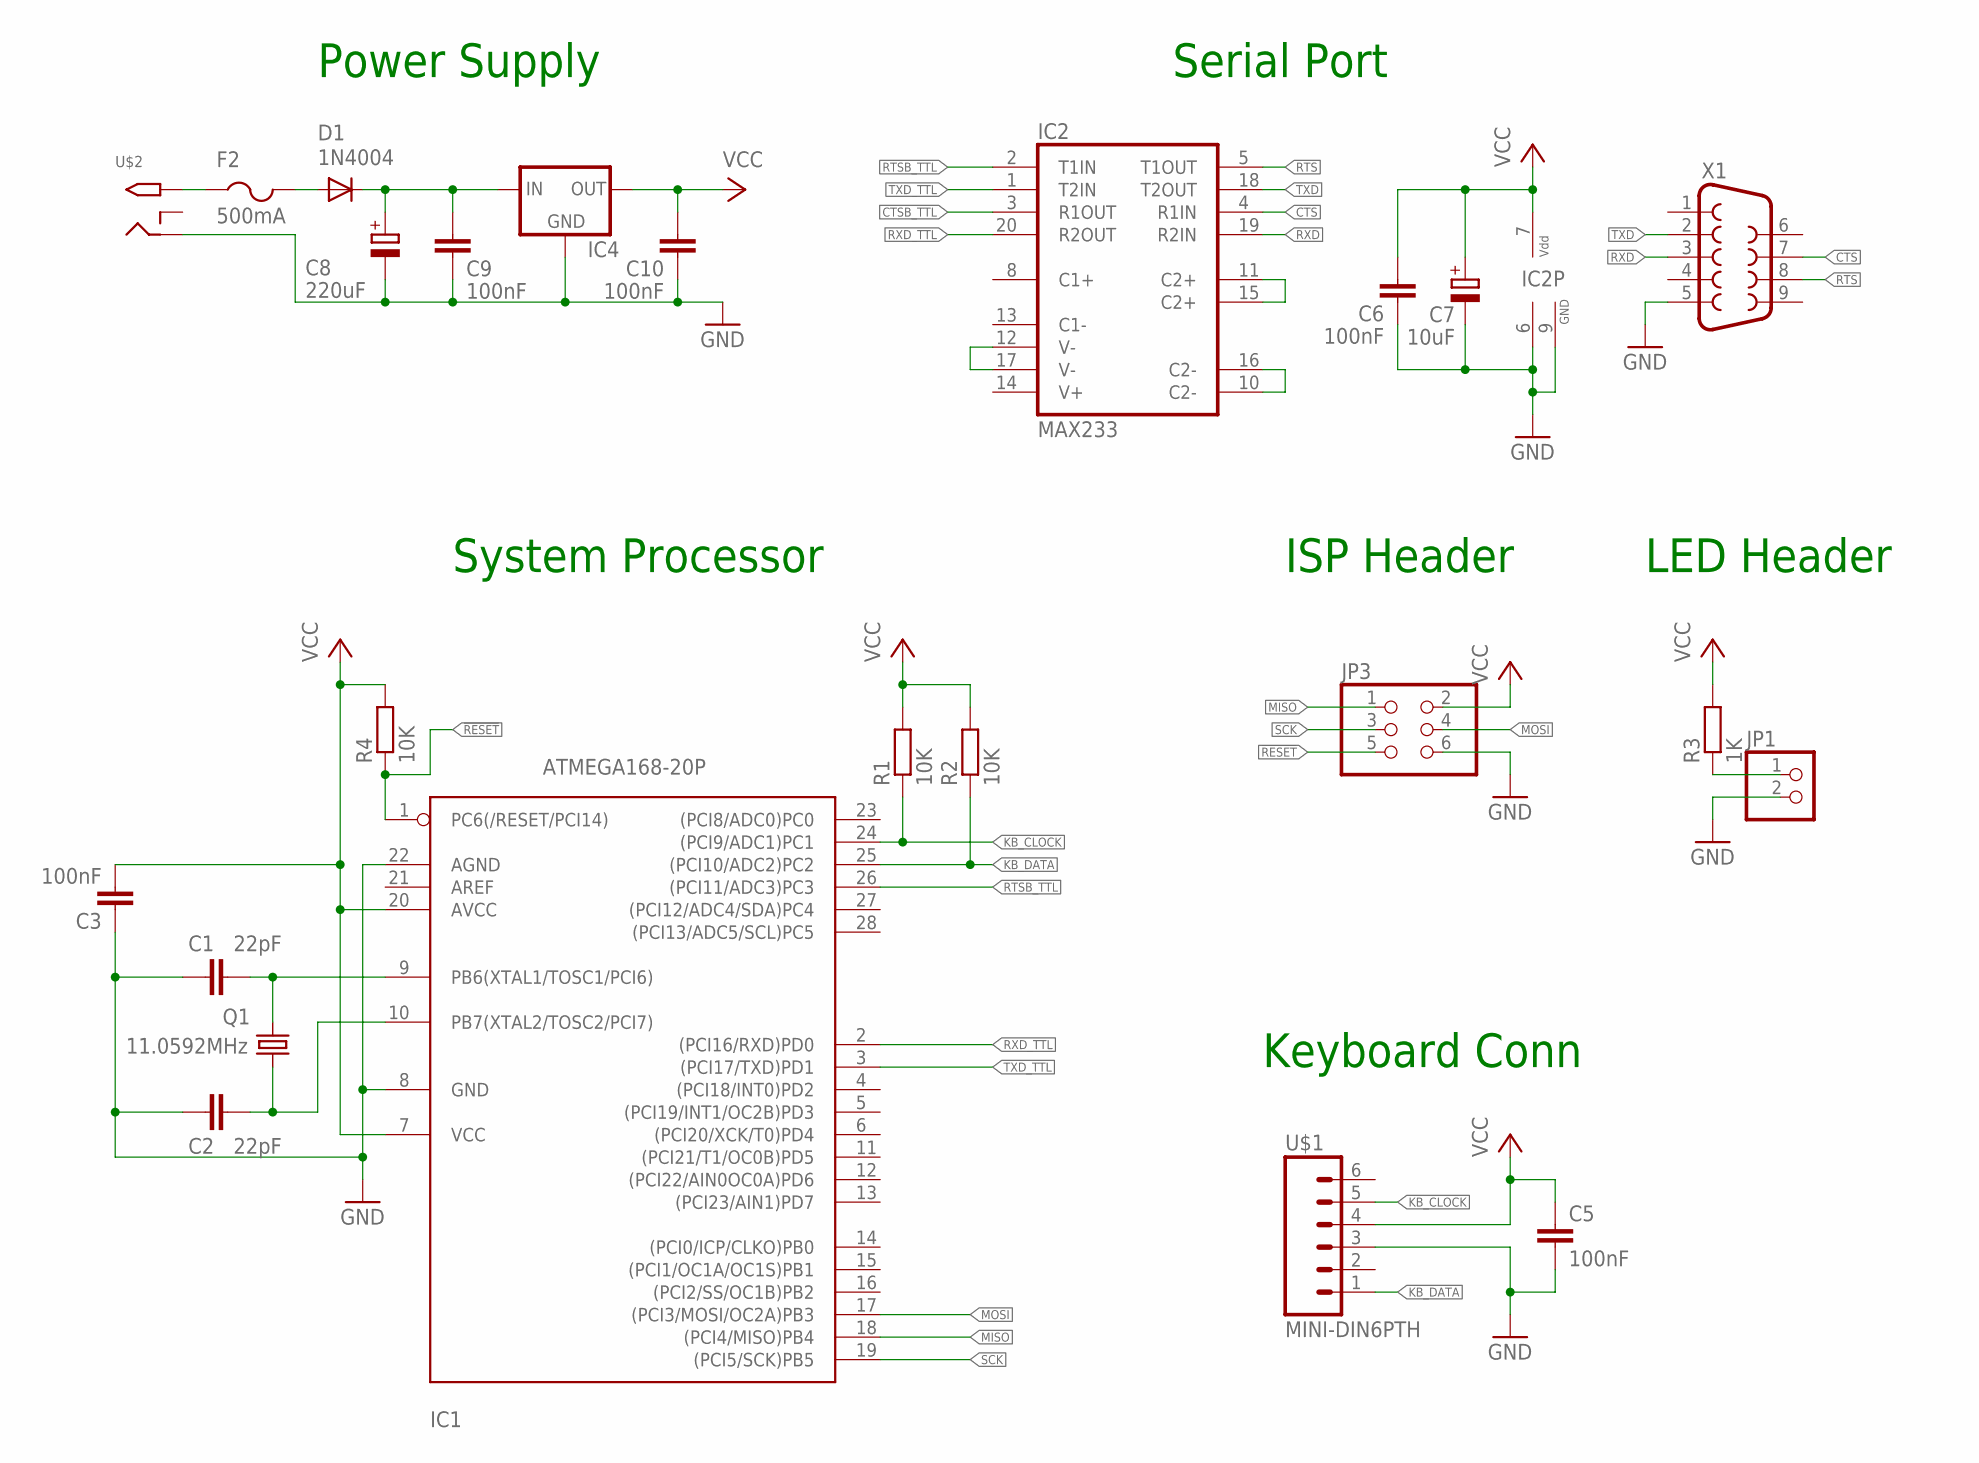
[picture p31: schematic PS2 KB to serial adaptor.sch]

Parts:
C1, C2: 22pF; C025-024X044
C3, C6, C9, C10: 100nF; C025-024X044
C5: 100nF; C050-024X044
C7: 10uF; E2,5-5
C8: 220uF; E2,5-7
D1: 1N4004; DO41-10
F2: 500mA; 1812
IC1: ATMEGA168-20P; DIL28-3
IC2: MAX233; DIL20
IC4: 78XXL
JP1: PINHD-1X2; 1X02
JP3: PINHD-2X3; 2X03
Q1: 11.0592MHz; HC49U-V
R1, R2: 10K; 0207/2V
R3: 1K; 0207/2V
R4: 10K; 0207/7
U$1: MINI-DIN6PTH; MINI-DIN6
U$2: 2.1MMJACKTHM; PJ-102A
X1: F09HP

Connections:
!RESET: IC1.1 (PC6(/RESET/PCI14)), JP3.5, R4.1
CTS: IC2.4 (R1IN), X1.7
CTSB_TTL: IC2.3 (R1OUT)
GND: C1.1, C2.1, C3.1, C5.1, C6.1, C7.-, C8.-, C9.1, C10.1, IC1.8 (GND), IC1.22 (AGND), IC2.6 (GND), IC2.9 (GND), IC4.GND, JP1.2, JP3.6, U$1.3, U$2.RING, X1.5
KB_CLOCK: IC1.24 ((PCI9/ADC1)PC1), R1.1, U$1.5
KB_DATA: IC1.25 ((PCI10/ADC2)PC2), R2.1, U$1.1
MISO: IC1.18 ((PCI4/MISO)PB4), JP3.1
MOSI: IC1.17 ((PCI3/MOSI/OC2A)PB3), JP3.4
unnamed: IC2.12 (V-), IC2.17 (V-)
unnamed: IC2.11 (C2+), IC2.15 (C2+)
unnamed: IC2.10 (C2-), IC2.16 (C2-)
unnamed: C8.+, C9.2, D1.C, IC4.IN
unnamed: JP1.1, R3.1
unnamed: D1.A, F2.2
unnamed: C1.2, IC1.9 (PB6(XTAL1/TOSC1/PCI6)), Q1.2
unnamed: C2.2, IC1.10 (PB7(XTAL2/TOSC2/PCI7)), Q1.1
unnamed: F2.1, U$2.TIP
RTS: IC2.5 (T1OUT), X1.8
RTSB_TTL: IC1.26 ((PCI11/ADC3)PC3), IC2.2 (T1IN)
RXD: IC2.19 (R2IN), X1.3
RXD_TTL: IC1.2 ((PCI16/RXD)PD0), IC2.20 (R2OUT)
SCK: IC1.19 ((PCI5/SCK)PB5), JP3.3
TXD: IC2.18 (T2OUT), X1.2
TXD_TTL: IC1.3 ((PCI17/TXD)PD1), IC2.1 (T2IN)
VCC: C3.2, C5.2, C6.2, C7.+, C10.2, IC1.7 (VCC), IC1.20 (AVCC), IC2.7 (VDD), IC4.OUT, JP3.2, R1.2, R2.2, R3.2, R4.2, U$1.4

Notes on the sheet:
Power Supply
Keyboard Conn
Serial Port
System Processor
ISP Header
LED Header

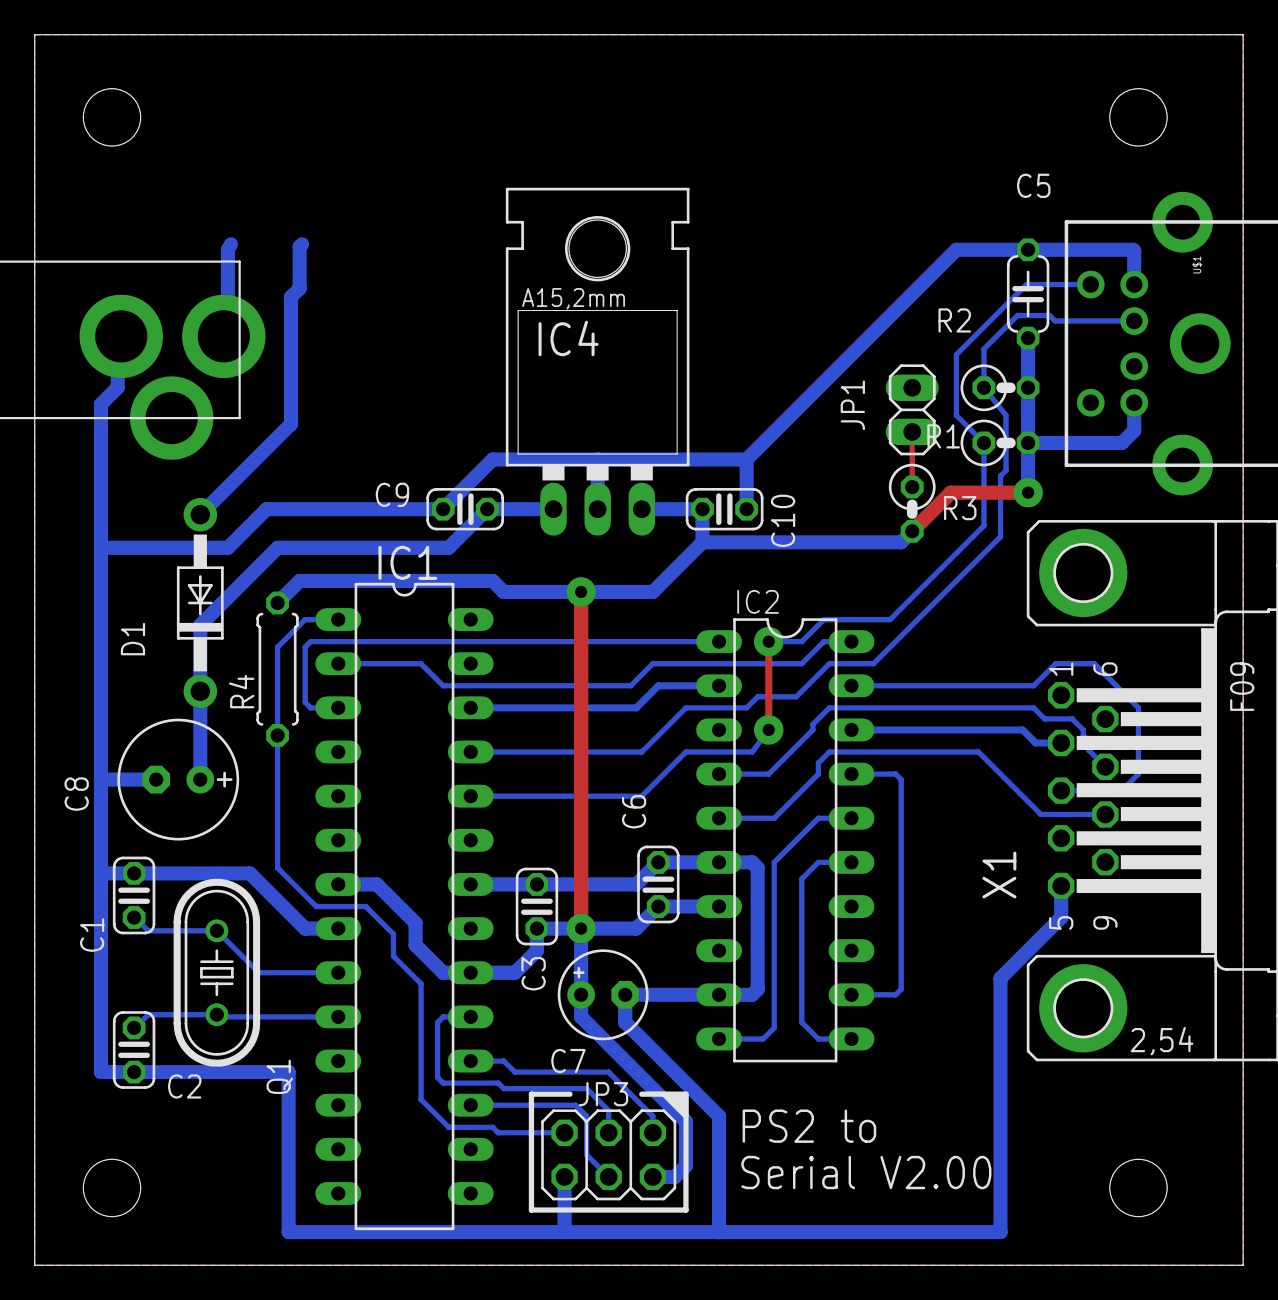
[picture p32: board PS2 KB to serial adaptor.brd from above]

Board: 2 copper layers, 69.5 x 70.8 mm, 24 parts (1 on the bottom side), 24 nets.

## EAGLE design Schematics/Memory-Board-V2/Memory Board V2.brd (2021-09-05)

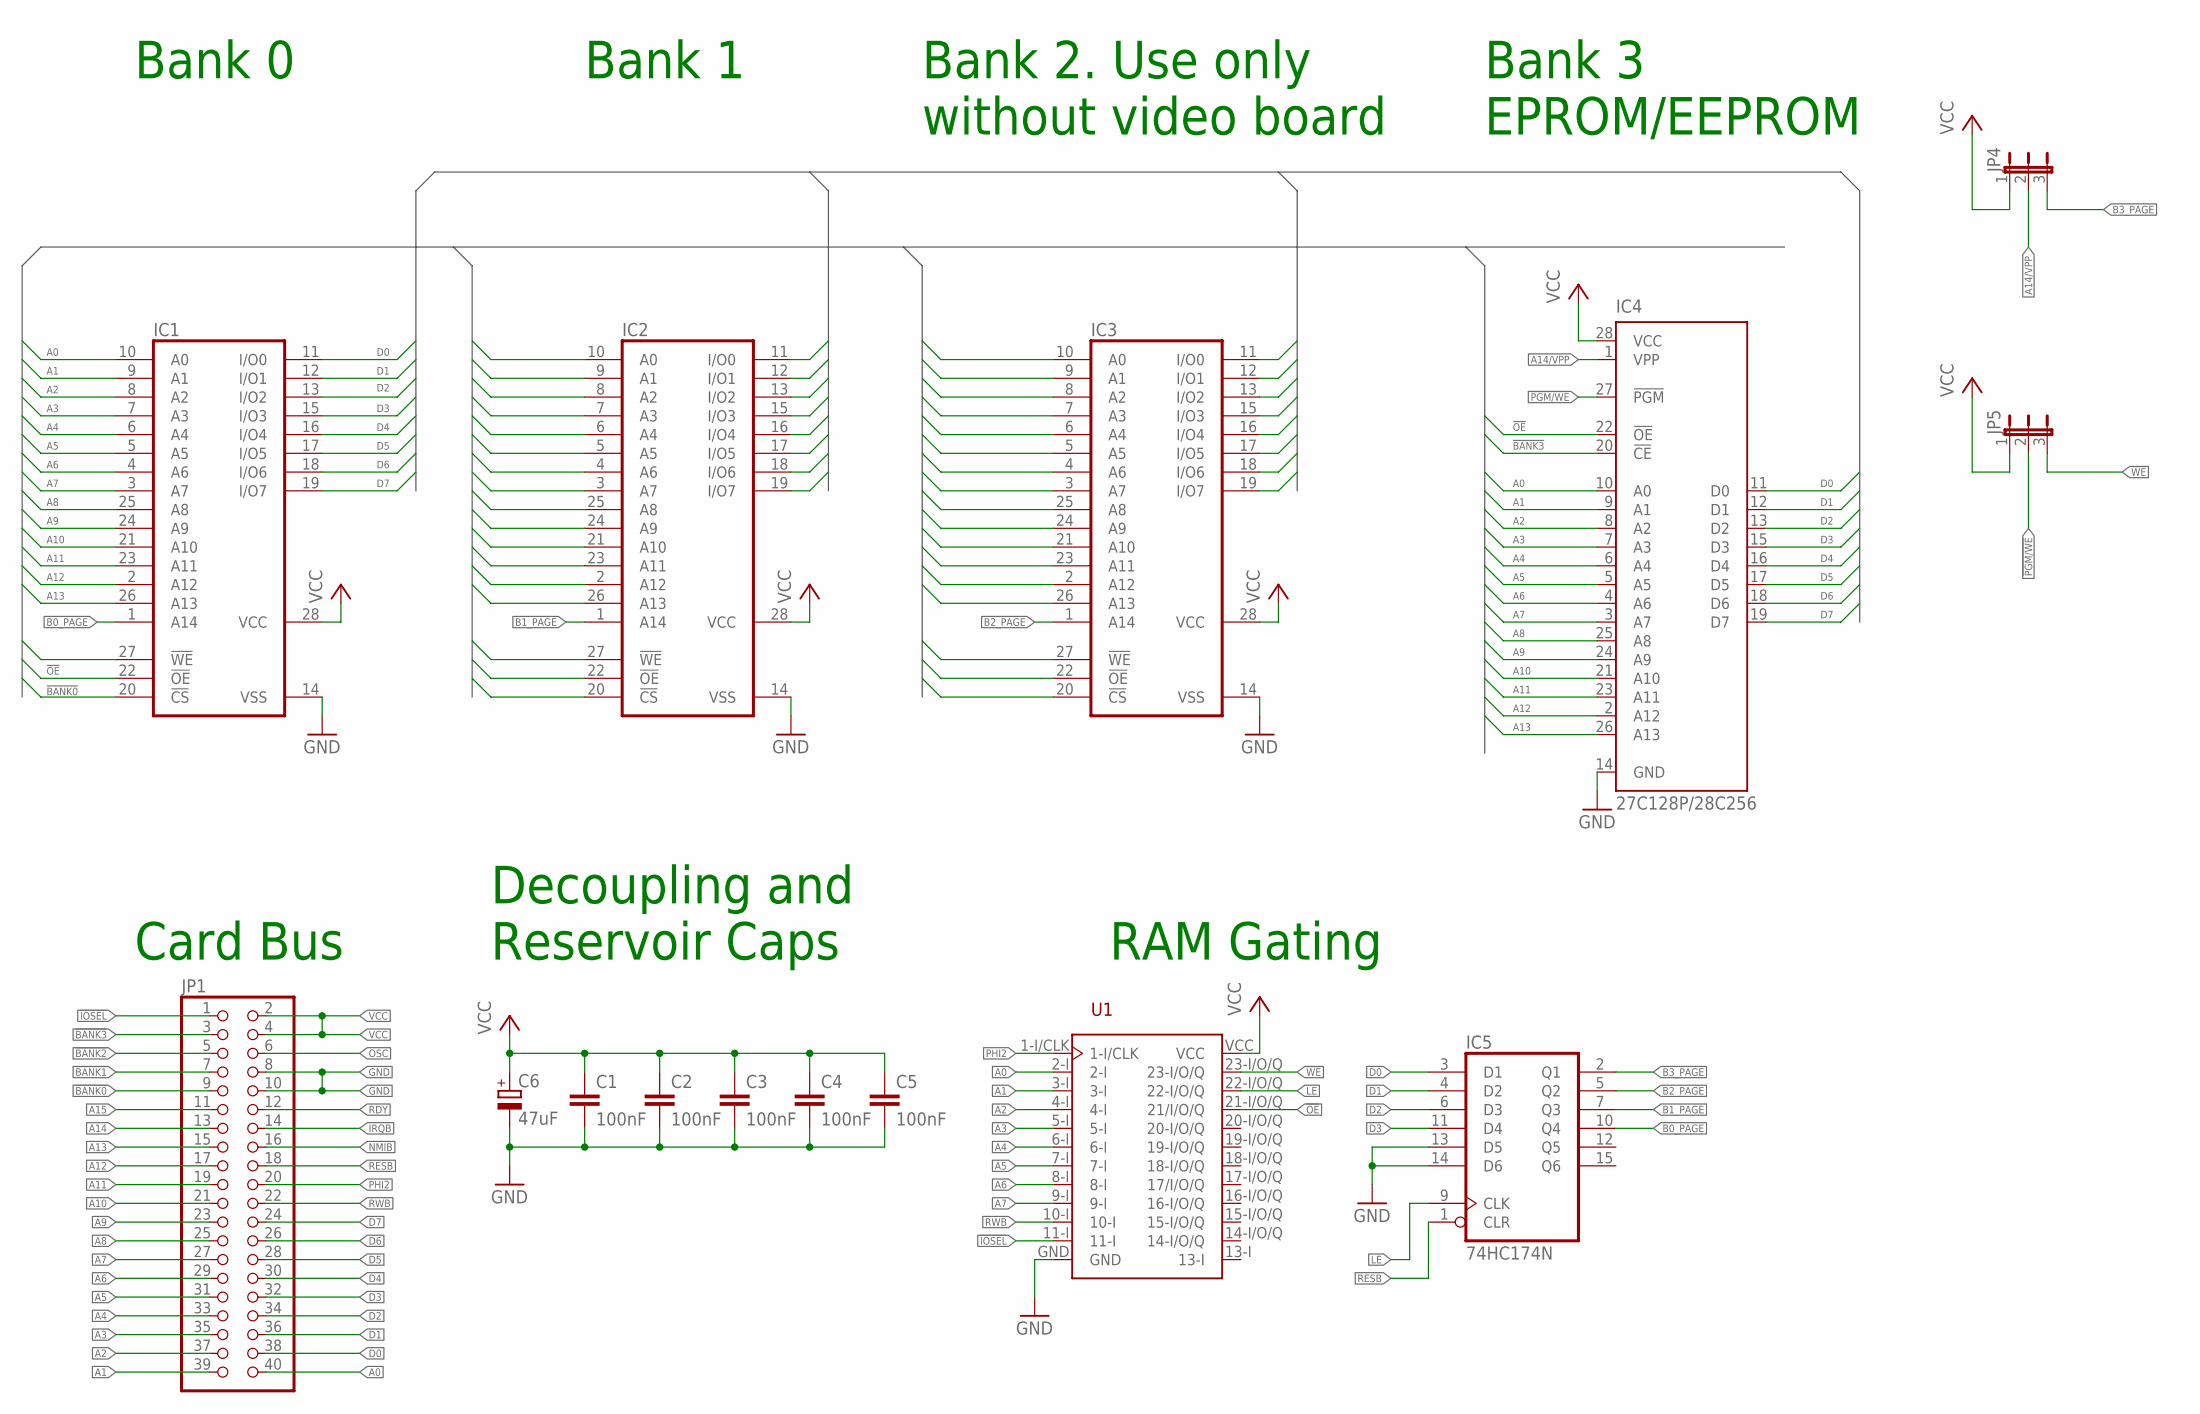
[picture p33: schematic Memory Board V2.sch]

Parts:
C1, C2, C3, C4, C5: 100nF; C050-025X075
C6: 47uF; E2,5-7
IC1, IC2, IC3: 62256P; DIL28-6
IC4: 27C128P/28C256; DIL28-6
IC5: 74HC174N; DIL16
JP1: PINHD-2X20/90; 2X20/90
JP4, JP5: JP2E; JP2
U1: GAL22V10D-DIP; DIP24

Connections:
!BANK0: IC1.20 (!CS), JP1.9
!BANK1: IC2.20 (!CS), JP1.7
!BANK2: IC3.20 (!CS), JP1.5
!BANK3: IC4.20 (!CE), JP1.3
!IOSEL: JP1.1, U1.11-I
!OE: IC1.22 (!OE), IC2.22 (!OE), IC3.22 (!OE), IC4.22 (!OE), U1.21-I/O/Q (21/I/O/Q)
!PGM/WE: IC4.27 (!PGM), JP5.2
!WE: IC1.27 (!WE), IC2.27 (!WE), IC3.27 (!WE), JP5.3, U1.23-I/O/Q
A0: IC1.10 (A0), IC2.10 (A0), IC3.10 (A0), IC4.10 (A0), JP1.40, U1.2-I
A1: IC1.9 (A1), IC2.9 (A1), IC3.9 (A1), IC4.9 (A1), JP1.39, U1.3-I
A2: IC1.8 (A2), IC2.8 (A2), IC3.8 (A2), IC4.8 (A2), JP1.37, U1.4-I
A3: IC1.7 (A3), IC2.7 (A3), IC3.7 (A3), IC4.7 (A3), JP1.35, U1.5-I
A4: IC1.6 (A4), IC2.6 (A4), IC3.6 (A4), IC4.6 (A4), JP1.33, U1.6-I
A5: IC1.5 (A5), IC2.5 (A5), IC3.5 (A5), IC4.5 (A5), JP1.31, U1.7-I
A6: IC1.4 (A6), IC2.4 (A6), IC3.4 (A6), IC4.4 (A6), JP1.29, U1.8-I
A7: IC1.3 (A7), IC2.3 (A7), IC3.3 (A7), IC4.3 (A7), JP1.27, U1.9-I
A8: IC1.25 (A8), IC2.25 (A8), IC3.25 (A8), IC4.25 (A8), JP1.25
A9: IC1.24 (A9), IC2.24 (A9), IC3.24 (A9), IC4.24 (A9), JP1.23
A10: IC1.21 (A10), IC2.21 (A10), IC3.21 (A10), IC4.21 (A10), JP1.21
A11: IC1.23 (A11), IC2.23 (A11), IC3.23 (A11), IC4.23 (A11), JP1.19
A12: IC1.2 (A12), IC2.2 (A12), IC3.2 (A12), IC4.2 (A12), JP1.17
A13: IC1.26 (A13), IC2.26 (A13), IC3.26 (A13), IC4.26 (A13), JP1.15
A14: JP1.13
A14/VPP: IC4.1 (VPP), JP4.2
A15: JP1.11
B0_PAGE: IC1.1 (A14), IC5.10 (Q4)
B1_PAGE: IC2.1 (A14), IC5.7 (Q3)
B2_PAGE: IC3.1 (A14), IC5.5 (Q2)
B3_PAGE: IC5.2 (Q1), JP4.3
D0: IC1.11 (I/O0), IC2.11 (I/O0), IC3.11 (I/O0), IC4.11 (D0), IC5.3 (D1), JP1.38
D1: IC1.12 (I/O1), IC2.12 (I/O1), IC3.12 (I/O1), IC4.12 (D1), IC5.4 (D2), JP1.36
D2: IC1.13 (I/O2), IC2.13 (I/O2), IC3.13 (I/O2), IC4.13 (D2), IC5.6 (D3), JP1.34
D3: IC1.15 (I/O3), IC2.15 (I/O3), IC3.15 (I/O3), IC4.15 (D3), IC5.11 (D4), JP1.32
D4: IC1.16 (I/O4), IC2.16 (I/O4), IC3.16 (I/O4), IC4.16 (D4), JP1.30
D5: IC1.17 (I/O5), IC2.17 (I/O5), IC3.17 (I/O5), IC4.17 (D5), JP1.28
D6: IC1.18 (I/O6), IC2.18 (I/O6), IC3.18 (I/O6), IC4.18 (D6), JP1.26
D7: IC1.19 (I/O7), IC2.19 (I/O7), IC3.19 (I/O7), IC4.19 (D7), JP1.24
GND: C1.2, C2.2, C3.2, C4.2, C5.2, C6.-, IC1.14 (VSS), IC2.14 (VSS), IC3.14 (VSS), IC4.14 (GND), IC5.8 (GND), IC5.13 (D5), IC5.14 (D6), JP1.8, JP1.10, U1.GND
IRQB: JP1.14
LE: IC5.9 (CLK), U1.22-I/O/Q
NMIB: JP1.16
OSC: JP1.6
PHI2: JP1.20, U1.1-I/CLK
RDY: JP1.12
RESB: IC5.1 (CLR), JP1.18
RWB: JP1.22, U1.10-I
VCC: C1.1, C2.1, C3.1, C4.1, C5.1, C6.+, IC1.28 (VCC), IC2.28 (VCC), IC3.28 (VCC), IC4.28 (VCC), IC5.16 (VCC), JP1.2, JP1.4, JP4.1, JP5.1, U1.VCC

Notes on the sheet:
Card Bus
Bank 0
Bank 3 EPROM/EEPROM
Bank 1
Bank 2. Use only without video board
Decoupling and Reservoir Caps
RAM Gating

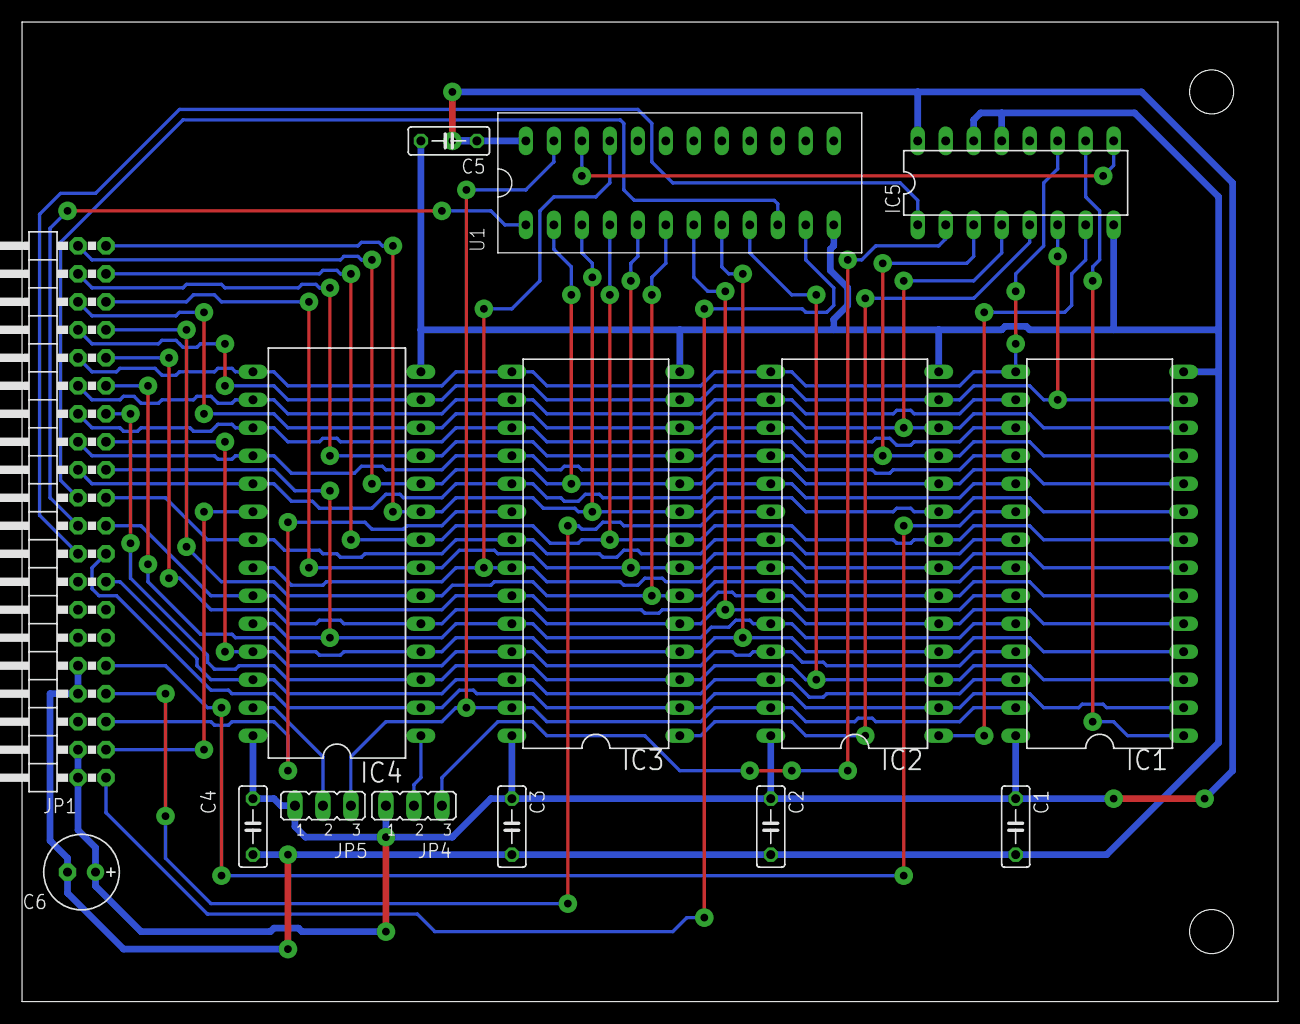
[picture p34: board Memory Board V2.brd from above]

Board: 2 copper layers, 114.0 x 88.9 mm, 15 parts (0 on the bottom side), 41 nets.

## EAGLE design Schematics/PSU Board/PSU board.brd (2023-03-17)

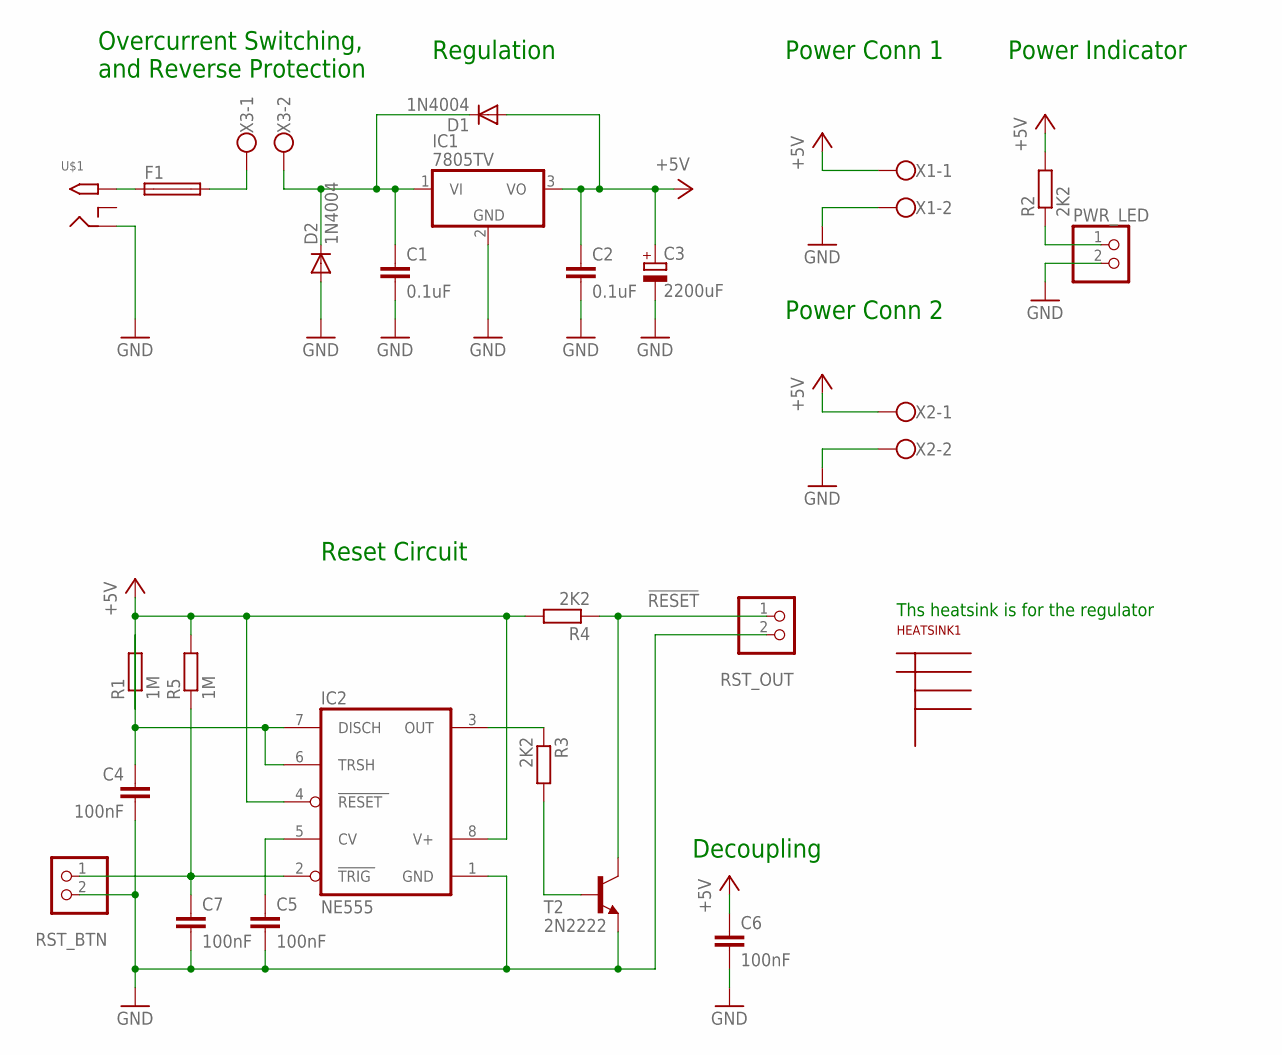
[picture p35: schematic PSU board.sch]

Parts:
C1, C2: 0.1uF; C025-025X050
C3: 2200uF; E7,5-18
C4, C5, C6, C7: 100nF; C025-025X050
D1, D2: 1N4004; DO41-10
F1: SH22,5A
HEATSINK1: FISCHER-50_HSINK; FISHER-50
IC1: 7805TV; TO220V
IC2: NE555; DIL08
PWR_LED: PINHD-1X2; 1X02
R1: 1M; 0207/2V
R2: 2K2; 0207/10
R3, R4: 2K2; 0207/2V
R5: 1M; 0207/10
RST_BTN: PINHD-1X2; 1X02
RST_OUT: PINHD-1X2; 1X02
T2: 2N2222; TO18
U$1: 2.1MMJACKTHM; PJ-102A
X1, X2, X3: W237-102

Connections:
!RESET: R4.1, RST_OUT.1, T2.3 (C)
+5V: C2.1, C3.+, C6.1, D1.A, IC1.3 (VO), IC2.4 (RESET), IC2.8 (V+), R1.1, R2.2, R4.2, R5.2, X1.1, X2.1
+V_IN: C1.1, D1.C, D2.C, IC1.1 (VI), X3.2
GND: C1.2, C2.2, C3.-, C4.2, C5.2, C6.2, C7.2, D2.A, IC1.2 (GND), IC2.1 (GND), PWR_LED.2, RST_BTN.2, RST_OUT.2, T2.1 (E), U$1.RING, X1.2, X2.2
unnamed: PWR_LED.1, R2.1
unnamed: F1.2, X3.1
unnamed: F1.1, U$1.TIP
unnamed: C4.1, IC2.6 (TRSH), IC2.7 (DISCH), R1.2
unnamed: C5.1, IC2.5 (CV)
unnamed: C7.1, IC2.2 (TRIG), R5.1, RST_BTN.1
unnamed: R3.2, T2.2 (B)
unnamed: IC2.3 (OUT), R3.1

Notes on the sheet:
Decoupling
Regulation
Overcurrent Switching, and Reverse Protection
Power Indicator
Reset Circuit
Power Conn 1
Power Conn 2
Ths heatsink is for the regulator

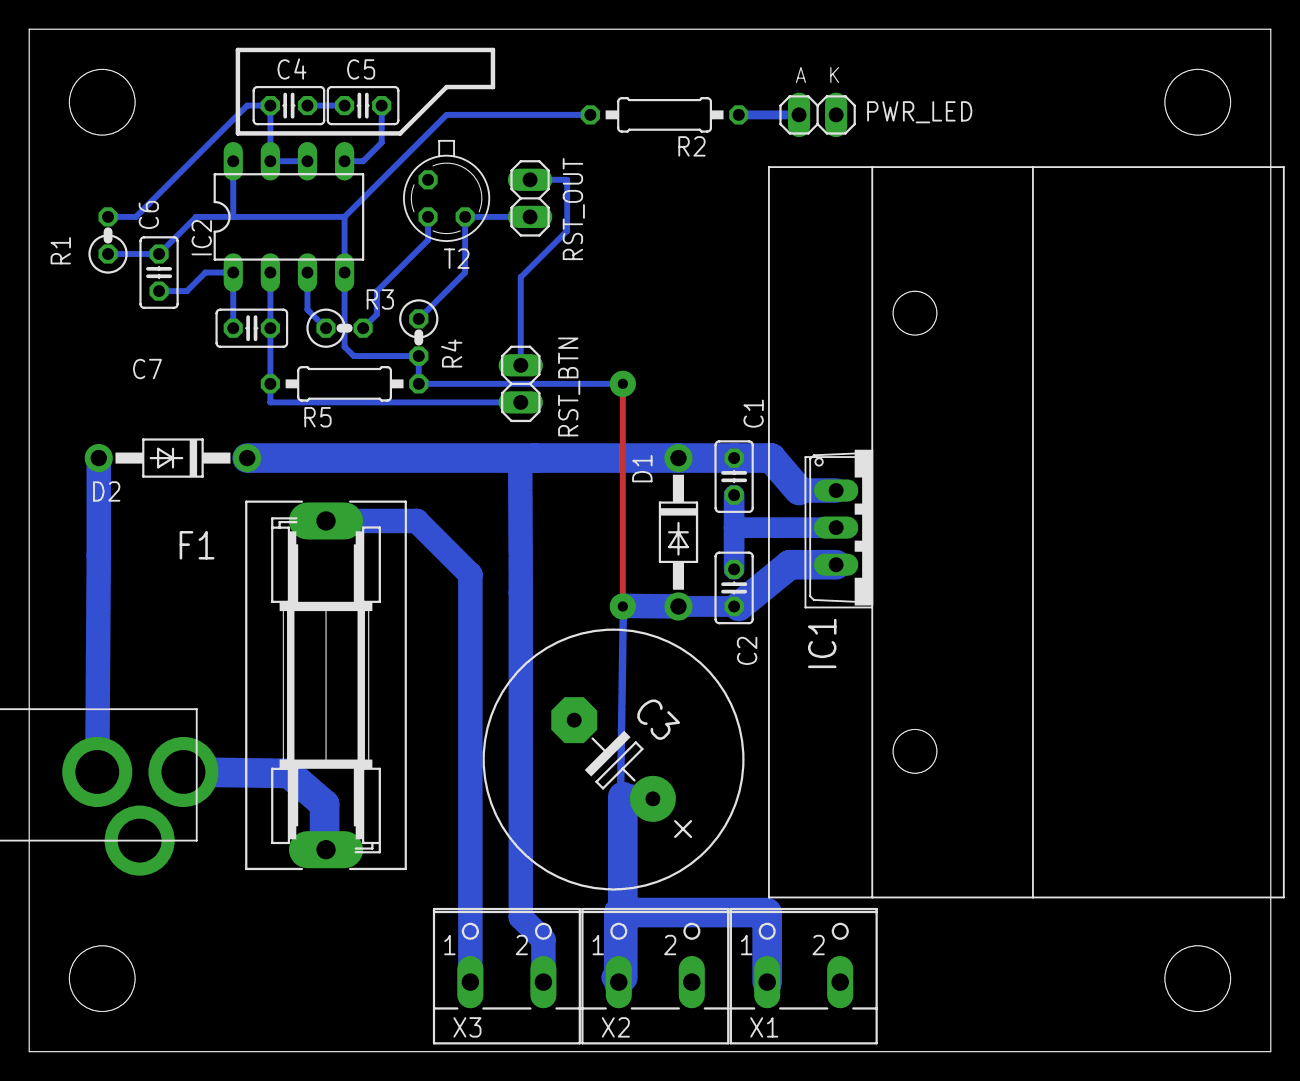
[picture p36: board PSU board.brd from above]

Board: 2 copper layers, 85.0 x 70.0 mm, 26 parts (0 on the bottom side), 12 nets.

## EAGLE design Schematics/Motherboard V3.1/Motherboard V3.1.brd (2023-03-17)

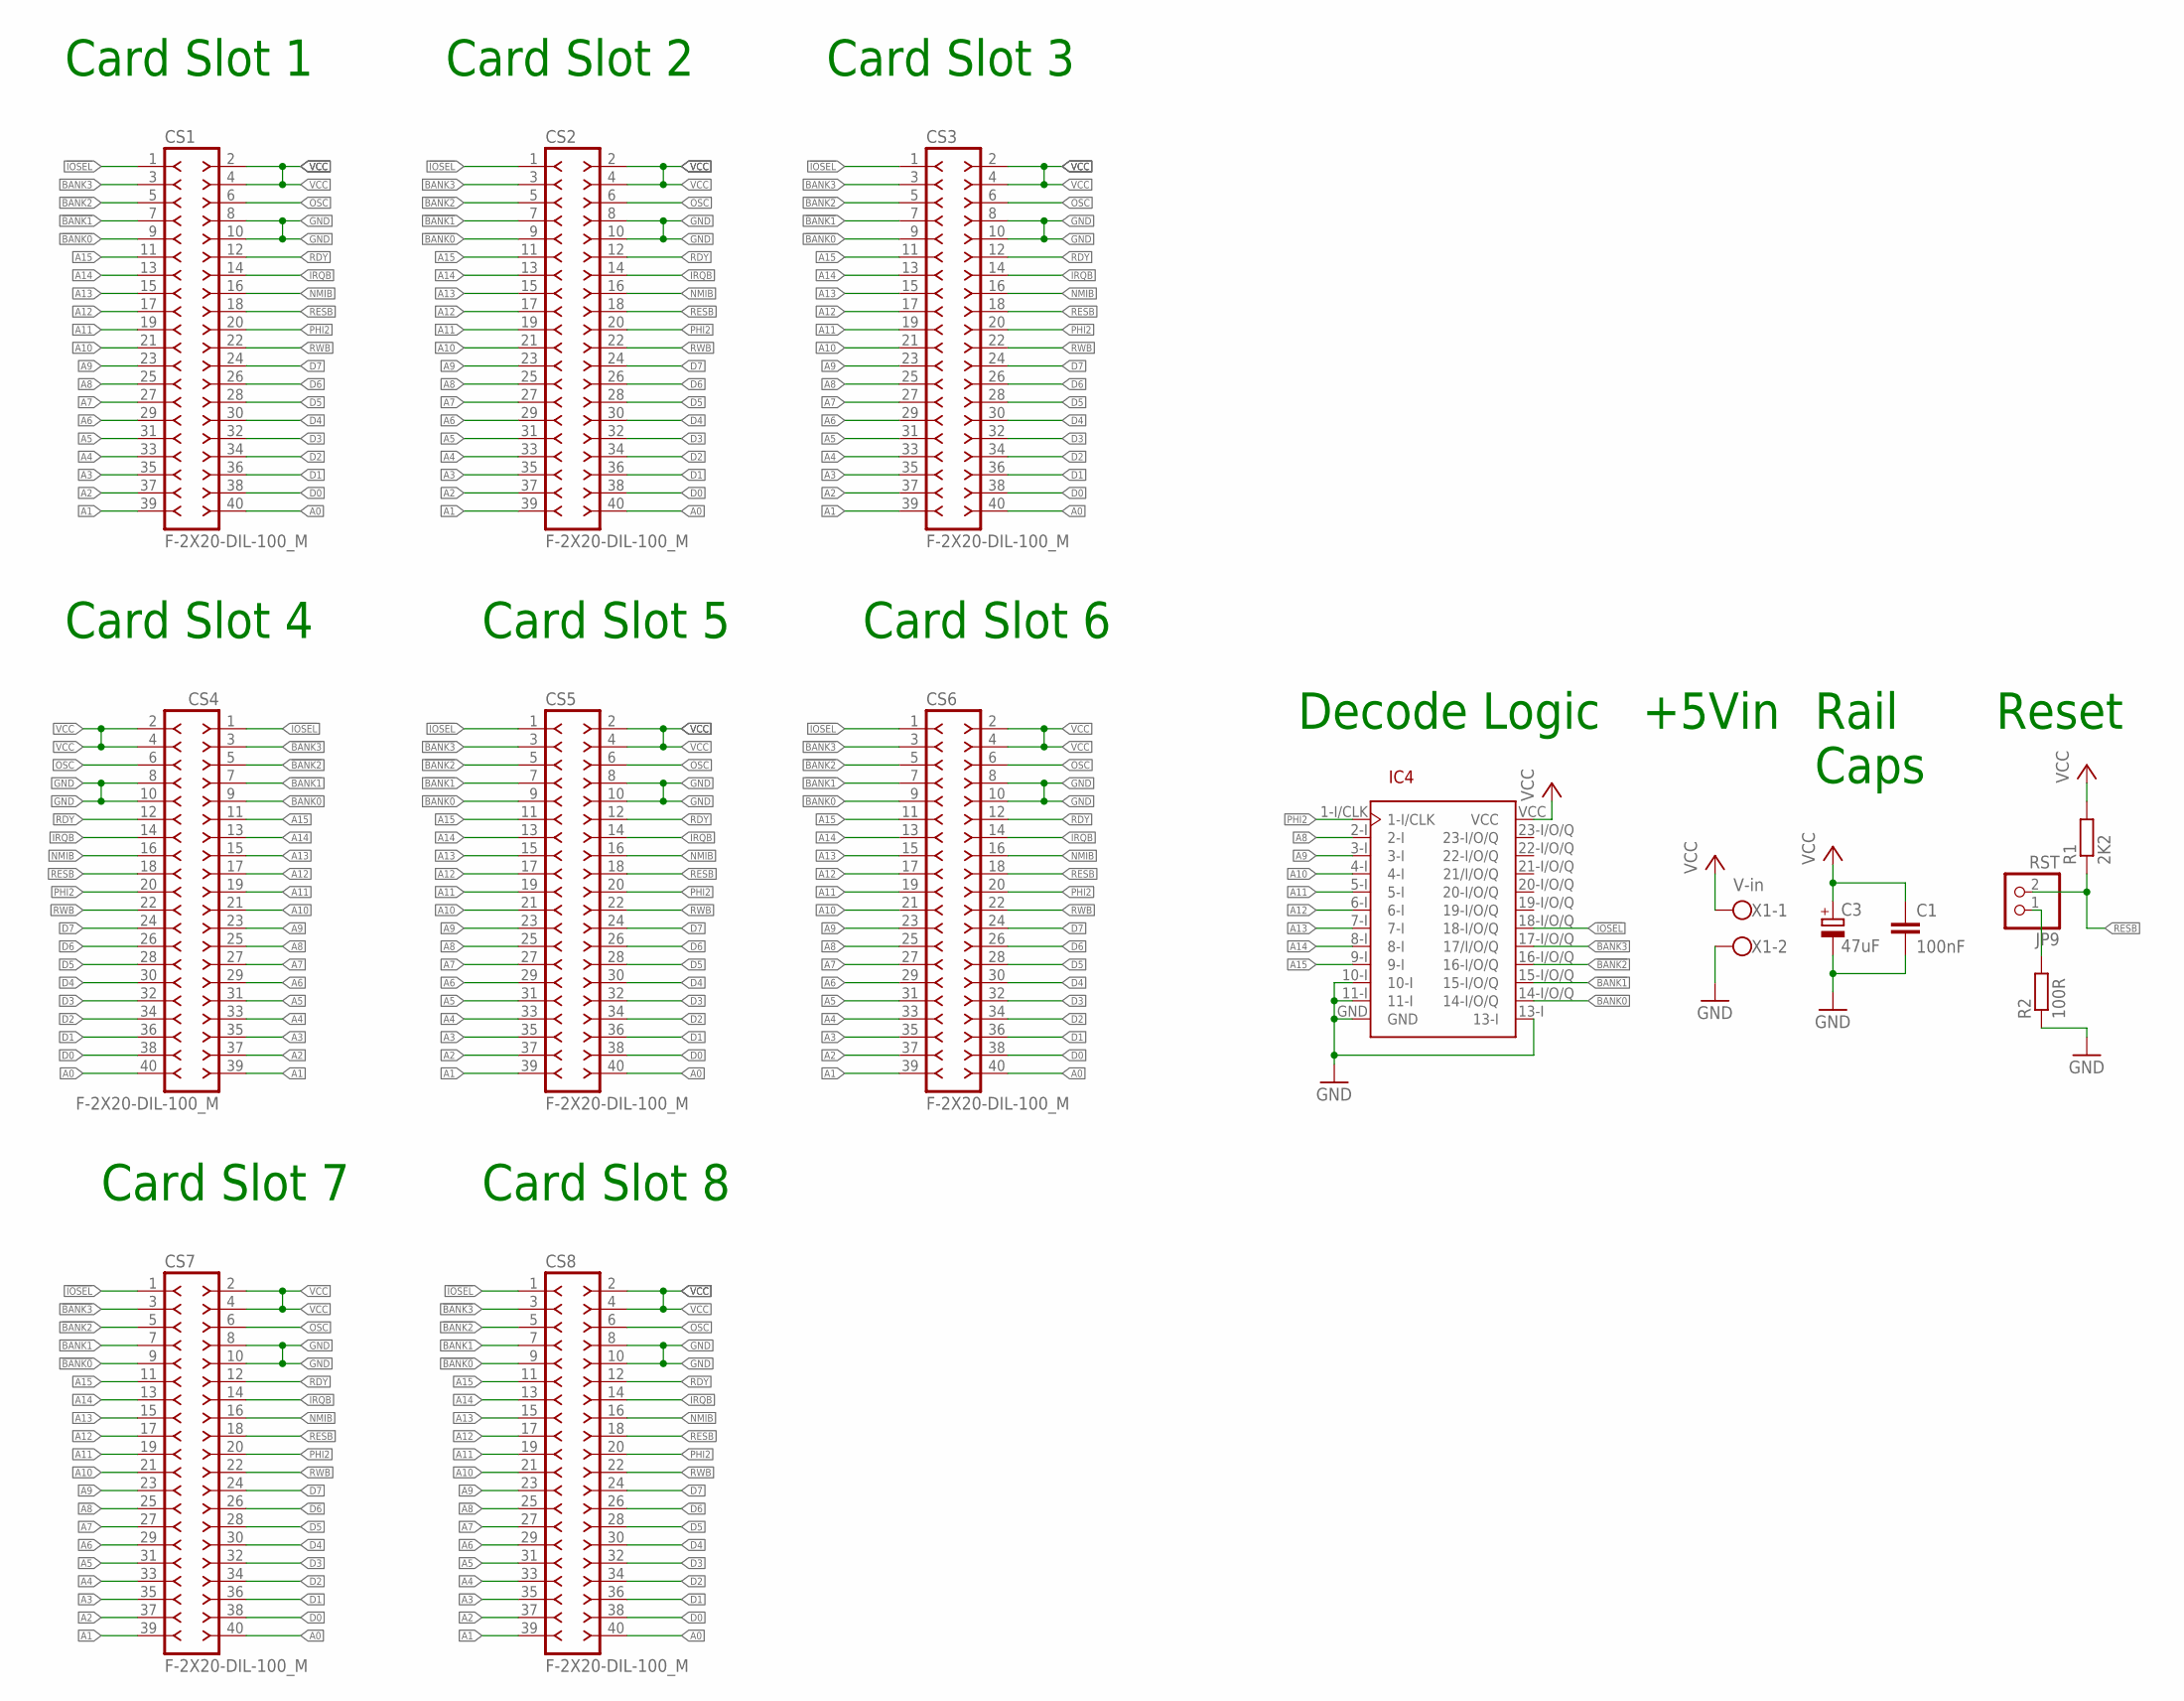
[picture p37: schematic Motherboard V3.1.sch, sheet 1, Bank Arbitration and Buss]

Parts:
C1: 100nF; C050-025X075
C3: 47uF; E2,5-7
CS1, CS2, CS3, CS4, CS5, CS6, CS7, CS8: F-2X20-DIL-100_M; DIL-100-2X20_M
IC4: GAL22V10D-7LP; DIP24
JP9: RST; 1X02
R1: 2K2; 0207/10
R2: 100R; 0207/10
X1: V-in; W237-102

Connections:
!BANK0: CS1.9, CS2.9, CS3.9, CS4.9, CS5.9, CS6.9, CS7.9, CS8.9, IC4.14-I/O/Q
!BANK1: CS1.7, CS2.7, CS3.7, CS4.7, CS5.7, CS6.7, CS7.7, CS8.7, IC4.15-I/O/Q
!BANK2: CS1.5, CS2.5, CS3.5, CS4.5, CS5.5, CS6.5, CS7.5, CS8.5, IC4.16-I/O/Q
!BANK3: CS1.3, CS2.3, CS3.3, CS4.3, CS5.3, CS6.3, CS7.3, CS8.3, IC4.17-I/O/Q (17/I/O/Q)
!IOSEL: CS1.1, CS2.1, CS3.1, CS4.1, CS5.1, CS6.1, CS7.1, CS8.1, IC4.18-I/O/Q
A0: CS1.40, CS2.40, CS3.40, CS4.40, CS5.40, CS6.40, CS7.40, CS8.40; also elsewhere on the board
A1: CS1.39, CS2.39, CS3.39, CS4.39, CS5.39, CS6.39, CS7.39, CS8.39; also elsewhere on the board
A2: CS1.37, CS2.37, CS3.37, CS4.37, CS5.37, CS6.37, CS7.37, CS8.37; also elsewhere on the board
A3: CS1.35, CS2.35, CS3.35, CS4.35, CS5.35, CS6.35, CS7.35, CS8.35; also elsewhere on the board
A4: CS1.33, CS2.33, CS3.33, CS4.33, CS5.33, CS6.33, CS7.33, CS8.33; also elsewhere on the board
A5: CS1.31, CS2.31, CS3.31, CS4.31, CS5.31, CS6.31, CS7.31, CS8.31; also elsewhere on the board
A6: CS1.29, CS2.29, CS3.29, CS4.29, CS5.29, CS6.29, CS7.29, CS8.29; also elsewhere on the board
A7: CS1.27, CS2.27, CS3.27, CS4.27, CS5.27, CS6.27, CS7.27, CS8.27; also elsewhere on the board
A8: CS1.25, CS2.25, CS3.25, CS4.25, CS5.25, CS6.25, CS7.25, CS8.25, IC4.2-I; also elsewhere on the board
A9: CS1.23, CS2.23, CS3.23, CS4.23, CS5.23, CS6.23, CS7.23, CS8.23, IC4.3-I; also elsewhere on the board
A10: CS1.21, CS2.21, CS3.21, CS4.21, CS5.21, CS6.21, CS7.21, CS8.21, IC4.4-I; also elsewhere on the board
A11: CS1.19, CS2.19, CS3.19, CS4.19, CS5.19, CS6.19, CS7.19, CS8.19, IC4.5-I; also elsewhere on the board
A12: CS1.17, CS2.17, CS3.17, CS4.17, CS5.17, CS6.17, CS7.17, CS8.17, IC4.6-I; also elsewhere on the board
A13: CS1.15, CS2.15, CS3.15, CS4.15, CS5.15, CS6.15, CS7.15, CS8.15, IC4.7-I; also elsewhere on the board
A14: CS1.13, CS2.13, CS3.13, CS4.13, CS5.13, CS6.13, CS7.13, CS8.13, IC4.8-I; also elsewhere on the board
A15: CS1.11, CS2.11, CS3.11, CS4.11, CS5.11, CS6.11, CS7.11, CS8.11, IC4.9-I; also elsewhere on the board
D0: CS1.38, CS2.38, CS3.38, CS4.38, CS5.38, CS6.38, CS7.38, CS8.38; also elsewhere on the board
D1: CS1.36, CS2.36, CS3.36, CS4.36, CS5.36, CS6.36, CS7.36, CS8.36; also elsewhere on the board
D2: CS1.34, CS2.34, CS3.34, CS4.34, CS5.34, CS6.34, CS7.34, CS8.34; also elsewhere on the board
D3: CS1.32, CS2.32, CS3.32, CS4.32, CS5.32, CS6.32, CS7.32, CS8.32; also elsewhere on the board
D4: CS1.30, CS2.30, CS3.30, CS4.30, CS5.30, CS6.30, CS7.30, CS8.30; also elsewhere on the board
D5: CS1.28, CS2.28, CS3.28, CS4.28, CS5.28, CS6.28, CS7.28, CS8.28; also elsewhere on the board
D6: CS1.26, CS2.26, CS3.26, CS4.26, CS5.26, CS6.26, CS7.26, CS8.26; also elsewhere on the board
D7: CS1.24, CS2.24, CS3.24, CS4.24, CS5.24, CS6.24, CS7.24, CS8.24; also elsewhere on the board
GND: C1.2, C3.-, CS1.8, CS1.10, CS2.8, CS2.10, CS3.8, CS3.10, CS4.8, CS4.10, CS5.8, CS5.10, CS6.8, CS6.10, CS7.8, CS7.10, CS8.8, CS8.10, IC4.10-I, IC4.11-I, IC4.13-I, IC4.GND, R2.1, X1.2; also elsewhere on the board
IRQB: CS1.14, CS2.14, CS3.14, CS4.14, CS5.14, CS6.14, CS7.14, CS8.14; also elsewhere on the board
unnamed: JP9.1, R2.2
NMIB: CS1.16, CS2.16, CS3.16, CS4.16, CS5.16, CS6.16, CS7.16, CS8.16; also elsewhere on the board
OSC: CS1.6, CS2.6, CS3.6, CS4.6, CS5.6, CS6.6, CS7.6, CS8.6; also elsewhere on the board
PHI2: CS1.20, CS2.20, CS3.20, CS4.20, CS5.20, CS6.20, CS7.20, CS8.20, IC4.1-I/CLK; also elsewhere on the board
RDY: CS1.12, CS2.12, CS3.12, CS4.12, CS5.12, CS6.12, CS7.12, CS8.12; also elsewhere on the board
RESB: CS1.18, CS2.18, CS3.18, CS4.18, CS5.18, CS6.18, CS7.18, CS8.18, JP9.2, R1.1; also elsewhere on the board
RWB: CS1.22, CS2.22, CS3.22, CS4.22, CS5.22, CS6.22, CS7.22, CS8.22; also elsewhere on the board
VCC: C1.1, C3.+, CS1.2, CS1.4, CS2.2, CS2.4, CS3.2, CS3.4, CS4.2, CS4.4, CS5.2, CS5.4, CS6.2, CS6.4, CS7.2, CS7.4, CS8.2, CS8.4, IC4.VCC, R1.2, X1.1; also elsewhere on the board

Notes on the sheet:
Decode Logic
Card Slot 1
Card Slot 2
Card Slot 3
Card Slot 4
Reset
+5Vin
Rail Caps
Card Slot 5
Card Slot 6
Card Slot 7
Card Slot 8

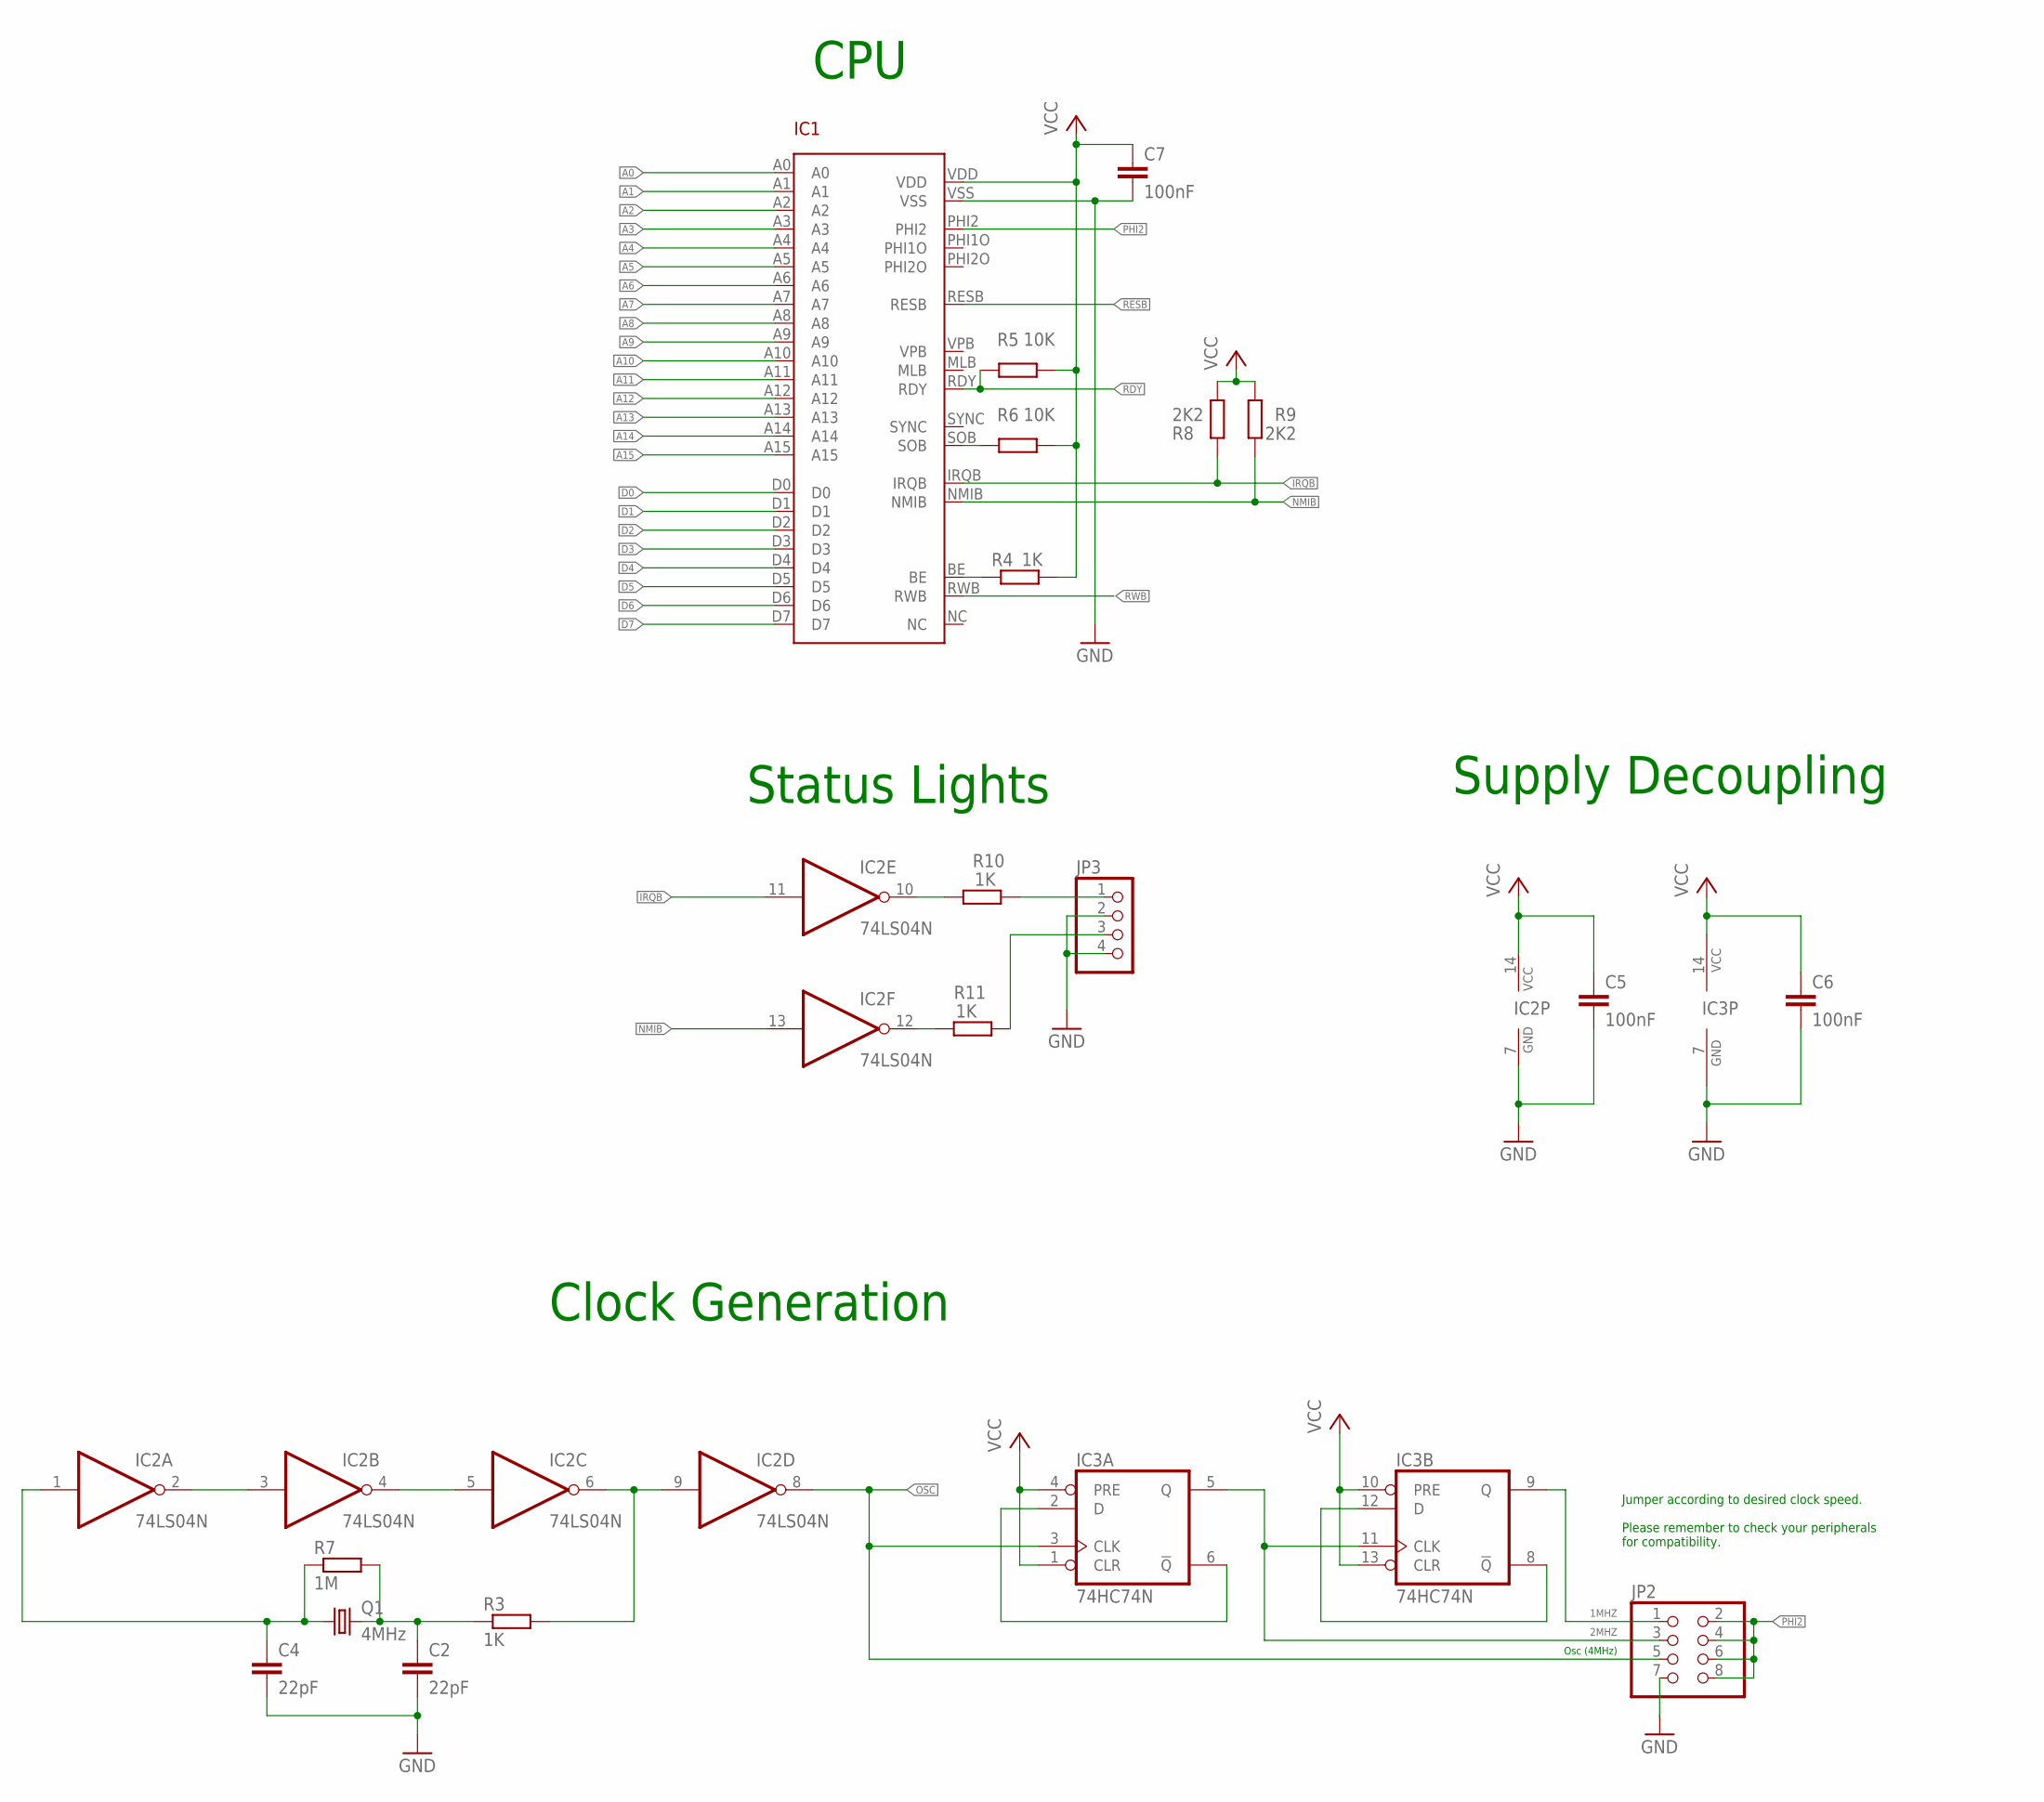
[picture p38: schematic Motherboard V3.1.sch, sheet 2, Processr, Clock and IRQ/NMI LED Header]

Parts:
C2, C4: 22pF; C025-025X050
C5, C6, C7: 100nF; C050-025X075
IC1: W65C02S-DIP; DIP40
IC2: 74LS04N; DIL14
IC3: 74HC74N; DIL14
JP2: PINHD-2X4; 2X04
JP3: PINHD-1X4; 1X04
Q1: 4MHz; HC49/S
R3, R10, R11: 1K; 0207/2V
R4: 1K; 0207/10
R5: 10K; 0207/2V
R6: 10K; 0207/10
R7: 1M; 0207/2V
R8, R9: 2K2; 0207/2V

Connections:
1MHZ: IC3.9 (Q), JP2.1
2MHZ: IC3.5 (Q), IC3.11 (CLK), JP2.3
A0: IC1.A0; also elsewhere on the board
A1: IC1.A1; also elsewhere on the board
A2: IC1.A2; also elsewhere on the board
A3: IC1.A3; also elsewhere on the board
A4: IC1.A4; also elsewhere on the board
A5: IC1.A5; also elsewhere on the board
A6: IC1.A6; also elsewhere on the board
A7: IC1.A7; also elsewhere on the board
A8: IC1.A8; also elsewhere on the board
A9: IC1.A9; also elsewhere on the board
A10: IC1.A10; also elsewhere on the board
A11: IC1.A11; also elsewhere on the board
A12: IC1.A12; also elsewhere on the board
A13: IC1.A13; also elsewhere on the board
A14: IC1.A14; also elsewhere on the board
A15: IC1.A15; also elsewhere on the board
D0: IC1.D0; also elsewhere on the board
D1: IC1.D1; also elsewhere on the board
D2: IC1.D2; also elsewhere on the board
D3: IC1.D3; also elsewhere on the board
D4: IC1.D4; also elsewhere on the board
D5: IC1.D5; also elsewhere on the board
D6: IC1.D6; also elsewhere on the board
D7: IC1.D7; also elsewhere on the board
GND: C2.2, C4.2, C5.2, C6.2, C7.2, IC1.VSS, IC2.7 (GND), IC3.7 (GND), JP2.7, JP3.2, JP3.4; also elsewhere on the board
IRQB: IC1.IRQB, IC2.11 (I), R8.1; also elsewhere on the board
IRQ_LED: JP3.1, R10.2
IRQ_SIG: IC2.10 (O), R10.1
unnamed: IC2.4 (O), IC2.5 (I)
unnamed: IC2.6 (O), IC2.9 (I), R3.2
unnamed: C2.1, Q1.2, R3.1, R7.2
unnamed: C4.1, IC2.1 (I), Q1.1, R7.1
unnamed: IC3.2 (D), IC3.6 (!Q)
unnamed: IC2.2 (O), IC2.3 (I)
unnamed: IC3.8 (!Q), IC3.12 (D)
unnamed: IC1.BE, R4.1
unnamed: IC1.SOB, R6.1
NMIB: IC1.NMIB, IC2.13 (I), R9.1; also elsewhere on the board
NMI_LED: JP3.3, R11.2
NMI_SIG: IC2.12 (O), R11.1
OSC: IC2.8 (O), IC3.3 (CLK), JP2.5; also elsewhere on the board
PHI2: IC1.PHI2, JP2.2, JP2.4, JP2.6, JP2.8; also elsewhere on the board
RDY: IC1.RDY, R5.1; also elsewhere on the board
RESB: IC1.RESB; also elsewhere on the board
RWB: IC1.RWB; also elsewhere on the board
VCC: C5.1, C6.1, C7.1, IC1.VDD, IC2.14 (VCC), IC3.1 (CLR), IC3.4 (PRE), IC3.10 (PRE), IC3.13 (CLR), IC3.14 (VCC), R4.2, R5.2, R6.2, R8.2, R9.2; also elsewhere on the board

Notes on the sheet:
CPU
Clock Generation
Status Lights
Supply Decoupling
Jumper according to desired clock speed. Please remember to check your peripherals for compatibility.
Osc (4MHz)

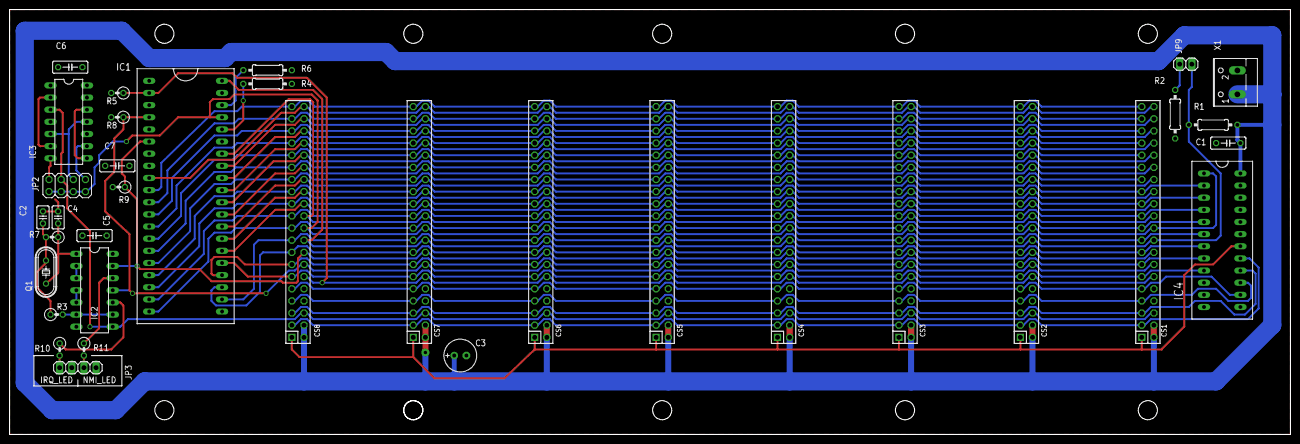
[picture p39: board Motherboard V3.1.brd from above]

Board: 2 copper layers, 268.0 x 88.9 mm, 35 parts (0 on the bottom side), 54 nets.

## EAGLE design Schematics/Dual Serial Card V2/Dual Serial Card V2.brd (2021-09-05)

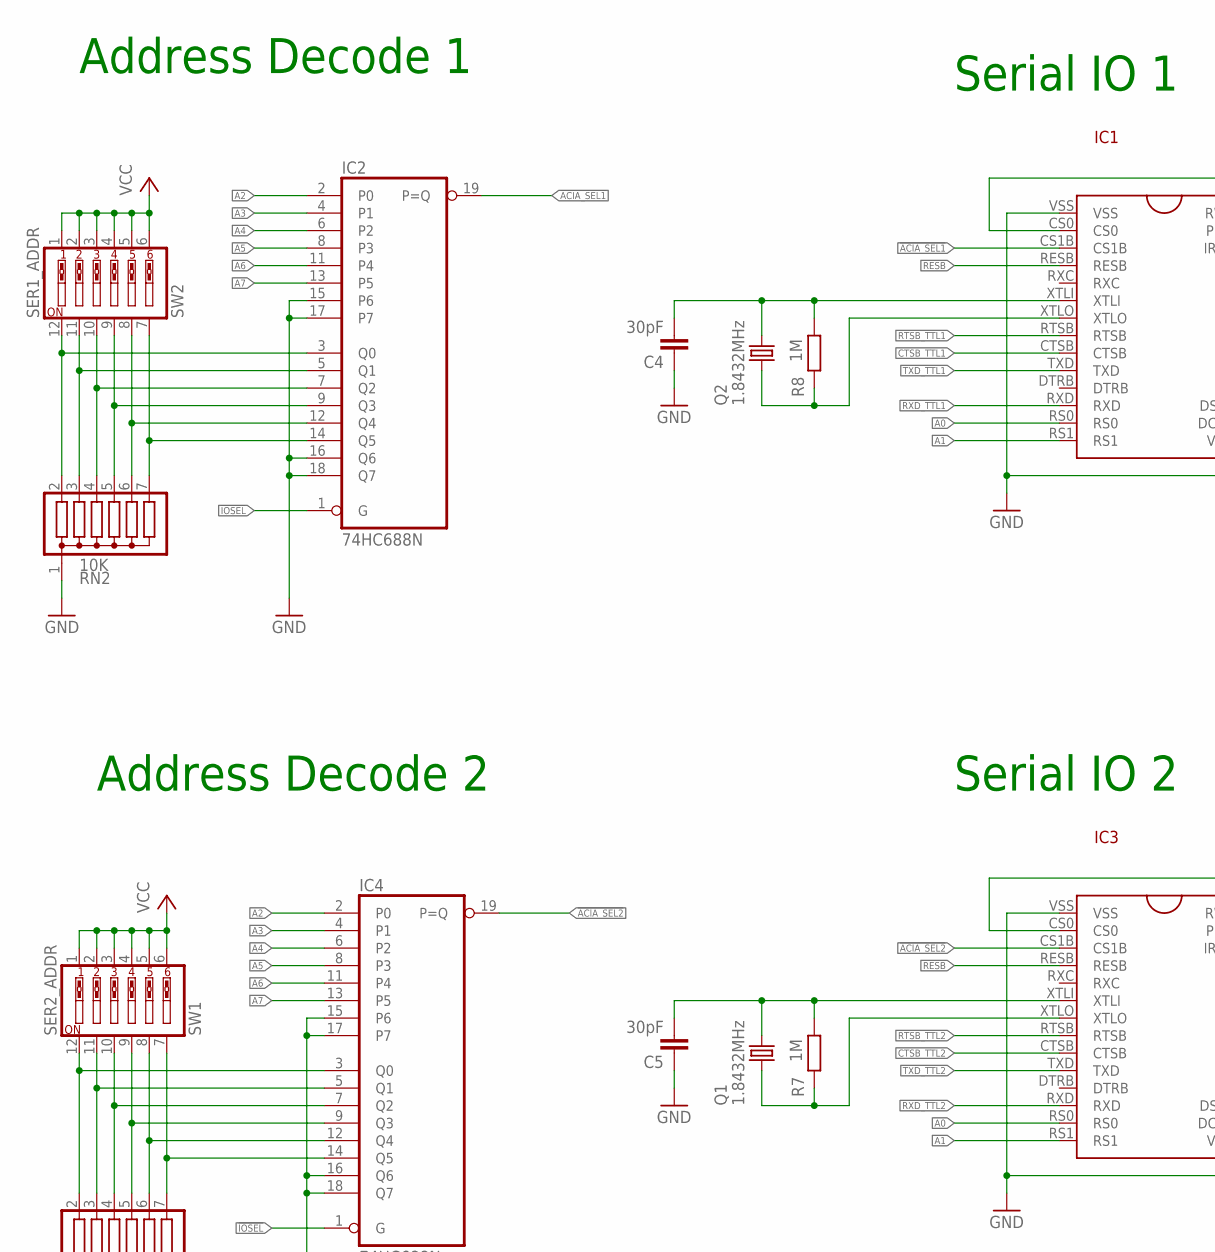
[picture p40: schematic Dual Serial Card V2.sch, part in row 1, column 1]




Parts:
C1, C2, C3, C9, C14: 100nF; C025-025X050
C4, C5: 30pF; C050-025X075
C6: 47uF; E2,5-7
C7, C8, C10, C11, C12, C13: 1uF; E2,5-5
IC1, IC3: W65C51N-DIP
IC2, IC4: 74HC688N; DIL20
IC5: MAX238; DIL24-3
Q1, Q2: 1.8432MHz; HC49/S
R7, R8: 1M; 0207/2V
RN1, RN2: 10K; SIL7
SW1: SER2_ADDR; EDG-06
SW2: SER1_ADDR; EDG-06
SYSBUS: PINHD-2X20/90; 2X20/90
X1: SER1; M09HP
X2: SER2; M09HP

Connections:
!ACIA_SEL1: IC1.CS1B, IC2.19 (P=Q)
!ACIA_SEL2: IC3.CS1B, IC4.19 (P=Q)
!BANK0: SYSBUS.9
!BANK1: SYSBUS.7
!BANK2: SYSBUS.5
!BANK3: SYSBUS.3
!IOSEL: IC2.1 (G), IC4.1 (G), SYSBUS.1
A0: IC1.RS0, IC3.RS0, SYSBUS.40
A1: IC1.RS1, IC3.RS1, SYSBUS.39
A2: IC2.2 (P0), IC4.2 (P0), SYSBUS.37
A3: IC2.4 (P1), IC4.4 (P1), SYSBUS.35
A4: IC2.6 (P2), IC4.6 (P2), SYSBUS.33
A5: IC2.8 (P3), IC4.8 (P3), SYSBUS.31
A6: IC2.11 (P4), IC4.11 (P4), SYSBUS.29
A7: IC2.13 (P5), IC4.13 (P5), SYSBUS.27
A8: SYSBUS.25
A9: SYSBUS.23
A10: SYSBUS.21
A11: SYSBUS.19
A12: SYSBUS.17
A13: SYSBUS.15
A14: SYSBUS.13
A15: SYSBUS.11
CTS1: IC5.7 (R1IN), X1.8
CTS2: IC5.23 (R3IN), X2.8
CTSB_TTL1: IC1.CTSB, IC5.6 (R1OUT)
CTSB_TTL2: IC3.CTSB, IC5.22 (R3OUT)
D0: IC1.D0, IC3.D0, SYSBUS.38
D1: IC1.D1, IC3.D1, SYSBUS.36
D2: IC1.D2, IC3.D2, SYSBUS.34
D3: IC1.D3, IC3.D3, SYSBUS.32
D4: IC1.D4, IC3.D4, SYSBUS.30
D5: IC1.D5, IC3.D5, SYSBUS.28
D6: IC1.D6, IC3.D6, SYSBUS.26
D7: IC1.D7, IC3.D7, SYSBUS.24
GND: C1.2, C2.2, C3.2, C4.1, C5.1, C6.-, C7.-, C8.-, C9.2, C12.+, C14.2, IC1.DCDB, IC1.DSRB, IC1.VSS, IC2.10 (GND), IC2.15 (P6), IC2.16 (Q6), IC2.17 (P7), IC2.18 (Q7), IC3.DCDB, IC3.DSRB, IC3.VSS, IC4.10 (GND), IC4.15 (P6), IC4.16 (Q6), IC4.17 (P7), IC4.18 (Q7), IC5.8 (GND), RN1.1, RN2.1, SYSBUS.8, SYSBUS.10, X1.5, X2.5
IRQB: IC1.IRQB, IC3.IRQB, SYSBUS.14
unnamed: C5.2, IC3.XTLI, Q1.2, R7.2
unnamed: IC3.XTLO, Q1.1, R7.1
unnamed: C4.2, IC1.XTLI, Q2.2, R8.2
unnamed: IC1.XTLO, Q2.1, R8.1
unnamed: IC4.14 (Q5), RN1.7, SW1.7
unnamed: C10.-, IC5.12 (C1-)
unnamed: C10.+, IC5.10 (C1+)
unnamed: C11.-, IC5.14 (C2-)
unnamed: C11.+, IC5.13 (C2+)
unnamed: C13.+, IC5.11 (V+)
unnamed: C12.-, IC5.15 (V-)
unnamed: IC2.14 (Q5), RN2.7, SW2.7
NMIB: SYSBUS.16
OSC: SYSBUS.6
P1: IC4.12 (Q4), RN1.6, SW1.8
P2: IC4.9 (Q3), RN1.5, SW1.9
P3: IC2.12 (Q4), RN2.6, SW2.8
P4: IC2.9 (Q3), RN2.5, SW2.9
P5: IC2.7 (Q2), RN2.4, SW2.10
P6: IC2.5 (Q1), RN2.3, SW2.11
P8: IC4.7 (Q2), RN1.4, SW1.10
P9: IC4.5 (Q1), RN1.3, SW1.11
PHI2: IC1.PHI2, IC3.PHI2, SYSBUS.20
RDY: SYSBUS.12
RESB: IC1.RESB, IC3.RESB, SYSBUS.18
RTS1: IC5.2 (T1OUT), X1.7
RTS2: IC5.24 (T3OUT), X2.7
RTSB_TTL1: IC1.RTSB, IC5.5 (T1IN)
RTSB_TTL2: IC3.RTSB, IC5.19 (T3IN)
RWB: IC1.RWB, IC3.RWB, SYSBUS.22
RXD1: IC5.3 (R2IN), X1.2
RXD2: IC5.16 (R4IN), X2.2
RXD_TTL1: IC1.RXD, IC5.4 (R2OUT)
RXD_TTL2: IC3.RXD, IC5.17 (R4OUT)
S1_A2: IC2.3 (Q0), RN2.2, SW2.12
S2_A2: IC4.3 (Q0), RN1.2, SW1.12
TXD1: IC5.1 (T2OUT), X1.3
TXD2: IC5.20 (T4OUT), X2.3
TXD_TTL1: IC1.TXD, IC5.18 (T2IN)
TXD_TTL2: IC3.TXD, IC5.21 (T4IN)
VCC: C1.1, C2.1, C3.1, C6.+, C7.+, C8.+, C9.1, C13.-, C14.1, IC1.CS0, IC1.VDD, IC2.20 (VCC), IC3.CS0, IC3.VDD, IC4.20 (VCC), IC5.9 (VCC), SW1.1, SW1.2, SW1.3, SW1.4, SW1.5, SW1.6, SW2.1, SW2.2, SW2.3, SW2.4, SW2.5, SW2.6, SYSBUS.2, SYSBUS.4

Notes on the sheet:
Card Bus
Decoupling and Reservoir Caps
Address Decode 1
Serial IO 2
Serial IO Connector 2
Serial IO 1
Signal Level Shifting.
Serial IO Connector 1
Address Decode 2


Board: 2 copper layers, 121.6 x 88.9 mm, 30 parts (0 on the bottom side), 63 nets.

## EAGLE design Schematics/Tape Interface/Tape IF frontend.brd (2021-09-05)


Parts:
C1, C2: 100nF; C050-025X075
EAR_IN: STEREOJACK; STX3100
IC1: LM358N; DIL08
JP1, JP2, JP3: PINHD-1X2; 1X02
MIC_OUT: STEREOJACK; STX3100
R1, R2, R3, R4: 10k; 0207/10
R6, R7: 10k; RTRIM64W

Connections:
+5V: IC1.8 (V+), JP3.1
BUFFERED_OUT: C2.2, MIC_OUT.5
EAR_SCHMITTED: IC1.1 (OUT), JP1.1, R6.2 (S), R6.3 (E)
GND: IC1.4 (V-), JP1.2, JP2.2, JP3.2, MIC_OUT.1, R7.1 (A)
unnamed: C1.2, EAR_IN.5
unnamed: C1.1, IC1.2 (-IN), R3.1, R4.2
unnamed: IC1.3 (+IN), R1.1, R2.2, R6.1 (A)
unnamed: EAR_IN.1, R2.1, R4.1
unnamed: R1.2, R3.2
unnamed: C2.1, IC1.6 (-IN), IC1.7 (OUT)
unnamed: IC1.5 (+IN), R7.2 (S)
UNBUFFERED_OUT: JP2.1, R7.3 (E)

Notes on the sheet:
Power Connector
Data In
Data Out


Board: 2 copper layers, 50.0 x 50.0 mm, 14 parts (0 on the bottom side), 12 nets.

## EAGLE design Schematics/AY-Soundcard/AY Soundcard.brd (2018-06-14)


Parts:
C1, C2, C3: 100nF; C050-025X075
C4, C7: CPOL-EUE2-5; E2-5
C5: 47uF 10V; E5-6
C6: 47uF; E2,5-7
IC1: 74HC688N; DIL20
JP1: PINHD-2X20/90; 2X20/90
JP2: PINHD-2X7; 2X07
R1, R2, R3, R4, R5, R6, R7: 10K; 0207/2V
R8, R9, R10, R11: 1K; 0207/2V
R12: 470R; 0207/2V
R13, R14: 470R; 0207/10
U1: AY-3-8912-DIP; DIP
U2: GAL22V10D-DIP; DIP24
X1: STEREOJACK; STX3100

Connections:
!BANK0: JP1.9
!BANK1: JP1.7
!BANK2: JP1.5
!BANK3: JP1.3
!IOSEL: JP1.1, U2.5-I
!SEL: IC1.19 (P=Q), U2.4-I
A0: JP1.40, U2.2-I
A1: IC1.4 (P1), JP1.39
A2: IC1.6 (P2), JP1.37
A3: IC1.8 (P3), JP1.35
A4: IC1.11 (P4), JP1.33
A5: IC1.13 (P5), JP1.31
A6: IC1.15 (P6), JP1.29
A7: IC1.17 (P7), JP1.27
A8: JP1.25
A9: JP1.23
A10: JP1.21
A11: JP1.19
A12: JP1.17
A13: JP1.15
A14: JP1.13
A15: JP1.11
BC1: U1.BC1, U2.14-I/O/Q
BDIR: U1.BDIR, U2.15-I/O/Q
CH_A: R8.1, R12.2, U1.CH_A
CH_B: R9.1, R13.2, U1.CH_B
CH_C: R10.1, R11.1, R14.2, U1.CH_C
D0: JP1.38, U1.DA0
D1: JP1.36, U1.DA1
D2: JP1.34, U1.DA2
D3: JP1.32, U1.DA3
D4: JP1.30, U1.DA4
D5: JP1.28, U1.DA5
D6: JP1.26, U1.DA6
D7: JP1.24, U1.DA7
GND: C1.2, C2.2, C3.2, C5.-, C6.-, IC1.1 (G), IC1.2 (P0), IC1.3 (Q0), IC1.10 (GND), JP1.8, JP1.10, R1.1, R2.1, R3.1, R4.1, R5.1, R6.1, R7.1, R12.1, R13.1, R14.1, U1.VSS, U2.GND, X1.1
IRQB: JP1.14
unnamed: C4.+, R8.2, R10.2
unnamed: C7.+, R9.2, R11.2
unnamed: C4.-, X1.2
unnamed: C7.-, X1.5
unnamed: IC1.5 (Q1), JP2.2, R1.2
unnamed: IC1.7 (Q2), JP2.4, R2.2
unnamed: IC1.9 (Q3), JP2.6, R3.2
unnamed: IC1.12 (Q4), JP2.8, R4.2
unnamed: IC1.14 (Q5), JP2.10, R5.2
unnamed: IC1.16 (Q6), JP2.12, R6.2
unnamed: IC1.18 (Q7), JP2.14, R7.2
NMIB: JP1.16
OSC: JP1.6
PHI2: JP1.20, U1.CLOCK, U2.1-I/CLK
RDY: JP1.12
RESB: JP1.18, U1.!RESET
RWB: JP1.22, U2.3-I
VCC: C1.1, C2.1, C3.1, C5.+, C6.+, IC1.20 (VCC), JP1.2, JP1.4, JP2.1, JP2.3, JP2.5, JP2.7, JP2.9, JP2.11, JP2.13, U1.BC2, U1.VCC, U2.VCC

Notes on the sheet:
Card Bus
Decoupling and Reservoir Caps
Tantalum Only


Board: 2 copper layers, 121.9 x 88.9 mm, 27 parts (0 on the bottom side), 39 nets.

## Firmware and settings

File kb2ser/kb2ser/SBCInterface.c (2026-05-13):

//
// KEYBOARD, SERIAL AND DISPLAY INTERFACE
// (c) GRANT SEARLE 2007-17
//
// http://searle.hostei.com/grant/MonitorKeyboard/index.html
//
// Use a search engine (Google etc) to search for "Grant Searle" if the web page is no longer active
// in case it has moved.
//
// Last update: 1st Jan 2017 - Code method move around (identical code) to remove implicit definition warnings in AtmelStudio 7

#define KBBUFSIZE 50
#define SERBUFSIZE 800
#define F_CPU 11059200ul
#define USART_BAUD 9600ul
#define USART_UBBR_VALUE ((F_CPU/(USART_BAUD<<4))-1)

// Two-wire interface definitions
#define START 0x08
#define MT_DATA_ACK 0x28
#define MT_SLA_ACK 0x18
#define SLA_W 0x02 // Addr = 1, read/write = low

#include <avr/interrupt.h>
#include <avr/pgmspace.h>
#include <avr/io.h>
#include <util/delay.h>

unsigned char kbBuffer[KBBUFSIZE];
unsigned int volatile kbInPointer;
unsigned int volatile kbOutPointer;
unsigned char kbClockCount;
unsigned char kbTemp;
unsigned char kbShift;
unsigned char kbCrtl;
unsigned char kbAlt;
unsigned char kbCaps;
unsigned char kbNumLock;
unsigned char kbScrollLock;
unsigned char kbValue;
unsigned char prevKbCode;

unsigned char kbAckReceived;
unsigned char kbWriteActive;
unsigned char kbWriteDataVal;

unsigned char kbWriteCount;
unsigned char kbBuffer1;
unsigned char kbBuffer2;
unsigned char kbBuffer3;
unsigned char kbWrPar;

unsigned char enableAnsiConversion;
unsigned char serBuffer[SERBUFSIZE];
int volatile serInPointer;
int volatile serOutPointer;
unsigned char twiStarted;
//Keycode values up to 131 (max returned from a 102 key keyboard)
//These values are for a UK keyboard mapping
const unsigned char kbNormal[132] PROGMEM = {
	0 , 137 , 0 , 133 , 131 , 129 , 130 , 140 , 0 , 138 , 136 , 134 , 132 , 07 , 06 , 0 ,
	0 , 0 , 0 , 0 , 0 , 113 , 49 , 0 , 0 , 0 , 122 , 115 , 97 , 119 , 50 , 0 ,
	0 , 99 , 120 , 100 , 101 , 52 , 51 , 59 , 0 , 32 , 118 , 102 , 116 , 114 , 53 , 0 ,
	0 , 110 , 98 , 104 , 103 , 121 , 54 , 7 , 8 , 44 , 109 , 106 , 117 , 55 , 56 , 0 ,
	0 , 44 , 107 , 105 , 111 , 48 , 57 , 0 , 0 , 46 , 47 , 108 , 59 , 112 , 45 , 0 ,
	0 , 0 , 39 , 0 , 91 , 61 , 0 , 0 , 0 , 0 , 13 , 93 , 0 , 35 , 0 , 0 ,
	0 , 92 , 0 , 0 , 0 , 0 , 8 , 0 , 0 , 49 , 0 , 52 , 55 , 0 , 0 , 0 ,
   48 , 46 , 50 , 53 , 54 , 56 , 03 , 0 , 139 , 43 , 51 , 45 , 42 , 57 , 0 , 0 ,
    0 , 0 , 0 , 135};


const unsigned char kbShifted[132] PROGMEM = {
	0 , 149 , 0 , 145 , 143 , 141 , 142 , 152 , 0 , 150 , 148 , 146 , 144 , 0 , 172 , 0 ,
	0 , 0 , 0 , 0 , 0 , 81 , 33 , 0 , 0 , 0 , 90 , 83 , 65 , 87 , 34 , 0 ,
	0 , 67 , 88 , 68 , 69 , 36 , 156 , 58 , 0 , 32 , 86 , 70 , 84 , 82 , 37 , 0 ,
	0 , 78 , 66 , 72 , 71 , 89 , 94 , 0 , 0 , 76 , 77 , 74 , 85 , 38 , 42 , 0 ,
	0 , 60 , 75 , 73 , 79 , 41 , 40 , 0 , 0 , 62 , 63 , 76 , 58 , 80 , 95 , 0 ,
	0 , 0 , 64 , 0 , 123 , 43 , 0 , 0 , 0 , 0 , 13 , 125 , 0 , 126 , 0 , 0 ,
	0 , 124 , 0 , 0 , 0 , 8 , 0 , 0 , 49 , 0 , 52 , 55 , 0 , 0 , 0 , 0 ,
   48 , 46 , 50 , 53 , 54 , 56 , 03 , 0 , 151 , 43 , 51 , 45 , 42 , 57 , 0 , 0 ,
    0 , 0 , 0 , 135};

void setRTS()
{
	unsigned int temp1;
	unsigned int temp2;
	unsigned int bufferUsed;

	temp1 = serInPointer;
	temp2 = serOutPointer;

	if(temp2 <= temp1)
	{
		bufferUsed = temp1 - temp2;
	}
	else
	{
		bufferUsed = SERBUFSIZE + temp1 - temp2;
	}
	if (bufferUsed < 32)
	{
		PORTC = PORTC & 0b11110111;
	}
	if (bufferUsed > SERBUFSIZE-32)
	{
		PORTC = PORTC | 0b00001000;
	}
}

void setKeyboardToReceiveMode()
{
	TCNT2=0;
	// Bring clock low
	_delay_us(500);
	DDRC = DDRC | 0b00000010;
	PORTC=PORTC & 0b11111101;
	_delay_us(500);
	// Bring data low
	DDRC = DDRC | 0b00000100;
	PORTC=PORTC & 0b11111011;
	_delay_us(500);
	// Release clock
	DDRC = DDRC & 0b11111101;
	PORTC=PORTC & 0b11111101;
	TCNT2=0;
	kbWrPar=1;
	kbClockCount=0;
	kbWriteActive=1;
}

void setKeyboardToSendMode()
{
	DDRC = DDRC & 0b11111001;
}

void sendBitToKB(unsigned char val)
{
	if (val==1)
	{
		PORTC=PORTC | 0b00000100;
	}
	else
	{
		PORTC=PORTC & 0b11111011;
	}
	
}

void error(unsigned char location, unsigned char err)
{
	// Disable errors
	if (1)
	{
		return;
	}
	
	// SIMPLE DISPLAY OF ERROR STATUS AND LOCATION USING 1 PIN
	//
	// LED connected in series with a resistor to PB3 to show error conditions
	// Watching and counting the flashes allows the error code and location to be read as follows:
	//
	// Start of sequence - one very long flash (2 seconds)
	// 1 second delay
	// Set of very short flashes for location (ie. place in code where error occurred)
	// 1 second delay
	// Set of long flashes for high 4 bits of err ("1x"=1 flash ... "Fx"=15 flashes, "0x" = 16 flashes)
	// 1 second delay
	// Set of short flashes for low 4 bits of err ("x1"=1 flash ... "xF"=15 flashes, "x0" = 16 flashes)
	// 2 second delay
	// Repeat
	
	// SYSTEM HALT ONCE IN THIS ROUTINE
	cli();
	
	while (1)
	{
		PORTB|=0b00001000;
		for (int i=0;i<2000;i++) _delay_ms(1);
		PORTB&=0b11110111;
		for (int i=0;i<1000;i++) _delay_ms(1);

		for (int c=0;c<location;c++)
		{
			PORTB|=0b00001000;
			for (int i=0;i<50;i++) _delay_ms(1);
			PORTB&=0b11110111;
			for (int i=0;i<200;i++) _delay_ms(1);
		}
		for (int i=0;i<1000;i++) _delay_ms(1);

		unsigned char temp=err>>4;
		if (temp==0) temp=16;
		for (unsigned char c=0;c<temp;c++)
		{
			PORTB|=0b00001000;
			for (int i=0;i<800;i++) _delay_ms(1);
			PORTB&=0b11110111;
			for (int i=0;i<200;i++) _delay_ms(1);
		}
		for (int i=0;i<1000;i++) _delay_ms(1);

		temp=err & 0x0F;
		if (temp==0) temp=16;
		for (unsigned char c=0;c<temp;c++)
		{
			PORTB|=0b00001000;
			for (int i=0;i<200;i++) _delay_ms(1);
			PORTB&=0b11110111;
			for (int i=0;i<800;i++) _delay_ms(1);
		}
		for (int i=0;i<2000;i++) _delay_ms(1);
	}
}

// This is activated on the keyboard clock signal for both low and high transitions
ISR(PCINT1_vect)
{
	unsigned int kbTempptr;

	//Reset the 20ms timeout
	TCNT2=0;

	if (kbWriteActive==1)
	{
		// When writing to the keyboard, set data on low to high transitions
		// so if the clock is low, don't do any more processing
		if ((PINC & 2)==0)
		{
			return;
		}
		kbClockCount++;
		if (kbClockCount==10)
		{
			setKeyboardToSendMode();
		}
		if (kbClockCount==11)
		{
			kbWriteActive=0;
			kbClockCount=0;
			kbTemp=0;
		}
		else if (kbClockCount==9)
		{
			//sendBitToKB(1);
			if (kbWrPar==1)
			{
				sendBitToKB(1);
			}
			else
			{
				sendBitToKB(0);
			}
		}
		else
		{
			if ((kbWriteDataVal & 1)==1)
			{
				sendBitToKB(1);
				if (kbWrPar==1)
				{
					kbWrPar=0;
				}
				else
				{
					kbWrPar=1;
				}
			}
			else
			{
				sendBitToKB(0);
			}
			kbWriteDataVal=kbWriteDataVal>>1;			
		}
		return;
	}
	// When reading the keyboard, only use high-to-low transitions
	// so if the clock is high, don't do any more processing
	if ((PINC & 2)>0)
	{
		return;
	}
	
	kbClockCount++;
	if (kbClockCount==1 || kbClockCount==10)
	{
		// ignore
	}
	else if (kbClockCount==11)
	{
		kbClockCount=0;
	}
	else
	{
		// Shift value right and set high bit if needed
		kbTemp =kbTemp/2;
		if ((PINC & 4)>0)
		{
			kbTemp=kbTemp+128;
		}

		// When complete, store in the key buffer
		if (kbClockCount==9)
		{
			kbTempptr = kbInPointer;
			kbTempptr++;
			if (kbTempptr >(KBBUFSIZE-1))
			{
				kbTempptr = 0;
			}

			if (kbTempptr == kbOutPointer)
			{
				// ignore
			}
			else
			{
				kbBuffer[kbTempptr] = kbTemp;
				kbInPointer = kbTempptr;
			}
			kbTemp = 0;
		}
	}
}

void updateKeyboardLEDs()
{
	unsigned char ledVals;
	ledVals=0;
	if (kbScrollLock==1)
	{
		ledVals+=1;
	}
	if (kbNumLock==1)
	{
		ledVals+=2;
	}
	if (kbCaps==1)
	{
		ledVals+=4;
	}
	kbBuffer2=0xED;
	kbBuffer1=ledVals;
	kbWriteCount=2;
	kbAckReceived=1;
}

ISR (USART_RX_vect)
{
	unsigned char  tempSts;
	unsigned char 	inByte;
	int tempPtr;
	tempSts = UCSR0A & 0x1C;
	inByte = UDR0;
	if (tempSts > 0)
	{
		inByte = '?';
	}

	tempPtr = serInPointer+1;
	if (tempPtr > SERBUFSIZE-1)
	{
		tempPtr = 0;
	}
	if (tempPtr == serOutPointer)
	{
		//ignore because buffer is full
	}
	else
	{
		serBuffer[tempPtr] = inByte;
		serInPointer = tempPtr;
	}

	setRTS();
}

void initUSART(void)
{
	// Set baud rate
	UBRR0H = (unsigned char)(USART_UBBR_VALUE>>8);
	UBRR0L = (unsigned char)USART_UBBR_VALUE;

	// Set frame format to 8 data bits, no parity, 1 stop bit
	UCSR0C = (0<<USBS0)|(1<<UCSZ01)|(1<<UCSZ00);

	// Enable rec interrupt, receiver and transmitter
	UCSR0B = (1<<RXCIE0)|(1<<RXEN0)|(1<<TXEN0);
}

void sendUSART(unsigned char c)
{
	// Wait if a byte is being transmitted
	while((UCSR0A&(1<<UDRE0)) == 0);

	// Transmit data
	UDR0 = c;
}

	
void send8BitToDisplay(unsigned char c)
{
	unsigned char temp;
	unsigned char dataAvail;
	unsigned char ackIn;

	// Check to see if the acknowledge pin is the same as the data available pin
	// If not then wait until it is (the display processor will change it to be the same when ready)
	dataAvail=PORTC & 0b00100000;
	ackIn=(PINC & 0b00010000) << 1;

	while (dataAvail!=ackIn)
	{
		dataAvail=PORTC & 0b00100000;
		ackIn=(PINC & 0b00010000) << 1;
	}
	// Move the data into the appropriate output pins
	temp = PORTB & 0b11011110;
    if ((c & 1)>0) { temp=temp+1; }
    if ((c & 16)>0) { temp=temp+32; }
	PORTB = temp;
	temp=0;		
	if ((c & 2)>0) { temp=temp+128; }
	if ((c & 4)>0) { temp=temp+64; }
	if ((c & 8)>0) { temp=temp+32; }
	if ((c & 32)>0) { temp=temp+16; }
	if ((c & 64)>0) { temp=temp+8; }
	if ((c & 128)>0) { temp=temp+4; }
	PORTD = temp;
	
	// Flip the data avail bit to tell the display that there is a character/command ready for display
	PORTC = PORTC ^ 0b00100000;
}

void send2x4BitToDisplay(unsigned char c)
{
	unsigned char temp;
	unsigned char ackIn;

	PORTC = PORTC & 0b11011111; // Should already be low, set just in case

	// Check to see if the acknowledge pin is low
	// If not then wait until it is (the display processor will change to low when ready)
	ackIn=PINC & 0b00010000;
	while (ackIn!=0)
	{
		ackIn=PINC & 0b00010000;
	}
	// Move the data into the appropriate output pins
	temp = PORTB & 0b11111110;
    if ((c & 16)>0) { temp=temp+1; }
	PORTB = temp;
	temp=0;		
	if ((c & 32)>0) { temp=temp+128; }
	if ((c & 64)>0) { temp=temp+64; }
	if ((c & 128)>0) { temp=temp+32; }
	PORTD = temp;
	
	// Flip the data avail bit to tell the display that high 4 bits are ready for display
	PORTC = PORTC | 0b00100000;

	// Check to see if the acknowledge pin is high
	// If not then wait until it is (the display processor will change to high when ready)
	ackIn=PINC & 0b00010000;
	while (ackIn==0)
	{
		ackIn=PINC & 0b00010000;
	}
	// Move the data into the appropriate output pins
	temp = PORTB & 0b11111110;
	if ((c & 1)>0) { temp=temp+1; }
	PORTB = temp;
	temp=0;
	if ((c & 2)>0) { temp=temp+128; }
	if ((c & 4)>0) { temp=temp+64; }
	if ((c & 8)>0) { temp=temp+32; }
	PORTD = temp;
	
	// Flip the data avail bit to tell the display that low 4 bits are ready for display
	PORTC = PORTC & 0b11011111;
}

void startTWI()
{
	TWCR = (1<<TWINT)|(1<<TWSTA)|(1<<TWEN); // Send start
	while ((TWCR & (1<<TWINT))==0) ; // Wait
	unsigned char retCode=TWSR & 0xF8;
	if (retCode!=START) error(1,retCode); // ERROR

	TWDR = SLA_W; // Load SLA_W (address of display and low-write bit) into TWDR
	TWCR = (1<<TWINT) | (1<<TWEN); // Clear TWINT bit in TWCR to start transmission of address
	while ((TWCR & (1<<TWINT))==0) ; // Wait
	retCode=TWSR & 0xF8;
	if (retCode != MT_SLA_ACK) error(2,retCode); // ERROR
	twiStarted=1;
}

void sendTWItoDisplay(unsigned char c)
{
	unsigned char retCode;
    // If first char then start TWI data stream
	if (twiStarted==0)
	{
		startTWI();
	}

	TWDR = c;
	TWCR = (1<<TWINT) | (1<<TWEN); // Clear TWINT bit in TWCR to start transmission of data
	while ((TWCR & (1<<TWINT))==0); // Wait
	retCode=TWSR & 0xF8;
	if (retCode != MT_DATA_ACK)
	{
		// If error, try to restart TWI and resume
		startTWI();
		TWDR = c;
		TWCR = (1<<TWINT) | (1<<TWEN); // Clear TWINT bit in TWCR to start transmission of data
		while ((TWCR & (1<<TWINT))==0); // Wait
		retCode=TWSR & 0xF8;
		if (retCode != MT_DATA_ACK)
		{
			error(3,retCode); // ERROR
		}
	} 

//	TWCR = (1<<TWINT)|(1<<TWEN)|(1<<TWSTO); // Send stop - NOT USED BECAUSE DATA STREAM REMAINS OPEN
}

void sendToDisplay(unsigned char c)
{
	// DUNC NOTE:- Removed for my application.  I don't want my bus hanging with nowhere to go.
	
	// Check PB1 and PB2 to see if a Two-wire, 4 bit or 8 bit interface to the monitor is being used
	//unsigned char fourBit = PINB & 0b00000010; //PB1
	//unsigned char twi = PINB & 0b00000100; //PB2
	//if (fourBit==0)
	//{
		//send2x4BitToDisplay(c);
	//}
	//else if (twi==0)
	//{
		//sendTWItoDisplay(c);
	//}
	//else
	//{
		//send8BitToDisplay(c);
	//}
}

unsigned char getInChar()
{
	unsigned char retVal=0;
	unsigned int tempPointer;
	while (serInPointer==serOutPointer)
	{
		asm volatile ("nop");
	}
	cli();
	tempPointer=serOutPointer+1;
	if (tempPointer >(SERBUFSIZE-1))
	{
		tempPointer = 0;
	}
	retVal=serBuffer[tempPointer];
	serOutPointer=tempPointer;
	setRTS();
	sei();

	return retVal;
}


unsigned char isInCharAvailable()
{
	if (serInPointer==serOutPointer)
	{
		return 0;
	}
	else
	{
		return 1;
	}
}

unsigned char getKbCode()
{
	unsigned char retVal=0;
	unsigned int tempPointer;
	if (kbInPointer==kbOutPointer)
	{
		return 0;
	}
	cli();
	tempPointer=kbOutPointer+1;
	if (tempPointer >(KBBUFSIZE-1))
	{
		tempPointer = 0;
	}
	retVal=kbBuffer[tempPointer];
	kbOutPointer=tempPointer;
	sei();
	return retVal;
}

void processATKeyboard()
{
	unsigned char  kbCode=0;
	unsigned char keyValue=0;
	kbCode = getKbCode();
	if (kbCode>0)
	{
		if (kbCode==0xFA)
		{
			kbAckReceived = 1;
			prevKbCode=kbCode;
			return;
		}
		//Ignore E0 prefixes if part of the key up as they are not significant
		//prev code will remain as F0 to ensure the following is processed properly
		if (prevKbCode==0xF0 && kbCode==0xE0)
		{
			return;	
		}				
		if (prevKbCode==0xF0)
		{
			prevKbCode=kbCode;
			if (kbCode == 0x12 || kbCode ==0x59)
			{
				kbShift = 0;
			}
			if (kbCode == 0x14)
			{
				kbCrtl = 0;
			}
			if (kbCode == 0x11)
			{
				kbAlt = 0;
			}
			return;
		}
		if (prevKbCode==0xE0 || kbNumLock==0)
		{
			prevKbCode=kbCode;
			// Cursor keys - no ascii equiv, so sending "Wordstar" equivalents - CTRL E,S,D,X
			if (kbCode == 0x75) //up
			{
				sendUSART(5);
				return;
			}
			if (kbCode == 0x72) //down
			{
				sendUSART(24);
				return;
			}
			if (kbCode == 0x6B) //left
			{
				sendUSART(16);
				return;
			}
			if (kbCode == 0x74) //right
			{
				sendUSART(4);
				return;
			}
			if (kbCode == 0x70) //ins
			{
				sendUSART(1);
				return;
			}
			if (kbCode == 0x71) //del
			{
				sendUSART(1);
				return;
			}
			if (kbCode == 0x6C) //home
			{
				sendUSART(1);
				return;
			}
			if (kbCode == 0x69) //end
			{
				sendUSART(1);
				return;
			}
			if (kbCode == 0x7D) //page up
			{
				sendUSART(1);
				return;
			}
			if (kbCode == 0x7A) //page down
			{
				sendUSART(1);
				return;
			}
		}

		if (kbCode == 0x12 || kbCode ==0x59)
		{
			kbShift = 1;
		}
		else if (kbCode == 0x14)
		{
			kbCrtl = 1;
		}
		else if (kbCode == 0x11)
		{
			kbAlt = 1;
		}
		else if (kbCode == 0x58)
		{
			if (kbCaps==1)
			{
				kbCaps=0;
			}
			else
			{
				kbCaps=1;
			}
			updateKeyboardLEDs();
		}
		else if (kbCode == 0x77)
		{
			if (kbNumLock==1)
			{
				kbNumLock=0;
			}
			else
			{
				kbNumLock=1;
			}
			updateKeyboardLEDs();
		}
		else if (kbCode == 0x7E)
		{
			if (kbScrollLock==1)
			{
				kbScrollLock=0;
			}
			else
			{
				kbScrollLock=1;
			}
			updateKeyboardLEDs();
		}

		else if (kbCode<132)
		{
			if (kbShift==0)
			{
				keyValue = pgm_read_byte(&kbNormal[kbCode]);
			}
			else
			{
				keyValue = pgm_read_byte(&kbShifted[kbCode]);
			}

			if (keyValue>0)
			{
				if ((keyValue>='a') && (keyValue<='z') && (kbCaps==1))
				{
					keyValue=keyValue-32;
				}
				else if ((keyValue>='A') && (keyValue<='Z') && (kbCaps==1))
				{
					keyValue=keyValue+32;
				}

				if (kbCrtl==1)
				{
					keyValue=keyValue & 0x1F;
				}

				sendUSART(keyValue);
			}
		}
		prevKbCode=kbCode;
	}
}

//20ms interrupt resets the keyboard values unless clock read within this time
ISR(TIMER2_COMPA_vect)
{

	//Timeout, so reset the keyboard read variables
	kbClockCount=0;
	kbTemp=0;
	
	//Also reset any pending command
	kbWriteCount=0;
	if (kbWriteActive==1)
	{
		setKeyboardToReceiveMode();
		setKeyboardToSendMode();
		kbWriteActive=0;
	}

}

int main(void)
{
	unsigned char serInChar;
	kbInPointer=0;
	kbOutPointer=0;
	kbClockCount=0;
	prevKbCode=0;
	unsigned char escParam1;
	unsigned char escParam2;
	
	enableAnsiConversion=1;

	twiStarted=0;
	
	serInPointer=0;
	serOutPointer=0;

	kbWriteActive=0;
	kbWriteCount=0;
	kbAckReceived=0;
	kbWrPar=0;

	PORTB = 0b00000110; // TWI and 4 bit interface select pin pull-up
	DDRB = 0b00101001;
	PORTD = 0x00;
	PORTC = 0x00; // ACK = low

	DDRD = 0b11111111;
	unsigned char twiPin = PINB & 0b00000100; //PB2=0 if two wire interface selected

	if (twiPin==0) // Two wire interface selected so both TWI pins to be inputs by default
	{
		DDRC = 0b00001000; // Only PC3 is an output (/RTS)
		// Two wire speed initialisation
		// SCL freq = CPU freq / (16+2*TWBR*Prescaler)
		TWSR=0; // Prescaler = 1
		TWBR=7; // Bit rate 7 = 400KHz for 12MHz clk  (=12 for 16MHz clk)
	}
	else
	{
		DDRC = 0b00101000; // PC3 and PC5 are outputs (/RTS and AVAIL)
	}	

	PCICR=1<<PCIE1; // Interrupt on pin change
	PCMSK1=1<<PCINT9; // enable pin PC1 change (KB clock) to interrupt

	kbShift=0;
	kbCrtl=0;
	kbAlt=0;
	kbCaps=1;
	kbNumLock=1;
	kbScrollLock=0;
	
	initUSART();

	TIMSK2 = TIMSK2 | (1<<OCIE2A);  // Enable Interrupt TimerCounter2 Compare Match A (TIMER2_COMPA_vect)
	TCCR2A = 1<<WGM21;  // Mode = CTC
	TCCR2B = (1<<CS22) | (1<<CS21) | (1<<CS20);   // Clock div 1024
	OCR2A = 215;          // Interrupt every 20mS unless value reset

	sei();

	setKeyboardToSendMode();

	// Wait for keyboard to finish power-on self-test before sending commands
	for (unsigned int i = 0; i < 500; i++) _delay_ms(1);

	updateKeyboardLEDs();

	// Loop forever
	while (1==1)
	{
		//Get a character from the serial port
		
		if (isInCharAvailable()==1)
		{
			serInChar=getInChar();
			//If it is an escape character then get the following characters to interpret
			//them as an ANSI escape sequence
			if (serInChar==27 && enableAnsiConversion==1) // && prevInChar!=26) // If the previous char was a "force character (26)" prefix then don't treat 27 as an escape
			{
				escParam1=0;
				escParam2=0;
				serInChar=getInChar();

				if (serInChar=='-')
				{
					enableAnsiConversion=0;  // ESC- will turn off the ANSI interpreter
				}
				if (serInChar=='[')
				{
					serInChar=getInChar();
					// Process a number after the "[" character
					while (serInChar>='0' && serInChar<='9')
					{
						serInChar=serInChar-'0';
						if (escParam1<100)
						{
							escParam1=escParam1*10;
							escParam1=escParam1+serInChar;
						}
 						serInChar=getInChar();
					}
					// If a ";" then process the next number
					if (serInChar==';')
					{
						serInChar=getInChar();
						while (serInChar>='0' && serInChar<='9')
						{
							serInChar=serInChar-'0';
							if (escParam2<100)
							{
								escParam2=escParam2*10;
								escParam2=escParam2+serInChar;
							}
	 						serInChar=getInChar();
						}

					}
					// Esc[line;ColumnH or Esc[line;Columnf moves cursor to that coordinate
					if (serInChar=='H' || serInChar=='f')
					{
						if (escParam1>0)
						{
							escParam1--;
						}
						if (escParam2>0)
						{
							escParam2--;
						}
						sendToDisplay(0x0F);
						sendToDisplay(escParam1);
						sendToDisplay(0x0E);
						sendToDisplay(escParam2);
					}
					//Esc[J=clear from cursor down, Esc[1J=clear from cursor up, Esc[2J=clear complete screen
					else if (serInChar=='J')
					{
						if (escParam1==0)
						{
							sendToDisplay(0x13);
						}
						if (escParam1==1)
						{
							sendToDisplay(0x12);
						}
						if (escParam1==2)
						{
							sendToDisplay(0x0C);
						}

					}
					// Esc[K = erase to end of line, Esc[1K = erase to start of line
					else if (serInChar=='K')
					{
						if (escParam1==0)
						{
							sendToDisplay(0x11);
						}
						if (escParam1==1)
						{
							sendToDisplay(0x10);
						}

					}
					// Esc[L = scroll down
					else if (serInChar=='L')
					{
						sendToDisplay(0x15);
					}
					// Esc[M = scroll up
					else if (serInChar=='M')
					{
						sendToDisplay(0x14);
					}
				} // end of in char = '['
			} // end of in char = 27
			else
			{

	 			sendToDisplay(serInChar);
			}
		}

		processATKeyboard();
		
		if (kbWriteActive==0 && kbWriteCount>0)
		{
			if (kbWriteCount==3)
			{
				kbWriteDataVal=kbBuffer3;
				kbWriteCount--;
				setKeyboardToReceiveMode();
			}				
			else if (kbWriteCount==2 && kbAckReceived==1)
			{
				kbAckReceived=0;
				kbWriteDataVal=kbBuffer2;
				kbWriteCount--;
				setKeyboardToReceiveMode();
			}
			else if (kbWriteCount==1 && kbAckReceived==1)
			{
				kbWriteDataVal=kbBuffer1;
				kbWriteCount--;
				setKeyboardToReceiveMode();
			}
		}
	}

	return 0;
}

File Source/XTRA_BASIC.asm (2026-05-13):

; Extra functions for TowerBASIC, a derivative of EhBASIC.
;

; Plot configuration bits
;

XTRA_CFG_silent_b	= @00000001
XTRA_CFG_capped_b	= @00000010
XTRA_CFG_NoChecks_b	= @00000100

; Variables for use in Extra functions.

XTRA_Start		= $A10
XTRA_Limit		= $A1F

V_XTRA_PlotMode		= XTRA_Start
V_XTRA_Xcoord		= V_XTRA_PlotMode    + 1
V_XTRA_Ycoord		= V_XTRA_Xcoord      + 1
V_XTRA_PlotPattern	= V_XTRA_Ycoord      + 1	; Not yet used. Future feature provision.
V_XTRA_Config		= V_XTRA_PlotPattern + 1

; Variables for the LINE command

V_LINE_x1		= V_XTRA_Config      + 1
V_LINE_y1		= V_LINE_x1          + 1
V_LINE_x2		= V_LINE_y1          + 1
V_LINE_y2		= V_LINE_x2          + 1
V_LINE_dx		= V_LINE_y2          + 1
V_LINE_dy		= V_LINE_dx          + 1
V_LINE_sx		= V_LINE_dy          + 1
V_LINE_sy		= V_LINE_sx          + 1
V_LINE_errL		= V_LINE_sy          + 1
V_LINE_errH		= V_LINE_errL        + 1
V_LINE_PlotMode		= V_LINE_errH        + 1

XTRA_End		= V_LINE_PlotMode


  .IF [ XTRA_End>XTRA_Limit ]
    .ERROR "Memory overrun in ToE_Mon.asm"
  .ENDIF


; Options for default plot mode are as follows:-
;  
;  XTRA_CFG_silent_b
;  XTRA_CFG_capped_b
;  XTRA_CFG_NoChecks_b
;
; Set as required.
;
XTRA_DefaultPlot_C = XTRA_CFG_silent_b


XTRA_NextParam
  JSR LAB_1C01
XTRA_EVNM_F2FX
  JSR LAB_EVNM
  JMP LAB_F2FX


; Function to set the cursor location.

XTRA_LOCATE_F

  JSR XTRA_EVNM_F2FX
  
  LDA #14						; Set our column
  JSR V_OUTP  
  LDA Itempl
  jsr V_OUTP
  
  JSR XTRA_NextParam
  
  LDA #15						; Set our row
  JSR V_OUTP  
  LDA Itempl
  jsr V_OUTP
  
  RTS


; Function to PLOT or UNPLOT a pixel
  
XTRA_PLOT_F

  LDA #5						; Start with plot mode
  STA V_XTRA_PlotMode
  
  JSR XTRA_EVNM_F2FX
  
  LDA Itempl						; Get our plot/unplot value

  CMP #2						; Handle special bit pattern case
  BNE XTRA_NOT_Pattern_B
  
  LDA V_XTRA_PlotPattern
  CMP #$80						; Push bit 7 into the Carry flag
  ROL							; Rotate left: bits shift, Carry goes to b0
  STA V_XTRA_PlotPattern
  BIT #1
  BEQ XTRA_SetUnplotting				; Unplot if clear
  BRA XTRA_StartPlot_B					; Otherwise plot
  
XTRA_NOT_Pattern_B
  LDA Itempl
  BIT #1						; Use bit to decide if we are plotting or not on this pass.
  BEQ XTRA_SetUnplotting				; Unplot if 0, otherwise plot
  
  LDA #5						; Plotting case
  BRA XTRA_StartPlot_B
  
XTRA_SetUnplotting
  LDA #6						; Unplotting case
  STA V_XTRA_PlotMode
 
XTRA_StartPlot_B
  JSR XTRA_NextParam
  
  LDA Itempl						; Save our X coordinate
  STA V_XTRA_Xcoord
  
  JSR XTRA_NextParam
  
  LDA Itempl						; Save our Y coordinate
  STA V_XTRA_Ycoord


; Function to actually PLOT/UNPLOT.
;
XTRA_SystemPlot_F

  LDA V_XTRA_Config					; Skip all bounds checks. This is a speed thing.
  BIT #XTRA_CFG_NoChecks_b
  BNE XTRA_PLOT_NoChecks_B
  
  BIT #XTRA_CFG_capped_b				; Either cap PLOTs within bounds or not.
  BEQ XTRA_Plot_NoCap_B

  LDA V_XTRA_Xcoord					; Bounds check the X coordinate.
  CLC
  ADC #[255-159]
  BCC XTRA_PLOT_Xgood_B

  LDA #159						; ...adjusting as necessary.
  STA V_XTRA_Xcoord

XTRA_PLOT_Xgood_B
  
  LDA V_XTRA_Ycoord  					; Bounds check the Y coordinate.
  CLC
  ADC #[255-99]
  BCC XTRA_PLOT_Ygood_B

  LDA #99						; ...adjusting as necessary.
  STA V_XTRA_Ycoord

XTRA_PLOT_Ygood_B

XTRA_Plot_NoCap_B

  LDA V_XTRA_Xcoord
  
  CLC							; Bounds check the X coordinate.
  ADC #[255-159]
  BCS XTRA_PLOT_OutOfBounds
  
  LDA V_XTRA_Ycoord
  							; Bounds check the Y coordinate.
  ADC #[255-99]
  BCS XTRA_PLOT_OutOfBounds
  
XTRA_PLOT_NoChecks_B
  
  LDA V_XTRA_PlotMode					; Write our plot command
  JSR V_OUTP
    
  LDA V_XTRA_Xcoord					; Write our X co-ordinate
  JSR V_OUTP
  
  LDA V_XTRA_Ycoord					; Write our Y co-ordinate
  JSR V_OUTP

XTRA_EndPlot  
  RTS

XTRA_PLOT_OutOfBounds

  LDA V_XTRA_Config					; Handle the silent case of out of bounds when
  BIT #XTRA_CFG_silent_b				; capping and unchecked aren't set.
  BNE XTRA_EndPlot

  JMP LAB_FCER
  

; Function to draw a line from (x1,y1) to (x2,y2)

XTRA_LINE_F

  LDA #XTRA_DefaultPlot_C
  STA V_XTRA_Config
  LDA #1
  STA V_LINE_PlotMode

  JSR XTRA_EVNM_F2FX
  LDA Itempl
  STA V_LINE_x1

  JSR XTRA_NextParam
  LDA Itempl
  STA V_LINE_y1

  JSR XTRA_NextParam
  LDA Itempl
  STA V_LINE_x2

  JSR XTRA_NextParam
  LDA Itempl
  STA V_LINE_y2

  LDY #0
  LDA (Bpntrl),Y
  CMP #$2C
  BNE XTRA_LINE_NoMode

  JSR LAB_IGBY
  JSR XTRA_EVNM_F2FX
  LDA Itempl
  STA V_LINE_PlotMode
  BRA XTRA_LINE_ModeSet

XTRA_LINE_NoMode
  LDA #1
  STA V_LINE_PlotMode

XTRA_LINE_ModeSet
  LDA V_LINE_PlotMode
  CMP #2
  BEQ XTRA_LINE_AfterMode
  CMP #1
  BNE XTRA_LINE_SetUnplot
  LDA #5
  BRA XTRA_LINE_SetPlotMode
XTRA_LINE_SetUnplot
  LDA #6
XTRA_LINE_SetPlotMode
  STA V_XTRA_PlotMode
  BRA XTRA_LINE_AfterMode

XTRA_LINE_AfterMode

  LDA V_LINE_x2
  SEC
  SBC V_LINE_x1
  BCS XTRA_LINE_dx_pos
  EOR #$FF
  ADC #1
  LDX #$FF
  .byte $2C
XTRA_LINE_dx_pos
  LDX #1
  STA V_LINE_dx
  STX V_LINE_sx

  LDA V_LINE_y2
  SEC
  SBC V_LINE_y1
  BCS XTRA_LINE_dy_pos
  EOR #$FF
  ADC #1
  LDX #$FF
  .byte $2C
XTRA_LINE_dy_pos
  LDX #1
  STA V_LINE_dy
  STX V_LINE_sy

  LDA V_LINE_dx
  CMP V_LINE_dy
  BCS XTRA_LINE_not_steep

  LDA V_LINE_dy
  LSR
  STA V_LINE_errL
  LDA #0
  STA V_LINE_errH

XTRA_LINE_steep_loop
  LDA V_LINE_x1
  STA V_XTRA_Xcoord
  LDA V_LINE_y1
  STA V_XTRA_Ycoord
  JSR XTRA_LINE_PlotPixel_F

  LDA V_LINE_y1
  CMP V_LINE_y2
  BNE XTRA_LINE_steep_cont
  JMP XTRA_LINE_done
XTRA_LINE_steep_cont

  CLC
  LDA V_LINE_y1
  ADC V_LINE_sy
  STA V_LINE_y1

  SEC
  LDA V_LINE_errL
  SBC V_LINE_dx
  STA V_LINE_errL
  LDA V_LINE_errH
  SBC #0
  STA V_LINE_errH
  BPL XTRA_LINE_steep_loop

  CLC
  LDA V_LINE_x1
  ADC V_LINE_sx
  STA V_LINE_x1

  CLC
  LDA V_LINE_errL
  ADC V_LINE_dy
  STA V_LINE_errL
  LDA V_LINE_errH
  ADC #0
  STA V_LINE_errH

  JMP XTRA_LINE_steep_loop

XTRA_LINE_not_steep
  LDA V_LINE_dx
  LSR
  STA V_LINE_errL
  LDA #0
  STA V_LINE_errH

XTRA_LINE_flat_loop
  LDA V_LINE_x1
  STA V_XTRA_Xcoord
  LDA V_LINE_y1
  STA V_XTRA_Ycoord
  JSR XTRA_LINE_PlotPixel_F

  LDA V_LINE_x1
  CMP V_LINE_x2
  BEQ XTRA_LINE_done

  CLC
  LDA V_LINE_x1
  ADC V_LINE_sx
  STA V_LINE_x1

  SEC
  LDA V_LINE_errL
  SBC V_LINE_dy
  STA V_LINE_errL
  LDA V_LINE_errH
  SBC #0
  STA V_LINE_errH
  BPL XTRA_LINE_flat_loop

  CLC
  LDA V_LINE_y1
  ADC V_LINE_sy
  STA V_LINE_y1

  CLC
  LDA V_LINE_errL
  ADC V_LINE_dx
  STA V_LINE_errL
  LDA V_LINE_errH
  ADC #0
  STA V_LINE_errH

  JMP XTRA_LINE_flat_loop

XTRA_LINE_done
  RTS


; Plot a pixel during LINE command, handling mode 2 (bit pattern)
;
XTRA_LINE_PlotPixel_F
  LDA V_LINE_PlotMode
  CMP #2
  BEQ XTRA_LINE_PatternPlot
  JMP XTRA_SystemPlot_F

XTRA_LINE_PatternPlot
  LDA V_XTRA_PlotPattern
  CMP #$80
  ROL
  STA V_XTRA_PlotPattern
  BIT #1
  BEQ XTRA_LINE_PatUnplot
  LDA #5
  BRA XTRA_LINE_PatStore

XTRA_LINE_PatUnplot
  LDA #6

XTRA_LINE_PatStore
  STA V_XTRA_PlotMode
  JMP XTRA_SystemPlot_F


; BASIC Commands for SPI.

I2C_Start_BAS
  JMP I2C_Start

I2C_Stop_BAS
  JMP I2C_Stop
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

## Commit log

2018-06-14 First upload of project
    [6502 Based Board.brd, 6502 Based Board.sch, ANSI Mono vid board.brd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]
2018-06-18 Corrected text on schematic to refer to JP2 rather than JP1.
    [ANSI Mono vid board.sch]
2018-06-26 Updated the processor board to add the following features:-
    Added a header for NMI and IRQ status lights.
    Reworked the circuit and added a header to allow 1, 2 and 4MHz clock speeds from the on-board oscillator.
    [6502 Based Board.brd, 6502 Based Board.sch]
2018-07-23 Updated the basic with Klaus2m5's patches to eradicate a couple of bugs.
    Bug 1: if two strings are equal then in direct mode they aren't!!
    Bug 2: BASIC can't find the corresponding FOR to the encountered NEXT in some instances. The same applies with DO LOOPs
    ToE_Mon.asm updated to reflect the current ROM build version.
    [ToE_Mon.asm]
2018-08-11 Got fed up with having to remove or replace all the line-feed chars in text files being sent to the ToE, so I've added a filter to the serial port.
    This is on by default but can be switched off by clearing bit 0 at $5E1 on the ToE, or by re-assembling with different defaults.
    [ToE_Mon.asm]
2018-08-26 Small but significant error found in ToE_Mon.asm. The vector addresses listed were only counting 2 instead of 3 bytes.
    Rewritten TPBCARD TPB_tx_byte routine as the original was ugly in most ways.
    This has improved timings as a result.
    [TPBCARD.asm, ToE_Mon.asm]
2018-08-26 BUGFIX: Moved Ibuffs to 0x800 and Ram_base to make room for more features. I forgot last time. Oops!
    New feature: Now the TPB card has a routine to transmit a block of bytes.
    Update: New prebuilt ROM images to reflect recent changes.
    [TPBCARD.asm, ToE_Mon.asm]
2018-09-08 Added some underlying Tower Peripheral Bus functions to support it's use. These offer byte and block transfers. Also there's a part written function to determine which devices are calling for attenti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
2018-09-09 Number of small bugs fixed and another TPB feature added. This feature allows sending a message to a device to see if it responds.
    Also, made a little more room for the TPB card's up-and-coming features.
    [TPBCARD.asm, ToE_Mon.asm]
2021-09-04 Great big update after far too long. Sorry to all those who waited patiently...
    [TAPE_IO.asm, TPBCARD.asm, ToE_Mon.asm]
2021-09-05 Updated to have a formal Timer IRQ. Currently this is T1 on the W65C22 on the GPIO card, so if you want to use it that card must be present.
    The prebuilt ROM ToEVID.bin uses this card at 0xC040.
    A couple of minor whoopsies have been fixed as well.
    [6502 Based Board.brd, ANSI Mono vid board.brd, ANSI Mono vid board.sch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]
2021-09-12 Added a file verify feature to the ToE. This led to the discovery of a couple of bugs in previous code, so that has been updated too.
    The manual has been adjusted accordingly, though this is still very much a
    work-in-progress. It should always be complimented with the source code.
    [TAPE_IO.asm, ToE_Mon.asm]
2021-09-18 Small bug squash update. Tape file names are supposed to be upto 16 chars.
    [TAPE_IO.asm]
2021-09-19 The TowerTAPE filing system now checks to see what file type it is loading.
    This means that it now displays what type it is and doesn't load the wrong type.
    Also, there is a new field in the header at the start which must contain 'HEAD'.
    This is to prevent misidentification of other byte streams as headers.
    Other minor tidy-up operations have also occurred.
    [TAPE_IO.asm]
2021-10-04 I somehow miscalculated the header size, upsetting the checksum byte.
    This only manifests after a cold boot so wasn't spotted immediately.
    SORRY! All fixed now.
    [TAPE_IO.asm, ToE_Mon.asm]
2021-10-31 Updated documentation and fixed a slight bug (Oops)
    [TAPE_IO.asm, ToE_Mon.asm]
2023-03-17 Big update. It's been a while, as I've been a very poorly lady. Note, I'm in the middle of a transition having nearly died so don't expect all the documentation to contain my new name of Jennifer Gun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
    [AY Card V1.stl, Adapter.FCStd, Assembly Model.FCStd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]
2023-05-21 General housekeeping
    [AY Card V1.stl, Assembly Model.FCStd, Backplate.stl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]
2023-05-27 Enhancement to the TowerTAPE Filing System.
    BASIC files that have a filename starting with a '!' now autorun.
    Failing to load successfully is now handled with more responsibly.
    There is a new system variable for controlling the TowerTAPE FS,
    though currently there's only one meaninful bit to play with.
    Updated PDF document.
    ...Finally, this is an ongoing work of hobby nature and as such odd
    things may be encountered. Don't be shy, just drop me a message.
    Kind regards and love,
    JennyDigital.
    [TAPE_IO.asm, ToE_Mon.asm]
2023-05-29 Make TowerBASIC smaller by removing the broken IRQ and NMI BASIC support.
    This is for two reasons:-
    1. There is a different IRQ handling system already implemented by me and being worked on
    2. The ROM space is precious for other ideas.
    [SPI_Lib.asm, TAPE_IO.asm, TPBCARD.asm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]
2023-05-29 Added a new command: SPI_INIT mode,MOSI,MISO,SCK,SS,SS_ActiveLvl Added a new function: byte_in = SPI_XFER(byte_out)
    Fixed a serious bug with the SPI engine where it would receive $FF no
    matter what.
    [SPI_Lib.asm, ToE_Mon.asm]
2023-06-01 Found and fixed a bug in BASICs SWAP command.
    For some reason it would only swap invalid arguments.
    [ToE_Mon.asm, XTRA_BASIC.asm]
2023-06-03 Implemented some changes to the tape filing system to support execution of loaded binary files with a flag to switch this off if necessary.
    Implemented some changes to TowerBASIC
    1) Added some exta code and patched a SADD, VARPTR and DEEK to return
    unsigned integers
    2) Minor bugfixes.
    [TAPE_IO.asm, ToE_Mon.asm]
2023-06-10 A little bit of a tidy up.
    [Video Card Faceplate.stl]
2023-06-18 Found a bug in the SOUND command which affected noise. Fixed now.
    [TAPE_IO.asm, ToE_Mon.asm]
2025-12-22 It's been a while, let's kick things off with my current ROM
    [6502 Based Board.brd, ANSI Mono vid board.brd, ANSI Mono vid board.sch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]
2025-12-25 FIX: Adjuted initialisation to for Wrong vector value intitialised for IRQ at startup FIX: ACIA2 had incorrect vector address!
    [ToE_Mon.asm]
2025-12-25 Fixed a few bugs and stripped out the load at recorded address feature I couldn't make work.
    [TAPE_IO.asm, ToE_Mon.asm]
2026-05-10 Bug fix in SPI SS pin handling
    [SPI_Lib.asm, ToE_Mon.asm]
2026-05-11 BUGFIX: Incorrect table meant the wrong keyword was being printed
    [LM77_Grapher.bas, TimeTempLib.bas]
2026-05-11 FIX: Decrement in F_TAPE_BlockOut happens in the correct place now.
    [TAPE_IO.asm]
2026-05-11 FIX: Improved timing tolerances on tape routines.
    [TAPE_IO.asm]
2026-05-12 FIX: Somewhere I managed to break LINE! It's back now though. Sorry!
    [TAPE_IO.asm, ToE_Mon.asm]
2026-05-12 FEATURE: LOAD and VERIFY for the binary case can now use the saved address rather than always specifying the load address by substituting '#' in it's place.
2026-05-12 FIX: Somehow, I had plot and unplot reversed after adding bit pattern plotting
    [ToE_Mon.asm, XTRA_BASIC.asm]
2026-05-12 FIX: LINE now properly respects the bit pattern when in mode 2.
    [ToE_Mon.asm, XTRA_BASIC.asm]
2026-05-12 REFACTOR: Made the printing in TAPE_IO.asm smaller to save EEPROM space.
2026-05-13 FIX: Improved behaviour of the AY system with a bugfix. Also saved 5 bytes.
    [ToE_Mon.asm]
2026-05-13 FIX: Bug squash in CenTPB.asm. 1) Strobe Ack wait fixed 2) Comment typo fixed.
    REFACTOR: Minor memory saving of 19 bytes. Not a lot, but this is an 8-bit
    system with limited resources after all.
    [ToE_Mon.asm]
2026-05-13 FIX: Improved filtering for ACIA inputs (mainly for the keyboard.)
    [ToE_Mon.asm]
2026-05-13 FIX: Keyboard interface now shows the correct caps lock state on starting FIX: Keybaord interface now givea the keyboard 500mS to wake up before starting FIX: Race condition in keyboard code fixed. F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
    [SBCInterface.c]
2026-05-13 FEATURE: PRINT can now accept #n where n is the value that sets which output streams to send the output to.

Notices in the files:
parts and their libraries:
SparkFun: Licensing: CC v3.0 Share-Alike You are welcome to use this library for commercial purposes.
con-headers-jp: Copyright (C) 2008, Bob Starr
